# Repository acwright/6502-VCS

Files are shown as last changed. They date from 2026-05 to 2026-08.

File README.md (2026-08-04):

6502-VCS
========

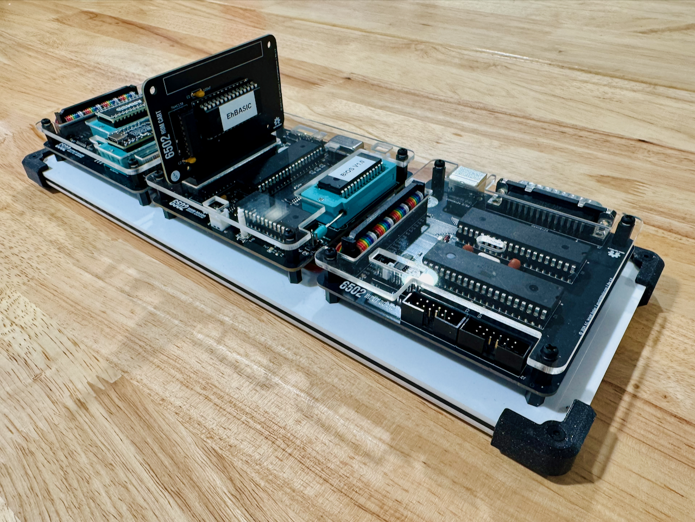
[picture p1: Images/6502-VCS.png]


An **AC6502** retro-style 8-bit computer based on the **65C02** microprocessor.

> 📖 **Guide:** [AC6502 Documentation](https://acwright.github.io/6502-DOCS/) — the user's and programmer's guide for the whole family.
> See [VCS's page in the family appendix](https://acwright.github.io/6502-DOCS/family/vcs).

---

## Table of Contents

- [Overview](#overview)
- [Architecture](#architecture)
- [Systems](#systems)
- [Software](#software)
- [Hardware](#hardware)
  - [Main Board](#main-board)
    - [Revision History](#revision-history)
  - [Input Board](#input-board)
  - [Output Board](#output-board)
  - [ROM Cart](#rom-cart)
- [Firmware](#firmware)
  - [IB Controller](#ib-controller)
- [CAD](#cad)
- [Production](#production)
- [Schematics](#schematics)
- [Libraries](#libraries)
- [Bill of Materials](#bill-of-materials)
  - [Main Board](#main-board-1)
  - [Input Board](#input-board-1)
  - [Output Board](#output-board-1)
  - [ROM Cart (Rev 1.0a)](#rom-cart-rev-10a)
  - [ROM Cart (Rev 1.0b)](#rom-cart-rev-10b)
- [License](#license)

---

## Overview

The AC6502 ecosystem is a family of open-source, 65C02-based computers sharing a common architecture, memory map, and [BIOS](https://github.com/acwright/6502-BIOS). Each computer in the family is purpose-built for a different use case but runs the same software and firmware.

The **VCS** is a cartridge-based retro gaming console. It features a real 65C02 CPU, swappable ROM cartridges, VGA video output via [Pico9918](https://github.com/visrealm/pico9918), SID audio via ARMSID, and support for PS/2 keyboards, matrix keyboards, and Atari 2600-compatible joysticks.

## Architecture

All AC6502 computers share:

- **CPU**: 65C02 (or accurate emulation)
- **Memory**: 32KB RAM + 32KB ROM, with optional banked RAM expansion
- **Memory Map**: Standardized across the ecosystem — zero page, stack, I/O space ($8000–$9FFF), system ROM, and interrupt vectors at $FFFA–$FFFF
- **Bus**: 16-bit address bus, 8-bit bidirectional data bus, standard 65C02 control signals (RW, PHI2, RESET, IRQ, NMI, RDY, SYNC)
- **BIOS**: A common [BIOS](https://github.com/acwright/6502-BIOS) provides the kernel, monitor, and BASIC interpreter across all systems

## Systems

| Project | Description |
|---|---|
| [6502-ACE](https://github.com/acwright/6502-ACE) | All-in-one Computer Experience — A single board computer |
| [6502-COB](https://github.com/acwright/6502-COB) | Computer On a Backplane — Modular desktop computer with expandable card slots |
| [6502-DEV](https://github.com/acwright/6502-DEV) | Development Environment Vehicle — Emulation-based dev system |
| [6502-KIM](https://github.com/acwright/6502-KIM) | Keypad Input Monitor - KIM-1 inspired minimal computer |
| [6502-VCS](https://github.com/acwright/6502-VCS) | Video Computer System — Cartridge-based retro gaming console (YOU ARE HERE) |

## Software

| Project | Description |
|---|---|
| [6502-BIOS](https://github.com/acwright/6502-BIOS) | The shared BIOS (kernel, monitor, BASIC) for all AC6502 computers |
| [6502-EMULATOR](https://github.com/acwright/6502-EMULATOR) | Emulator for the whole family — desktop app, browser build, and a command line for scripted runs |
| [6502-PRG](https://github.com/acwright/6502-PRG) | Template project for writing assembly language programs |
| [6502-CRT](https://github.com/acwright/6502-CRT) | Template project for writing assembly language cartridges |
| [6502-ASM](https://github.com/acwright/6502-ASM) | Assembly language example programs and demos |
| [6502-BAS](https://github.com/acwright/6502-BAS) | BASIC program listings |
| [6502-WOZMON](https://github.com/acwright/6502-WOZMON) | Wozmon as a standalone ROM |
| [6502-NOP](https://github.com/acwright/6502-NOP) | An all-NOP ROM, for probing a board during bring-up |
| [6502-DOCS](https://github.com/acwright/6502-DOCS) | The documentation site — the guide, the printable reference cards, branding and label artwork |
| [cffs](https://github.com/acwright/cffs) | Builds CompactFlash disk images for the BIOS filesystem |
| [bastok](https://github.com/acwright/bastok) | Tokenizes BASIC listings into `.prg` images, and back |
| [bin2woz](https://github.com/acwright/bin2woz) | Converts a binary into a Wozmon serial upload |

## Hardware

This repository contains KiCad 7.0+ PCB designs for the three boards that make up the VCS system.

### Main Board
`Hardware/Main Board/`

The core board containing the 65C02 CPU, 32KB SRAM, 32KB EEPROM, clock, and reset circuitry. Runs at 1 MHz and provides the bus connection for the Input and Output boards.

#### Revision History

**Rev 1.1**

- Pull-up resistors changed from 1kΩ to 10kΩ.

**Rev 1.0**

- Initial release.

### Input Board
`Hardware/Input Board/`

Unified input board supporting a matrix keyboard, PS/2 keyboard, and Atari 2600-compatible joysticks. Uses a 65C22 VIA and an ATmega1284p microcontroller as the keyboard encoder controller.

The joysticks share the VIA ports with the keyboard encoder rather than having connectors of their own: they come in on the `J1` PORT B and `J2` PORT A box headers, with `JOY(1)` reading PORT B and `JOY(2)` reading PORT A. See [Joystick Interface](./Firmware/IB%20Controller/README.md#joystick-interface) for the wiring options and the bitmask the BIOS returns.

### Output Board
`Hardware/Output Board/`

Combined VGA video output (via Raspberry Pi Pico running [Pico9918](https://github.com/visrealm/pico9918)) and SID audio output (via ARMSID). Provides TMS9918A-compatible graphics modes at 640×480 VGA and 3-voice SID synthesis.

### ROM Cart
`Hardware/ROM Cart/`

Swappable ROM cartridge for the VCS system. Comes in two versions:

- **Rev 1.0a** — Uses the **28C256** 32KB EEPROM (electrically erasable, no UV eraser required).
- **Rev 1.0b** — Uses the **27C256** 32KB EPROM (UV-erasable).

## Firmware

This repository contains [PlatformIO](https://platformio.org/)-based firmware for the Input Board.

### IB Controller
`Firmware/IB Controller/`

Firmware for the ATmega1284p on the Input Board. Provides:

- Matrix keyboard scanning and encoding
- PS/2 keyboard interface
- Atari 2600-compatible joystick input
- Parallel I/O to the AC6502 bus via 65C22 VIA

See [Firmware/IB Controller/README.md](./Firmware/IB%20Controller/README.md) for setup and usage instructions.

## CAD
`CAD/`

3D-printable enclosure parts and laser-cut top panels for the VCS system.

## Production
`Production/`

JLCPCB-ready Gerber files and BOM/CPL for PCB fabrication and assembly.

## Schematics
`Schematics/`

PDF schematics for each board.

## Libraries
`Libraries/`

Shared KiCad symbol and footprint libraries used across all AC6502 hardware projects.

## Bill of Materials

### Main Board

| Reference | Qty | Value | Description | LCSC | DigiKey | Mouser | Other |
|---|-----|---|---|---|---|---|---|
| C1, C3–C11 | 10 | 100nF | Unpolarized capacitor | [C49678](https://www.lcsc.com/search?q=C49678) | | | |
| C2 | 1 | 10uF | Polarized capacitor | [C7171](https://www.lcsc.com/search?q=C7171) | | | |
| D1 | 1 | 1N5819 | Schottky Diode SOD-323F | [C191023](https://www.lcsc.com/search?q=C191023) | | | |
| D2 | 1 | LED | LED 0805 | [C2297](https://www.lcsc.com/search?q=C2297) | | | |
| J1 | 1 | PWR_SW | JST XH 1×2 | | [455-2247-ND](https://www.digikey.com/en/products/filter?keywords=455-2247-ND) | | |
| J2 | 1 | ROM WE | Pin Header 1×2 | | | | [AMAZON](https://www.amazon.com/Straight-Breakaway-Connector-Breadboard-Electronic/dp/B0FRZW75VS) |
| J3 | 1 | USB-C | USB 2.0 Type-C Receptacle | [C2988369](https://www.lcsc.com/search?q=C2988369) | | | |
| J4 | 1 | RESET_SW | JST XH 1×2 | | [455-2247-ND](https://www.digikey.com/en/products/filter?keywords=455-2247-ND) | | |
| J5 | 1 | HRDB EN | Pin Header 2×2 | | | | [AMAZON](https://www.amazon.com/Uxcell-Double-Straight-Header-Strip/dp/B00X77A472) |
| J6 | 1 | CLOCK_ENBL_SW | JST XH 1×2 | | [455-2247-ND](https://www.digikey.com/en/products/filter?keywords=455-2247-ND) | | |
| J7 | 1 | 6502 EN | Pin Header 1×2 | | | | [AMAZON](https://www.amazon.com/Straight-Breakaway-Connector-Breadboard-Electronic/dp/B0FRZW75VS) |
| J8 | 1 | EXP EN | Pin Header 2×5 | | | | [AMAZON](https://www.amazon.com/Uxcell-Double-Straight-Header-Strip/dp/B00X77A472) |
| J9 | 1 | 6502 Card Connector | Card Edge 2×20 | | [A31723-ND](https://www.digikey.com/en/products/filter?keywords=A31723-ND) | [571-5-5530843-4](https://www.mouser.com/ProductDetail/571-5-5530843-4) | |
| J10 | 1 | 6502 Bus | Bus Connector 2×20 | | | | [AMAZON](https://www.amazon.com/Female-Headers-Connector-Header-Raspberry/dp/B07DNHS2SJ) |
| Q1 | 1 | SS8050 | NPN Transistor SOT-23 | [C2150](https://www.lcsc.com/search?q=C2150) | | | |
| R1, R4, R9 | 3 | 1k | Resistor | [C17513](https://www.lcsc.com/search?q=C17513) | | | |
| R10–R14 | 5 | 10k | Resistor | [C2930231](https://www.lcsc.com/search?q=C2930231) | | | |
| R2 | 1 | 1M | Resistor | [C17514](https://www.lcsc.com/search?q=C17514) | | | |
| R3 | 1 | 47k | Resistor | [C17713](https://www.lcsc.com/search?q=C17713) | | | |
| R5, R6 | 2 | 5.1k | Resistor | [C27834](https://www.lcsc.com/search?q=C27834) | | | |
| R7 | 1 | 330 | Resistor | [C17630](https://www.lcsc.com/search?q=C17630) | | | |
| R8 | 1 | 10k | Resistor | [C17414](https://www.lcsc.com/search?q=C17414) | | | |
| SW1 | 1 | Reset | Push Button | [C318884](https://www.lcsc.com/search?q=C318884) | | | |
| U1 | 1 | LM555xM | Timer SOIC-8 | [C7593](https://www.lcsc.com/search?q=C7593) | | | |
| U2 | 1 | AS6C62256 | SRAM DIP-28 | | [1450-1033-ND](https://www.digikey.com/en/products/filter?keywords=1450-1033-ND) | [913-AS6C62256-55PCN](https://www.mouser.com/ProductDetail/913-AS6C62256-55PCN) | |
| U3 | 1 | AT28C256 | EEPROM DIP-28 | | [AT28C256-15PU-ND](https://www.digikey.com/en/products/filter?keywords=AT28C256-15PU-ND) | [556-AT28C25615PU](https://www.mouser.com/ProductDetail/556-AT28C25615PU) | |
| U4, U5, U7 | 3 | 74HC00 | Quad NAND SOIC-14 | [C5586](https://www.lcsc.com/search?q=C5586) | | | |
| U6 | 1 | 65C02 | CPU DIP-40 | | | [955-W65C02S6TPG-14](https://www.mouser.com/ProductDetail/955-W65C02S6TPG-14) | |
| X1 | 1 | OCXO-14 | Crystal Oscillator DIP-14 | | [X937-ND](https://www.digikey.com/en/products/filter?keywords=X937-ND) | | |

### Input Board

| Reference | Qty | Value | Description | LCSC | DigiKey | Mouser | Other |
|---|-----|---|---|---|---|---|---|
| C1, C3, C5–C8 | 6 | 100nF | Unpolarized capacitor | [C49678](https://www.lcsc.com/search?q=C49678) | | | |
| C2, C4 | 2 | 22pF | Unpolarized capacitor | [C107114](https://www.lcsc.com/search?q=C107114) | | | |
| D1 | 1 | 1N914 | Schottky Diode | | [1N914FS-ND](https://www.digikey.com/en/products/filter?keywords=1N914FS-ND) | | |
| J1 | 1 | PORT B | Box Header 2×6 | | [2057-BHR-12-VUA-ND](https://www.digikey.com/en/products/filter?keywords=2057-BHR-12-VUA-ND) | | [AMAZON](https://www.amazon.com/uxcell-2-54mm-2x6-Pin-Straight-Connector/dp/B07DJYVZV2) |
| J2 | 1 | PORT A | Box Header 2×6 | | [2057-BHR-12-VUA-ND](https://www.digikey.com/en/products/filter?keywords=2057-BHR-12-VUA-ND) | | [AMAZON](https://www.amazon.com/uxcell-2-54mm-2x6-Pin-Straight-Connector/dp/B07DJYVZV2) |
| J3 | 1 | PS/2 KEYBOARD | 6-pin Mini-DIN | | | [806-KMDGX-6S-BS](https://www.mouser.com/ProductDetail/806-KMDGX-6S-BS) | [AMAZON](https://www.amazon.com/dp/B08GS3QL7T) |
| J4 | 1 | 6502 Bus | Bus Connector 2×20 | | | | [AMAZON](https://www.amazon.com/Female-Headers-Connector-Header-Raspberry/dp/B07DNHS2SJ) |
| J5 | 1 | KEYBOARD | DB-25 Connector | | [609-1505-ND](https://www.digikey.com/en/products/filter?keywords=609-1505-ND) | | |
| J6 | 1 | IO SELECT | Pin Header 2×8 | | | | [AMAZON](https://www.amazon.com/Uxcell-Double-Straight-Header-Strip/dp/B00X77A472) |
| R1 | 1 | 1K | Resistor | [C17513](https://www.lcsc.com/search?q=C17513) | | | |
| U1 | 1 | 65C22 | VIA DIP-40 | | | [955-W65C22N6TPG-14](https://www.mouser.com/ProductDetail/955-W65C22N6TPG-14) | |
| U2 | 1 | ATmega1284-P | MCU DIP-40 | | [ATMEGA1284-PU-ND](https://www.digikey.com/en/products/filter?keywords=ATMEGA1284-PU-ND) | [556-ATMEGA1284-PU](https://www.mouser.com/ProductDetail/556-ATMEGA1284-PU) | |
| U3 | 1 | 74HC138 | Decoder SOIC-16 | [C5602](https://www.lcsc.com/search?q=C5602) | | | |
| Y1 | 1 | 16 MHz | Crystal HC49-U | | [3155-16M20P2/49US-ND](https://www.digikey.com/en/products/filter?keywords=3155-16M20P2/49US-ND) | | |

> **Joysticks**: there is no DB-9 in this BOM because the board does not carry one. The joysticks share the VIA ports with the keyboard encoder and connect through the `J1` PORT B and `J2` PORT A box headers, using a helper board from the [6502-COB](https://github.com/acwright/6502-COB) project — the **GPIO Helper** for a direct box-header connection, or the **Joystick Helper** to convert a port to a DB-9 with pull-ups fitted. Budget for one helper per stick.

### Output Board

| Reference | Qty | Value | Description | LCSC | DigiKey | Mouser | Other |
|---|-----|---|---|---|---|---|---|
| C1 | 1 | 1uF | Capacitor | [C28323](https://www.lcsc.com/search?q=C28323) | | | |
| C2, C3 | 2 | 2.2nF | Capacitor | [C28260](https://www.lcsc.com/search?q=C28260) | | | |
| C5–C10 | 6 | 100nF | Unpolarized capacitor | [C49678](https://www.lcsc.com/search?q=C49678) | | | |
| D1 | 1 | 1N914 | Schottky Diode | | [1N914FS-ND](https://www.digikey.com/en/products/filter?keywords=1N914FS-ND) | | |
| J1 | 1 | VDD | JST XH 1×2 | | [455-2247-ND](https://www.digikey.com/en/products/filter?keywords=455-2247-ND) | | |
| J2 | 1 | AUDIO | RCA Connector | | [PJRAN1X1U02X-ND](https://www.digikey.com/en/products/filter?keywords=PJRAN1X1U02X-ND) | | |
| J6 | 1 | INT Select | Pin Header 1×3 | | | | [AMAZON](https://www.amazon.com/Straight-Breakaway-Connector-Breadboard-Electronic/dp/B0FRZW75VS) |
| J7 | 1 | IO SELECT | Pin Header 2×8 | | | | [AMAZON](https://www.amazon.com/Uxcell-Double-Straight-Header-Strip/dp/B00X77A472) |
| J8 | 1 | 6502 Bus | Bus Connector 2×20 | | | | [AMAZON](https://www.amazon.com/Female-Headers-Connector-Header-Raspberry/dp/B07DNHS2SJ) |
| R1 | 1 | 1k | Resistor | [C17513](https://www.lcsc.com/search?q=C17513) | | | |
| U1 | 1 | Pico9918A | Video Chip DIP-40 | | | | [LINK](https://www.tindie.com/products/visrealm/pico9918-pro/) |
| U2 | 1 | 6581 | SID Chip DIP-28 | | | | [LINK](https://retrocomp.cz/produkt?id=2) |
| U3, U4 | 2 | 74HC138 | Decoder SOIC-16 | [C5602](https://www.lcsc.com/search?q=C5602) | | | |

### ROM Cart (Rev 1.0a)

| Reference | Qty | Value | Description | DigiKey | Mouser | Other |
|---|-----|---|---|---|---|---|
| C1, C2 | 2 | 100nF | Capacitor | [478-5732-ND](https://www.digikey.com/en/products/filter?keywords=478-5732-ND) | | [AMAZON](https://www.amazon.com/PANMILED-Multilayer-Monolithic-Capacitors-Assortment/dp/B0CYQ1Z4G5) |
| U1 | 1 | AT28C256 | EEPROM DIP-28 | [AT28C256-15PU-ND](https://www.digikey.com/en/products/filter?keywords=AT28C256-15PU-ND) | [556-AT28C25615PU](https://www.mouser.com/ProductDetail/556-AT28C25615PU) | |
| U2 | 1 | 74HC138 | Decoder DIP-16 | [296-1575-5-ND](https://www.digikey.com/en/products/filter?keywords=296-1575-5-ND) | [595-SN74HC138N](https://www.mouser.com/ProductDetail/595-SN74HC138N) | |

### ROM Cart (Rev 1.0b)

| Reference | Qty | Value | Description | DigiKey | Mouser | Other |
|---|-----|---|---|---|---|---|
| C1, C2 | 2 | 100nF | Capacitor | [478-5732-ND](https://www.digikey.com/en/products/filter?keywords=478-5732-ND) | | [AMAZON](https://www.amazon.com/PANMILED-Multilayer-Monolithic-Capacitors-Assortment/dp/B0CYQ1Z4G5) |
| U1 | 1 | AT27C256 | EPROM DIP-28 | [AT27C256R-70PU-ND](https://www.digikey.com/en/products/filter?keywords=AT27C256R-70PU-ND) | | [LINK](https://www.jameco.com/z/AM27C256-255DC-Advanced-Micro-Devices-IC-27C256-25-EPROM-256K-Bit-250ns-CMOS-UV-Electrically-Programmable-ROM_39731.html) |
| U2 | 1 | 74HC138 | Decoder DIP-16 | [296-1575-5-ND](https://www.digikey.com/en/products/filter?keywords=296-1575-5-ND) | [595-SN74HC138N](https://www.mouser.com/ProductDetail/595-SN74HC138N) | |

## License

Hardware designs are released under the [CERN Open Hardware Licence Version 2 – Permissive](https://ohwr.org/cern_ohl_p_v2.txt).  
Firmware is released under the [MIT License](./Firmware/IB%20Controller/LICENSE).

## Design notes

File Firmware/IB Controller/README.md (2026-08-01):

# IB Controller

## Overview

The IB (Input Board) Controller is firmware for the ATMega1284P microcontroller that provides dual keyboard input support for 6502-based computer systems. It can simultaneously handle both PS/2 keyboard input and custom keyboard matrix input, converting keypresses to ASCII codes and outputting them through a 6522 VIA (Versatile Interface Adapter) interface.

## Features

- **Dual Input Support**: Handles both PS/2 keyboards and 8x8 keyboard matrix simultaneously
- **ASCII Conversion**: Converts PS/2 scancodes and matrix keypresses to ASCII characters
- **Always Uppercase Letters**: Letters are always output as uppercase ASCII regardless of modifiers
- **Modifier Keys**: Shift (symbols/numbers only) and Ctrl (control codes)
- **Buffered Input**: Uses circular buffers to prevent data loss during rapid typing
- **Debounced Matrix Scanning**: Hardware debouncing for reliable matrix keyboard operation
- **Enable/Disable Control**: Independent enable signals for PS/2 and matrix inputs
- **Shared Joystick Ports**: Releases PORT A / PORT B when disabled so the 6502 can read the two Atari 2600-compatible joysticks that share those ports

## Hardware Connections

### ATMega1284P Pin Assignments

#### VIA PORT A (Pins 24-31)
Used for row scanning (matrix mode) or ASCII output (PS/2 mode):
- PA0 (Pin 24) - VIA_PA0 / Row 0 / Data Bit 0
- PA1 (Pin 25) - VIA_PA1 / Row 1 / Data Bit 1
- PA2 (Pin 26) - VIA_PA2 / Row 2 / Data Bit 2
- PA3 (Pin 27) - VIA_PA3 / Row 3 / Data Bit 3
- PA4 (Pin 28) - VIA_PA4 / Row 4 / Data Bit 4
- PA5 (Pin 29) - VIA_PA5 / Row 5 / Data Bit 5
- PA6 (Pin 30) - VIA_PA6 / Row 6 / Data Bit 6
- PA7 (Pin 31) - VIA_PA7 / Row 7 / Data Bit 7

#### VIA PORT B (Pins 0-7)
Used for column scanning (matrix mode) or ASCII output (matrix output):
- PB0 (Pin 0) - VIA_PB0 / Column 0 / Data Bit 0
- PB1 (Pin 1) - VIA_PB1 / Column 1 / Data Bit 1
- PB2 (Pin 2) - VIA_PB2 / Column 2 / Data Bit 2
- PB3 (Pin 3) - VIA_PB3 / Column 3 / Data Bit 3
- PB4 (Pin 4) - VIA_PB4 / Column 4 / Data Bit 4
- PB5 (Pin 5) - VIA_PB5 / Column 5 / Data Bit 5
- PB6 (Pin 6) - VIA_PB6 / Column 6 / Data Bit 6
- PB7 (Pin 7) - VIA_PB7 / Column 7 / Data Bit 7

#### Control Signals
- Pin 8 (VIA_CA1) - PS/2 Data Ready strobe (output)
- Pin 9 (VIA_CA2) - PS/2 Enable (input, active low)
- Pin 10 (PS2CLK) - PS/2 Clock input
- Pin 11 (PS2DATA) - PS/2 Data input
- Pin 12 (VIA_CB1) - Matrix Data Ready strobe (output)
- Pin 13 (VIA_CB2) - Matrix Enable (input, active low)

### PS/2 Keyboard Interface

Connect a PS/2 keyboard to:
- **CLK**: Pin 10 (PS2CLK)
- **DATA**: Pin 11 (PS2DATA)
- **VCC**: +5V
- **GND**: Ground

### Keyboard Matrix Interface

The firmware supports an 8x8 keyboard matrix (64 keys maximum):
- **Rows**: Connected to PA0-PA7 (Pins 24-31)
- **Columns**: Connected to PB0-PB7 (Pins 0-7)

Each key connects a row to a column when pressed. The matrix is scanned with rows driven low and columns read with pull-ups.

### Joystick Interface

PORT A and PORT B are shared between this encoder and two Atari 2600-compatible
joysticks. The Input Board has no DB-9 connectors of its own — the sticks arrive
on the same 2×6 box headers that carry the VIA ports (`J1` PORT B, `J2` PORT A),
using either helper board from the [6502-COB](https://github.com/acwright/6502-COB)
project:

- **GPIO Helper** — box header to box header, for wiring a stick directly to a port.
- **Joystick Helper** — converts a port header to a DB-9 with the 1kΩ pull-ups
  fitted, which is where Atari 2600 compatibility comes from.

The BIOS reads the two sticks through those same ports:

| BIOS routine | BASIC | VIA port | Encoder released by |
|---|---|---|---|
| `ReadJoystick1` (`$A048`) | `JOY(1)` | PORT B | `CB2` high — matrix encoder off |
| `ReadJoystick2` (`$A04B`) | `JOY(2)` | PORT A | `CA2` high — PS/2 encoder off |

Each read returns the port raw, as a bitmask:

```
Bit:  7   6   5   4   3   2   1   0
      R   L   D   U   Y   X   B   A
```

The ports are **active low** — every line is pulled high and grounded by the
stick's switch — so a held button reads `0` and an untouched stick reads `$FF`.

This is the firmware's obligation in the joystick path: when `CA2` or `CB2`
goes high, it releases the corresponding port within 100 µs so the 6502 can
read the stick directly — the same arrangement a C64 has with a CIA port.
`disablePS2()` releases PORT A and `disableMatrix()` releases PORT B, both by
returning the pins to `INPUT_PULLUP` rather than bare `INPUT`. That matters
here in particular, since the Input Board has no pull-ups of its own — see the
helper board list above — so a port can legitimately be assembled with none
fitted at all.

The BIOS reads a stick as `KBDisable` → settle → read the port directly →
`KBEnable`. Nothing is transmitted over the shared lines, so there is nothing
for one stick to corrupt on the other's behalf — **both sticks read correctly
even when held at the same time.** An earlier design had the encoder push
joystick state to the 6502 as control bytes over the keyboard channel instead;
that could not report a held button on the port it was reporting over, and was
abandoned. See
[BIOS `PLAN.md` §2](https://github.com/acwright/6502-BIOS/blob/main/PLAN.md)
for the full account.

A cartridge that wants its own matrix scan, its own key repeat, or polling
faster than the encoder's rate can use the identical mechanism directly:
`KBDisable`, own the sixteen pins for as long as it likes, `KBEnable` when
done. It is not a separate escape hatch — it is what `ReadJoystick1/2` already
do on every call.

**Measured release latency: to be measured later.** This is the figure the
BIOS's `KBDisable` settle wait is sized against. Cycle-counting the compiled
firmware puts the worst-case code path at ~17 µs against a 100 µs budget, but
that excludes a PS/2 interrupt landing in the window and says nothing about how
long the bus takes to charge through a pull-up, so the published number comes
from a scope. See [PLAN.md](../../PLAN.md).

## Keyboard Matrix Layout

```
       PB0    PB1    PB2    PB3    PB4    PB5    PB6    PB7
PA0:    `      1      2      3      4      5      6      7
PA1:    8      9      0      -      =      BS     ESC    TAB
PA2:    Q      W      E      R      T      Y      U      I
PA3:    O      P      [      ]      \      INS    CAPS   A
PA4:    S      D      F      G      H      J      K      L
PA5:    ;      '    ENTER   DEL   SHIFT    Z      X      C
PA6:    V      B      N      M      ,      .      /      UP
PA7:  CTRL   MENU    ALT   SPACE   FN    LEFT   DOWN  RIGHT
```

**Special Keys:**
- BS = Backspace (0x08)
- ESC = Escape (0x1B)
- TAB = Tab (0x09)
- INS = Insert (0x1A)
- DEL = Delete (0x7F)
- ENTER = Enter (0x0D)
- Arrow keys: UP (0x1E), LEFT (0x1C), DOWN (0x1F), RIGHT (0x1D)

**Ignored Keys:**
- Caps Lock, Menu/GUI, Alt, Fn — produce no output and track no state

## Operation Modes

### PS/2 Mode
When VIA_CA2 (Pin 9) is pulled LOW:
- PS/2 keyboard is enabled
- Scancodes are converted to ASCII
- Output appears on PORT A (PA0-PA7)
- VIA_CA1 pulses low when data is ready

### Matrix Mode
When VIA_CB2 (Pin 13) is pulled LOW:
- Matrix keyboard is enabled
- Matrix is scanned every 10ms
- Keys are debounced (stable for 2 scans)
- Output appears on PORT B (PB0-PB7)
- VIA_CB1 pulses low when data is ready

### Dual Mode
Both keyboards can operate simultaneously if both enable signals are active.

### Joystick Reads
When an enable signal goes HIGH the firmware releases that port so the joystick
sharing it can be read by the 6502 — see [Joystick Interface](#joystick-interface).

## ASCII Character Mapping

### Modifier Priority

1. **Ctrl** — If held, produce control code. Shift is ignored.
2. **Shift** — If held (no Ctrl), produce shifted symbol. Letters unaffected.
3. **Base** — No modifier: produce base ASCII (letters always uppercase).

### Control Characters (Ctrl+Key)

- Ctrl+2 = 0x00 (NUL)
- Ctrl+A-Z = 0x01-0x1A
- Ctrl+[ = 0x1B (ESC)
- Ctrl+\ = 0x1C (FS)
- Ctrl+] = 0x1D (GS)
- Ctrl+6 = 0x1E (RS)
- Ctrl+- = 0x1F (US)

### Shifted Symbols

Shift only affects number and symbol keys (not letters):

| Base | Shifted | | Base | Shifted |
|---|---|-|---|---|
| 1 → ! | 2 → @ | | 3 → # | 4 → $ |
| 5 → % | 6 → ^ | | 7 → & | 8 → * |
| 9 → ( | 0 → ) | | - → _ | = → + |
| [ → { | ] → } | | \ → \| | ; → : |
| ' → " | , → < | | . → > | / → ? |
| ` → ~ | | | | |

### Printable Characters

Letters are always uppercase (A-Z). Numbers, symbols, space, and navigation keys follow standard ASCII.

## Build Instructions

### Prerequisites

1. **Install PlatformIO**
   ```bash
   # Using pip
   pip install platformio
   
   # Or install PlatformIO IDE extension for VS Code
   ```

2. **Install MiniPro Programmer Software** (for uploading)
   ```bash
   # macOS (using Homebrew)
   brew install minipro
   
   # Linux
   sudo apt-get install minipro
   
   # Or build from source: https://gitlab.com/DavidGriffith/minipro
   ```

### Building the Firmware

1. **Navigate to the project directory:**
   ```bash
   cd "Firmware/IB Controller"
   ```

2. **Build the firmware:**
   ```bash
   # Build for ATMega1284P (default)
   pio run -e atmega1284p
   
   # Or build for ATMega1284
   pio run -e atmega1284
   ```

3. **Build output:**
   The compiled firmware will be located at:
   ```
   .pio/build/atmega1284p/firmware.hex
   ```

### Uploading the Firmware

The project uses a MiniPro TL866 programmer for uploading.

1. **Connect the MiniPro programmer** to your ATMega1284P chip

2. **Upload firmware and fuses:**
   ```bash
   # Upload to ATMega1284P
   pio run -e atmega1284p -t upload
   
   # Or upload to ATMega1284
   pio run -e atmega1284 -t upload
   ```

3. **Manual upload (if needed):**
   ```bash
   # Flash the program
   minipro -p "ATMEGA1284P@DIP40" -c code -w .pio/build/atmega1284p/firmware.hex
   
   # Flash the fuses
   minipro -p "ATMEGA1284P@DIP40" -c config -w fuses.cfg --fuses
   ```

## Fuse Configuration

The `fuses.cfg` file contains the ATMega1284P fuse settings:

```properties
lfuse = 0xff   # Low fuse
hfuse = 0xff   # High fuse  
efuse = 0xff   # Extended fuse
lock = 0xff    # Lock bits (unprogrammed, not written)
```

**Fuse Settings:**
- **Low Fuse (0xFF)**: Low power crystal oscillator (8.0–16.0 MHz) for the
  on-board 16 MHz crystal (`Y1`), slowly-rising-power start-up (16K CK + 65 ms),
  no clock divide (CKDIV8 off), clock output disabled
- **High Fuse (0xFF)**: Default settings
- **Extended Fuse (0xFF)**: Default settings
- **Lock Bits (0xFF)**: No memory lock protection

> **Note**: The low fuse selects a *crystal* oscillator, which is what this board
> needs — the Input Board carries a 16 MHz HC49-U crystal across XTAL1/XTAL2.
> Full Swing is a different setting (`CKSEL3:1 = 011`) and is not used here. The
> ACE board's `AB Controller` runs from a full-can oscillator module instead and
> therefore uses the *external clock* setting (`lfuse = 0xE0`); the two are not
> interchangeable.

> **Note**: Lock bits are left unprogrammed on all of these boards. The upload
> command writes fuses only (`--fuses`, no `--lock`), so the `lock` line above is
> recorded for reference and never programmed.

⚠️ **Warning**: Incorrect fuse settings can brick your microcontroller. Verify fuse values are appropriate for your hardware configuration before programming.

## Dependencies

The firmware requires the following library (automatically installed by PlatformIO):

- **CircularBuffer** (v1.4.0+) by Roberto Lo Giacco
  - Provides interrupt-safe circular buffers for keyboard data

## Project Structure

```
IB Controller/
├── platformio.ini          # PlatformIO configuration
├── fuses.cfg              # AVR fuse configuration
├── src/
│   └── main.cpp           # Main firmware source code
├── include/               # Header files (if any)
├── lib/                   # Local libraries
└── test/                  # Unit tests
```

## Troubleshooting

### Build Issues

**Problem**: PlatformIO not found
```bash
# Solution: Install or update PlatformIO
pip install -U platformio
```

**Problem**: Library dependency errors
```bash
# Solution: Clean and rebuild
pio run -t clean
pio run
```

### Upload Issues

**Problem**: MiniPro not found
```bash
# Solution: Ensure minipro is installed and in PATH
which minipro
```

**Problem**: Chip not detected
- Check that the chip is properly seated in the programmer
- Verify you're using the correct chip model (ATMEGA1284P vs ATMEGA1284)
- Check for proper power supply to the programmer

### Runtime Issues

**Problem**: No keyboard response
- Verify enable signals (CA2/CB2) are at correct logic levels
- Check PS/2 clock and data connections
- Verify matrix keyboard connections
- Ensure VIA interface connections are correct

**Problem**: `JOY(1)`/`JOY(2)` return keystrokes or a stuck value
- Confirm the BIOS is v1.5 or later — older BIOS reads the port before the
  encoder has released it (see [Joystick Interface](#joystick-interface))
- Verify the stick's pull-ups are present (the Joystick Helper carries them; a
  bare box-header connection does not)

**Problem**: Incorrect characters output
- Check for proper pull-up resistors on PS/2 lines
- Verify keyboard matrix wiring matches the defined layout
- Test with a known-good PS/2 keyboard

## License

See the main repository LICENSE file for licensing information.

## Contributing

This firmware is part of the 6502 computer project. Contributions and improvements are welcome through the main repository.

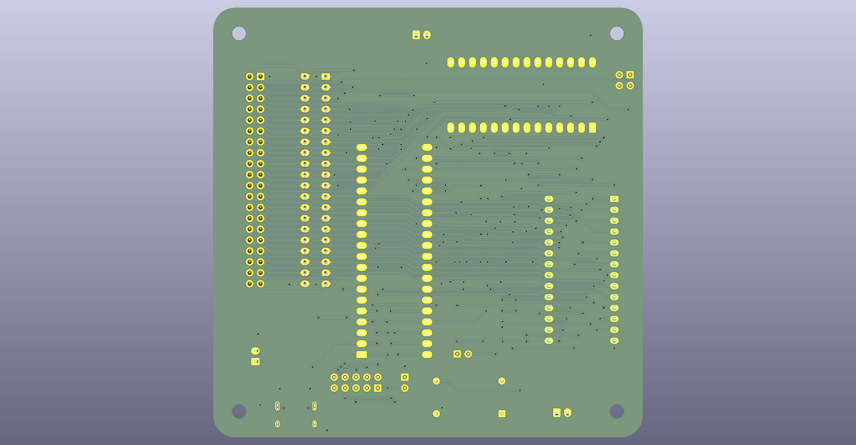
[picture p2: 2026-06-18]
CAD/Images/Main Board/Rev 1.1/Back.png

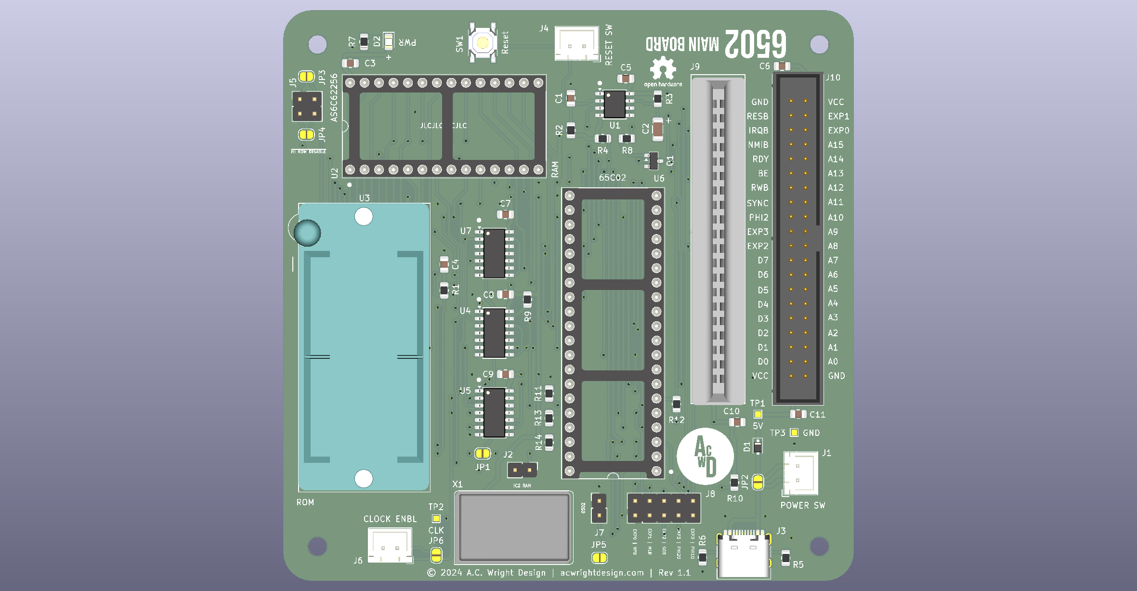
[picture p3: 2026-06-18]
CAD/Images/Main Board/Rev 1.1/Front.png

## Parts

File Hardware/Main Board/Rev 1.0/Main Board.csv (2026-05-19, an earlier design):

Reference | Qty | Value | Description | Footprint | LCSC | Digikey | Mouser | Other
C1,C3,C4,C5,C6,C7,C8,C9,C10,C11 | 10 | 100nF | Unpolarized capacitor | Capacitor_SMD:C_0805_2012Metric | C49678
C2 | 1 | 10uF | Polarized capacitor | Capacitor_SMD:C_1206_3216Metric | C7171
D1 | 1 | 1N5819 | 40V 1A Schottky Barrier Rectifier Diode, DO-41 | Diode_SMD:D_SOD-323F | C191023
D2 | 1 | LED | Light emitting diode | LED_SMD:LED_0805_2012Metric | C2297
J1 | 1 | PWR_SW | Generic connector, single row, 01x02, script generated (kicad-library-utils/schlib/autogen/connector/) | Connector_JST:JST_XH_B2B-XH-A_1x02_P2.50mm_Vertical |  | 455-2247-ND
J2 | 1 | ROM WE |  | Connector_PinHeader_2.54mm:PinHeader_1x02_P2.54mm_Vertical |  |  |  | https://www.amazon.com/Straight-Breakaway-Connector-Breadboard-Electronic/dp/B0FRZW75VS
J3 | 1 | USB_C_Receptacle_USB2.0 | USB 2.0-only 16P Type-C Receptacle connector | Connector_USB:USB_C_Receptacle_HRO_TYPE-C-31-M-12 | C2988369
J4 | 1 | RESET_SW | Generic connector, single row, 01x02, script generated (kicad-library-utils/schlib/autogen/connector/) | Connector_JST:JST_XH_B2B-XH-A_1x02_P2.50mm_Vertical |  | 455-2247-ND
J5 | 1 | HRDB EN |  | Connector_PinHeader_2.54mm:PinHeader_2x02_P2.54mm_Vertical |  |  |  | https://www.amazon.com/Uxcell-Double-Straight-Header-Strip/dp/B00X77A472
J6 | 1 | CLOCK_ENBL_SW | Generic connector, single row, 01x02, script generated (kicad-library-utils/schlib/autogen/connector/) | Connector_JST:JST_XH_B2B-XH-A_1x02_P2.50mm_Vertical |  | 455-2247-ND
J7 | 1 | 6502 EN | Generic connector, single row, 01x02, script generated (kicad-library-utils/schlib/autogen/connector/) | Connector_PinHeader_2.54mm:PinHeader_1x02_P2.54mm_Vertical |  |  |  | https://www.amazon.com/Straight-Breakaway-Connector-Breadboard-Electronic/dp/B0FRZW75VS
J8 | 1 | EXP EN | Generic connector, double row, 02x05, odd/even pin numbering scheme (row 1 odd numbers, row 2 even numbers), script generated (kicad-library-utils/schlib/autogen/connector/) | Connector_PinHeader_2.54mm:PinHeader_2x05_P2.54mm_Vertical |  |  |  | https://www.amazon.com/Uxcell-Double-Straight-Header-Strip/dp/B00X77A472
J9 | 1 | 6502 Card Connector | Generic connector, double row, 02x20, odd/even pin numbering scheme (row 1 odd numbers, row 2 even numbers), script generated (kicad-library-utils/schlib/autogen/connector/) | 6502 Parts:RHDR40W82P485X254_2X20_5740X93 |  | A31723-ND | 571-5-5530843-4
J10 | 1 | 6502 Bus | Generic connector, double row, 02x20, odd/even pin numbering scheme (row 1 odd numbers, row 2 even numbers), script generated (kicad-library-utils/schlib/autogen/connector/) | 6502 Parts:6502 Bus Connector |  |  |  | https://www.amazon.com/Female-Headers-Connector-Header-Raspberry/dp/B07DNHS2SJ
Q1 | 1 | SS8050 | NPN transistor, base/emitter/collector | Package_TO_SOT_SMD:SOT-23 | C2150
R1,R4,R9,R10,R11,R12,R13,R14 | 8 | 1k | Resistor | Resistor_SMD:R_0805_2012Metric | C17513
R2 | 1 | 1M | Resistor | Resistor_SMD:R_0805_2012Metric | C17514
R3 | 1 | 47k | Resistor | Resistor_SMD:R_0805_2012Metric | C17713
R5,R6 | 2 | 5.1k | Resistor | Resistor_SMD:R_0805_2012Metric | C27834
R7 | 1 | 330 | Resistor | Resistor_SMD:R_0805_2012Metric | C17630
R8 | 1 | 10k | Resistor | Resistor_SMD:R_0805_2012Metric | C17414
SW1 | 1 | Reset | Push button switch, generic, two pins | 6502 Parts:SW_TS-1187A-B-A-B | C318884
U1 | 1 | LM555xM | Timer, 555 compatible, SOIC-8 | Package_SO:SOIC-8_3.9x4.9mm_P1.27mm | C7593
U2 | 1 | AS6C62256 |  | Package_DIP:DIP-28_W15.24mm_Socket_LongPads |  | 1450-1033-ND | 913-AS6C62256-55PCN
U3 | 1 | AT28C256 |  | Socket:DIP_Socket-28_W11.9mm_W12.7mm_W15.24mm_W17.78mm_W18.5mm_3M_228-1277-00-0602J |  | AT28C256-15PU-ND | 556-AT28C25615PU
U4,U5,U7 | 3 | 74HC00 |  | Package_SO:SOIC-14_3.9x8.7mm_P1.27mm | C5586
U6 | 1 | 65C02 |  | Package_DIP:DIP-40_W15.24mm_Socket_LongPads |  |  | 955-W65C02S6TPG-14
X1 | 1 | OCXO-14 | Voltage-Controlled Crystal Clock Oscillator, DIP14-style metal package | Oscillator:Oscillator_DIP-14 |  | X937-ND

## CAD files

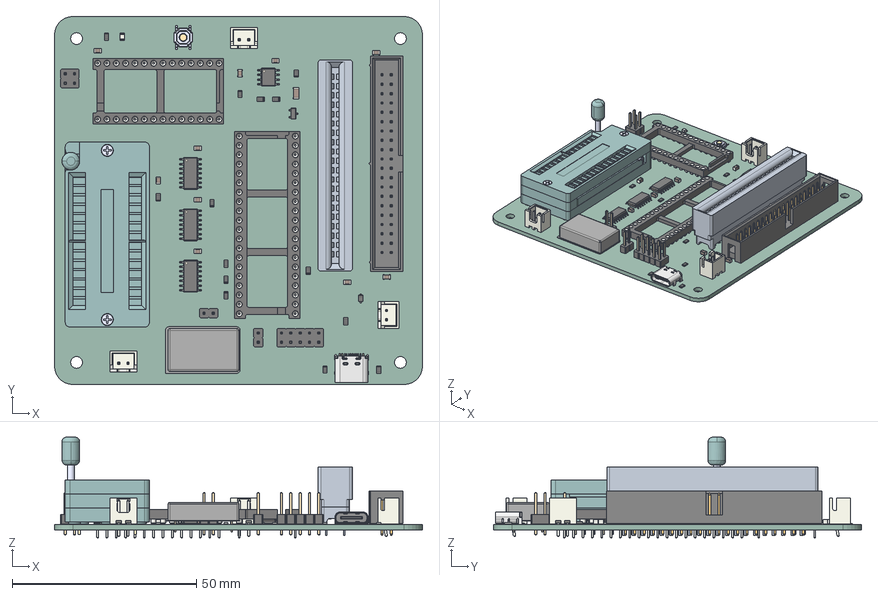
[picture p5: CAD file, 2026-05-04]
CAD/Models/Main Board/Rev 1.1/Main Board.step
100.0 x 100.0 x 27.4 mm
C_0805_2012Metric x 10
LED_0805_2012Metric
ConPins
PcbPins
Mold
Frame
JST_XH_B2B-XH-A_1x02_P2.50mm_Vertical x 3
R_0805_2012Metric x 14
SOIC-8_3.9x4.9mm_P1.27mm
6120xx21621_PIN x 40
TS-1187A-B-A-B
C_1206_3216Metric
PinHeader_1x02_P2.54mm_Vertical x 2
SOT-23
SOIC-14_3.9x8.7mm_P1.27mm x 3
D_SOD-323F
PinHeader_2x05_P2.54mm_Vertical
228-1277-00-0602J
DIP-28_W15.24mm_Socket
PinHeader_2x02_P2.54mm_Vertical
DIP-40_W15.24mm_Socket
Oscillator_DIP-14
Main Board_PCB

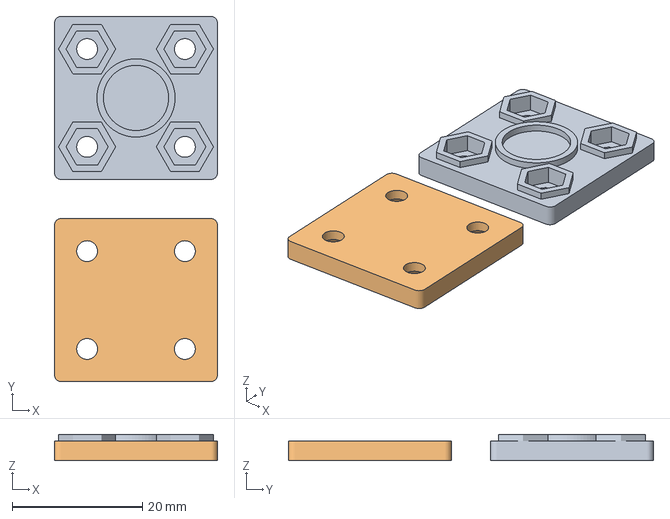
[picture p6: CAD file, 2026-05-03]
CAD/Bases/Center Support.3mf
25.0 x 56.0 x 4.00 mm
Center Support.stl
Center Support Retainer.stl

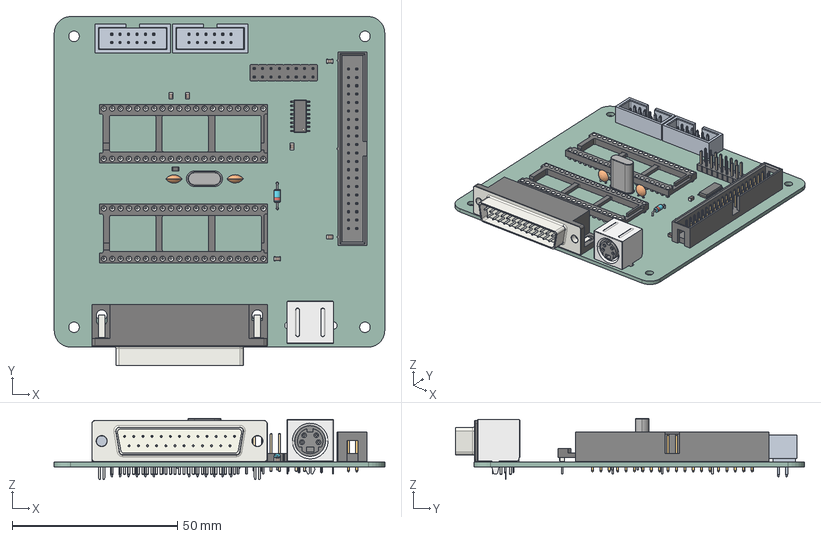
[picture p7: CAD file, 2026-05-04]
CAD/Models/Input Board/Rev 1.0/Input Board.step
100.0 x 105.6 x 18.5 mm
C_Disc_D5.0mm_W2.5mm_P2.50mm x 2
6120xx21621_PIN x 40
C_0805_2012Metric x 6
PinHeader_2x08_P2.54mm_Vertical
R_0805_2012Metric
DIP-40_W15.24mm_Socket x 2
DSUB-25_Pins_Horizontal_P2.77x2.84mm_EdgePinOffset7.70mm_Housed_ MountingHolesOffset9.12mm
D_DO-35_SOD27_P7.62mm_Horizontal
KMDGX-6S-BS
SOIC-16_3.9x9.9mm_P1.27mm
Crystal_HC49-U_Vertical
Input Board_PCB

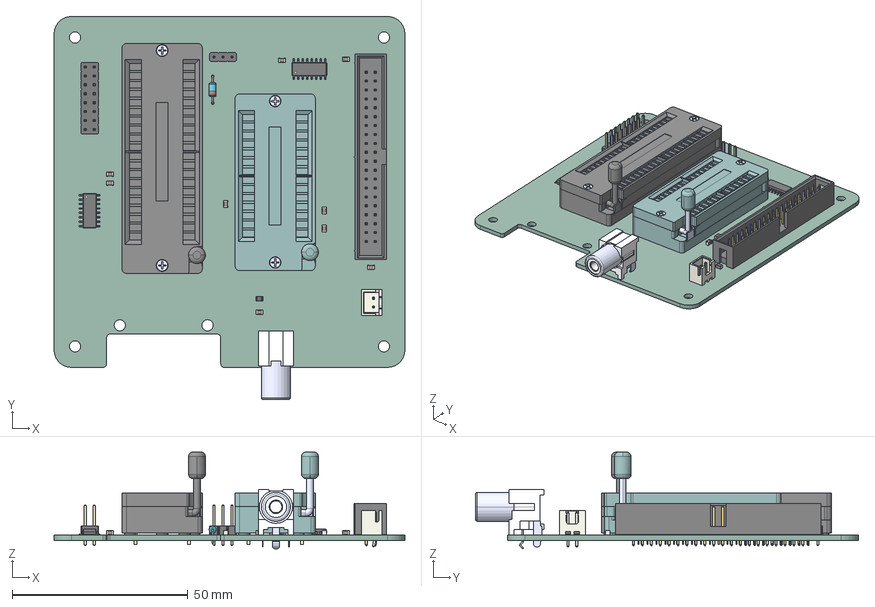
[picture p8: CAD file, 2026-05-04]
CAD/Models/Output Board/Rev 1.0/Output Board.step
100.0 x 109.1 x 27.6 mm
C_0805_2012Metric x 9
SOIC-16_3.9x9.9mm_P1.27mm x 2
R_0805_2012Metric
JST_XH_B2B-XH-A_1x02_P2.50mm_Vertical
PJRAN1X1U04X-edit
PinHeader_1x03_P2.54mm_Vertical
240-1280-00-0602J
PinHeader_2x08_P2.54mm_Vertical
228-1277-00-0602J
6120xx21621_PIN x 40
D_DO-35_SOD27_P7.62mm_Horizontal
Output Board_PCB

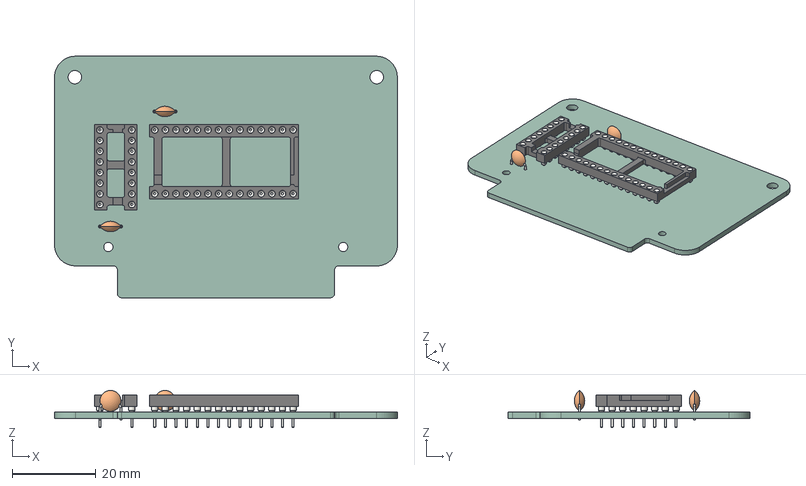
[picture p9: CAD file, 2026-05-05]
CAD/Models/ROM Cart/Rev 1.0a/ROM Cart.step
81.8 x 57.6 x 8.88 mm
DIP-16_W7.62mm_Socket
C_Disc_D5.0mm_W2.5mm_P5.00mm x 2
DIP-28_W15.24mm_Socket
ROM Cart_PCB

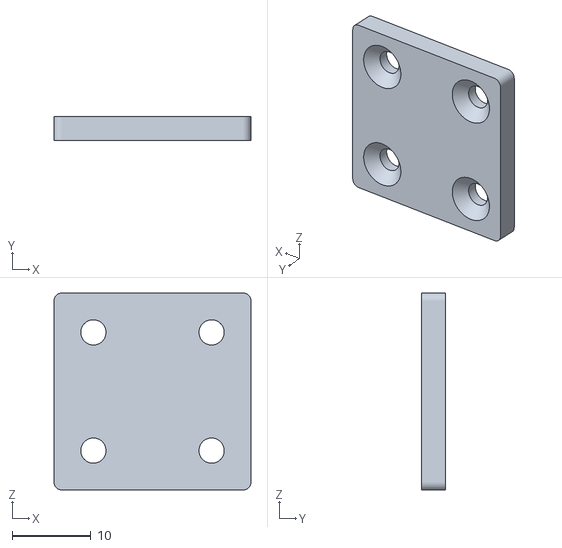
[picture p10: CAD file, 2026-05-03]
CAD/Bases/Center Support Retainer.stl
25.0 x 3.00 x 25.0

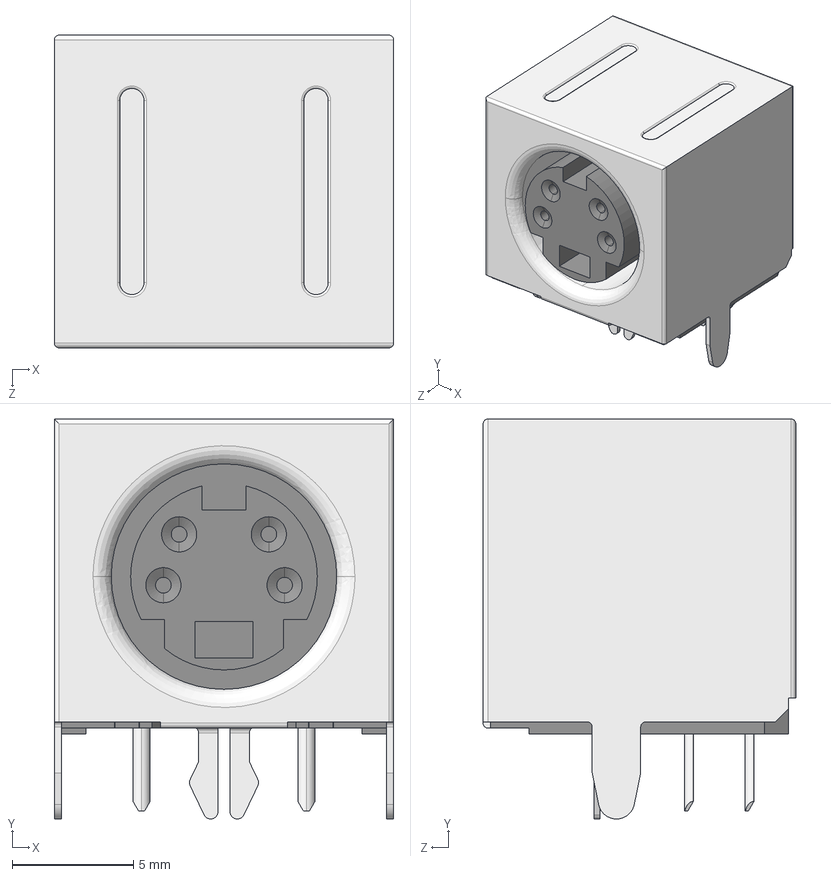
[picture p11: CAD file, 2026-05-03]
Models/KMDGX-6S-BS.step
14.0 x 16.5 x 12.9 mm

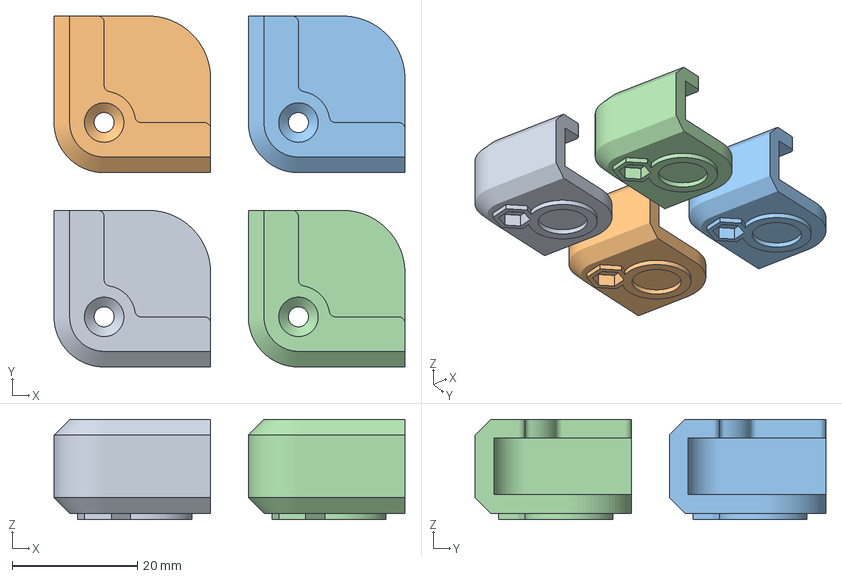
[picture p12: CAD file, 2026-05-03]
CAD/Bases/Corner.3mf
56.0 x 56.0 x 16.0 mm

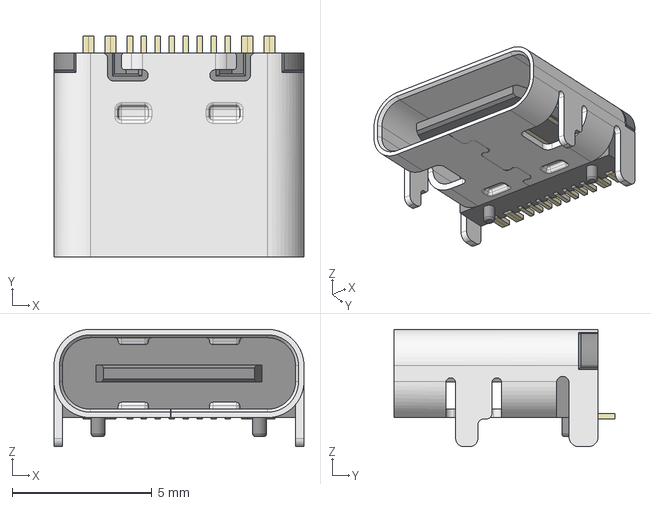
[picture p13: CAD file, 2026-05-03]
Models/HRO_TYPE-C-31-M-12.step
8.95 x 7.90 x 4.20 mm

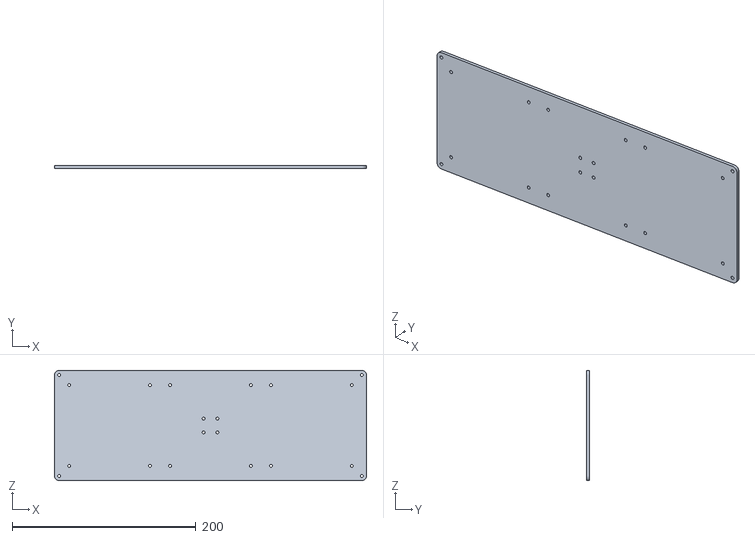
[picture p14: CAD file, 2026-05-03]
CAD/Bases/Plate.stl
340.0 x 3.00 x 120.0

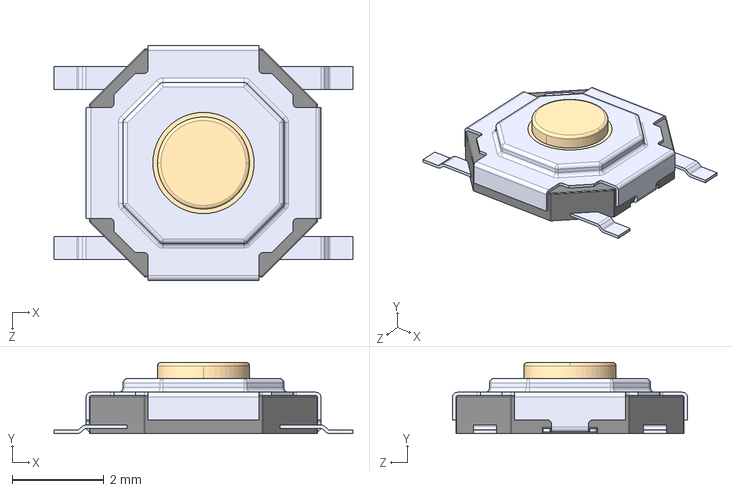
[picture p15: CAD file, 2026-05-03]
Models/TS-1187A-B-A-B.step
6.50 x 1.55 x 5.10 mm

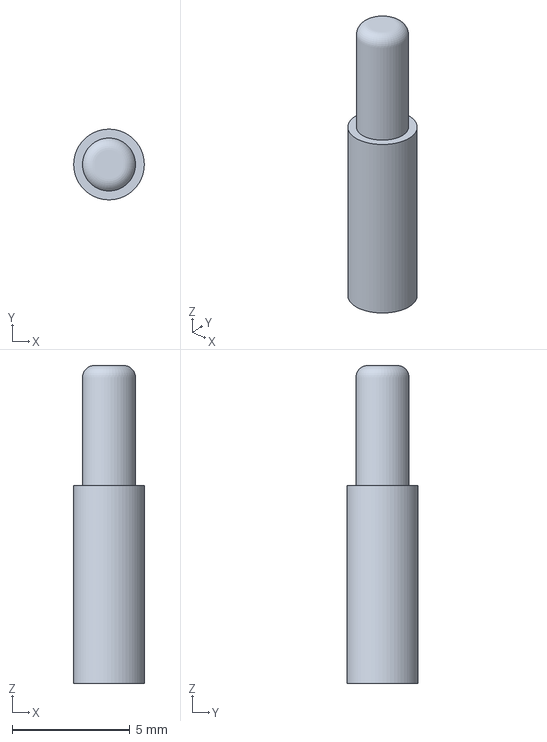
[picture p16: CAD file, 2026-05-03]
CAD/Bases/Button.3mf
3.00 x 3.00 x 13.5 mm

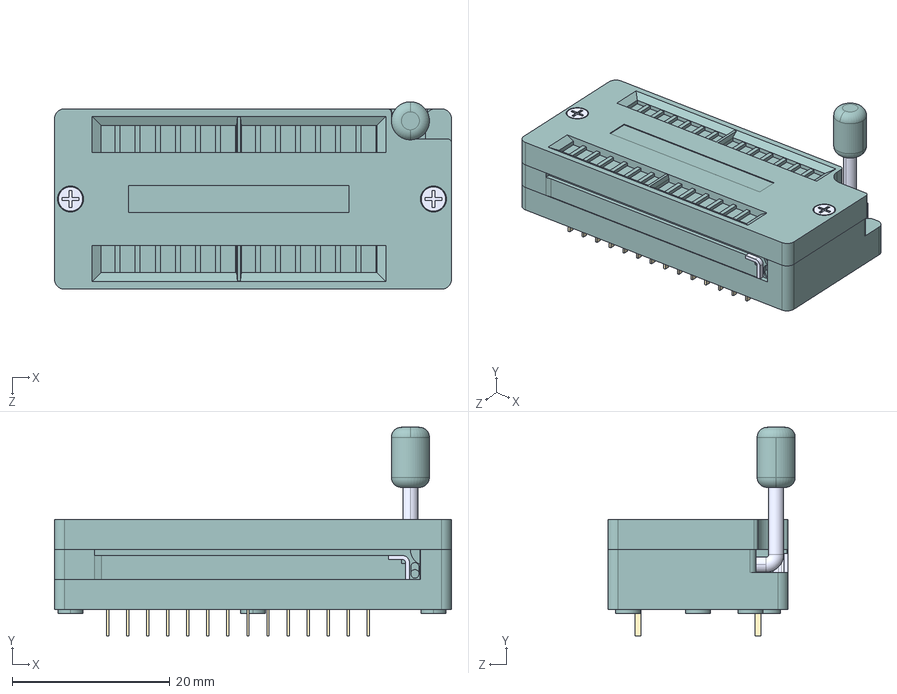
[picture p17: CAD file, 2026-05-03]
Models/228-1277-00-0602J.step
50.3 x 26.4 x 23.7 mm

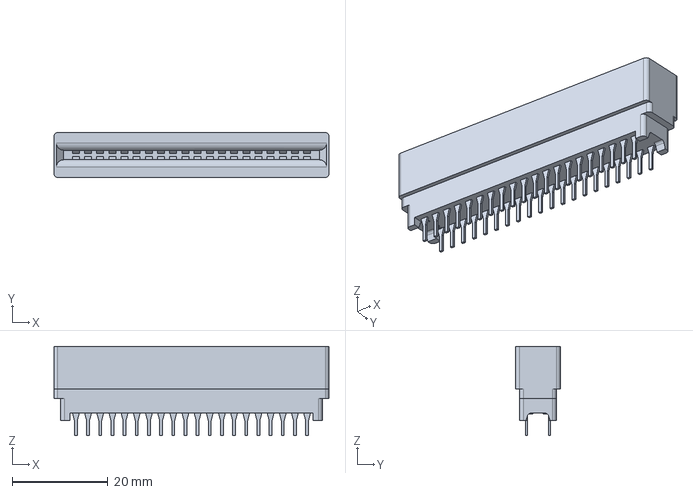
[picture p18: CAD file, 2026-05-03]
Models/5-5530843-4.step
57.4 x 9.35 x 18.7 mm

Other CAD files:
CAD/Models/ROM Cart/Rev 1.0b/ROM Cart.step
Models/PJRAN1X1U02X.step
Models/240-1280-00-0602J.step
Models/0702461201.step
CAD/Bases/Button.stl
CAD/Bases/Center Support.stl
CAD/Bases/Corner.stl
Models/61204021621.step

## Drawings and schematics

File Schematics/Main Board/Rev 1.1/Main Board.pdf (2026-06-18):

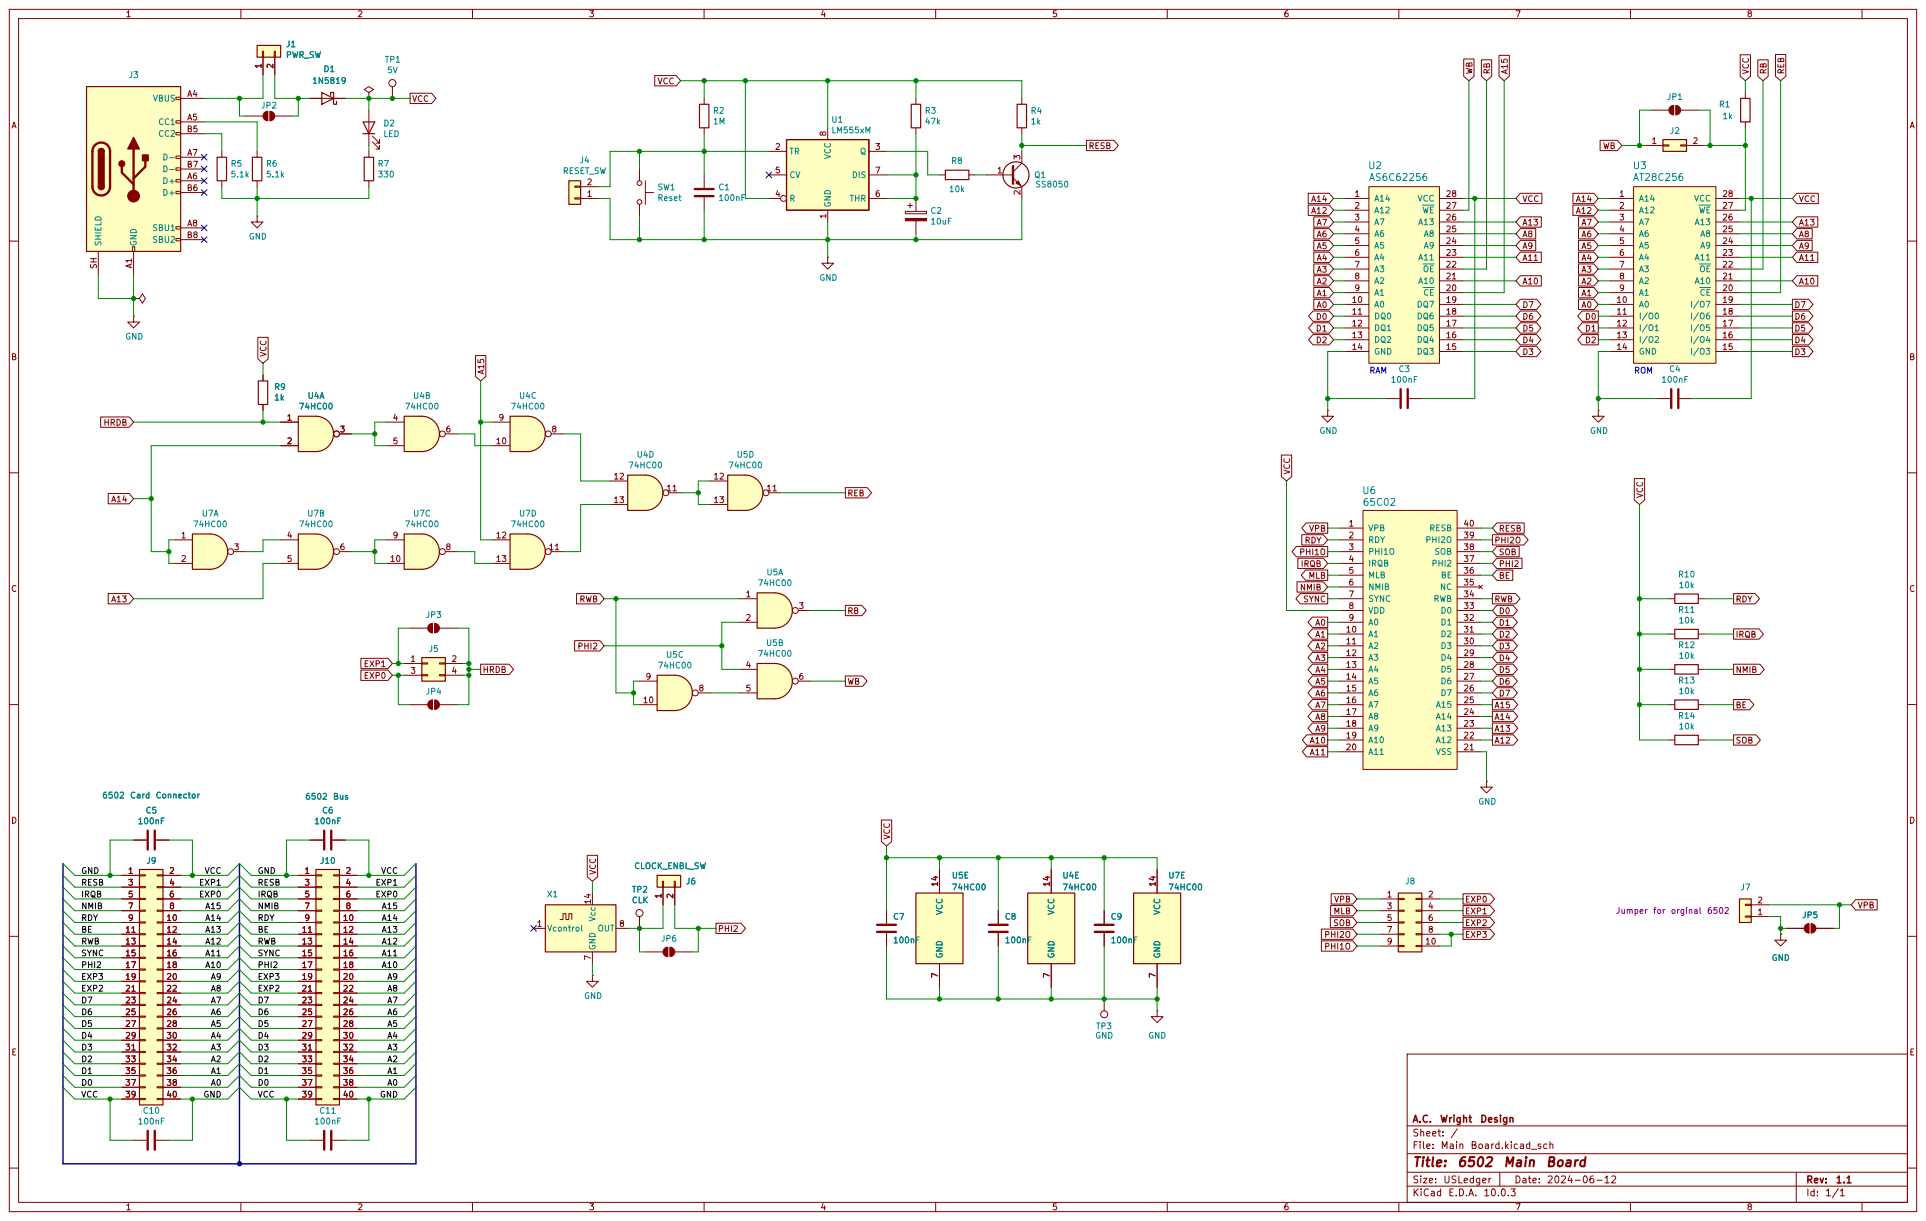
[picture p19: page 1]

A14 A10 | D0 RDY NMIB 17 17 | 18 18 A10

A7 | RDY D4 SYNC 15 15 | 16 16 A11
A13 | BE 11 11 | 12 12 A13
A12 | 13 13 | 14 14 A12

A9 A6 | 25 25 | GND 26 26

A5 | 27 27 | 28 28
A4 | 29 29 | 30 30 A4
A3 | 31 31 | 32 32

Size: USLedger | Rev: 1.1
KiCad E.D.A. 10.0.3 | Id: 1/1

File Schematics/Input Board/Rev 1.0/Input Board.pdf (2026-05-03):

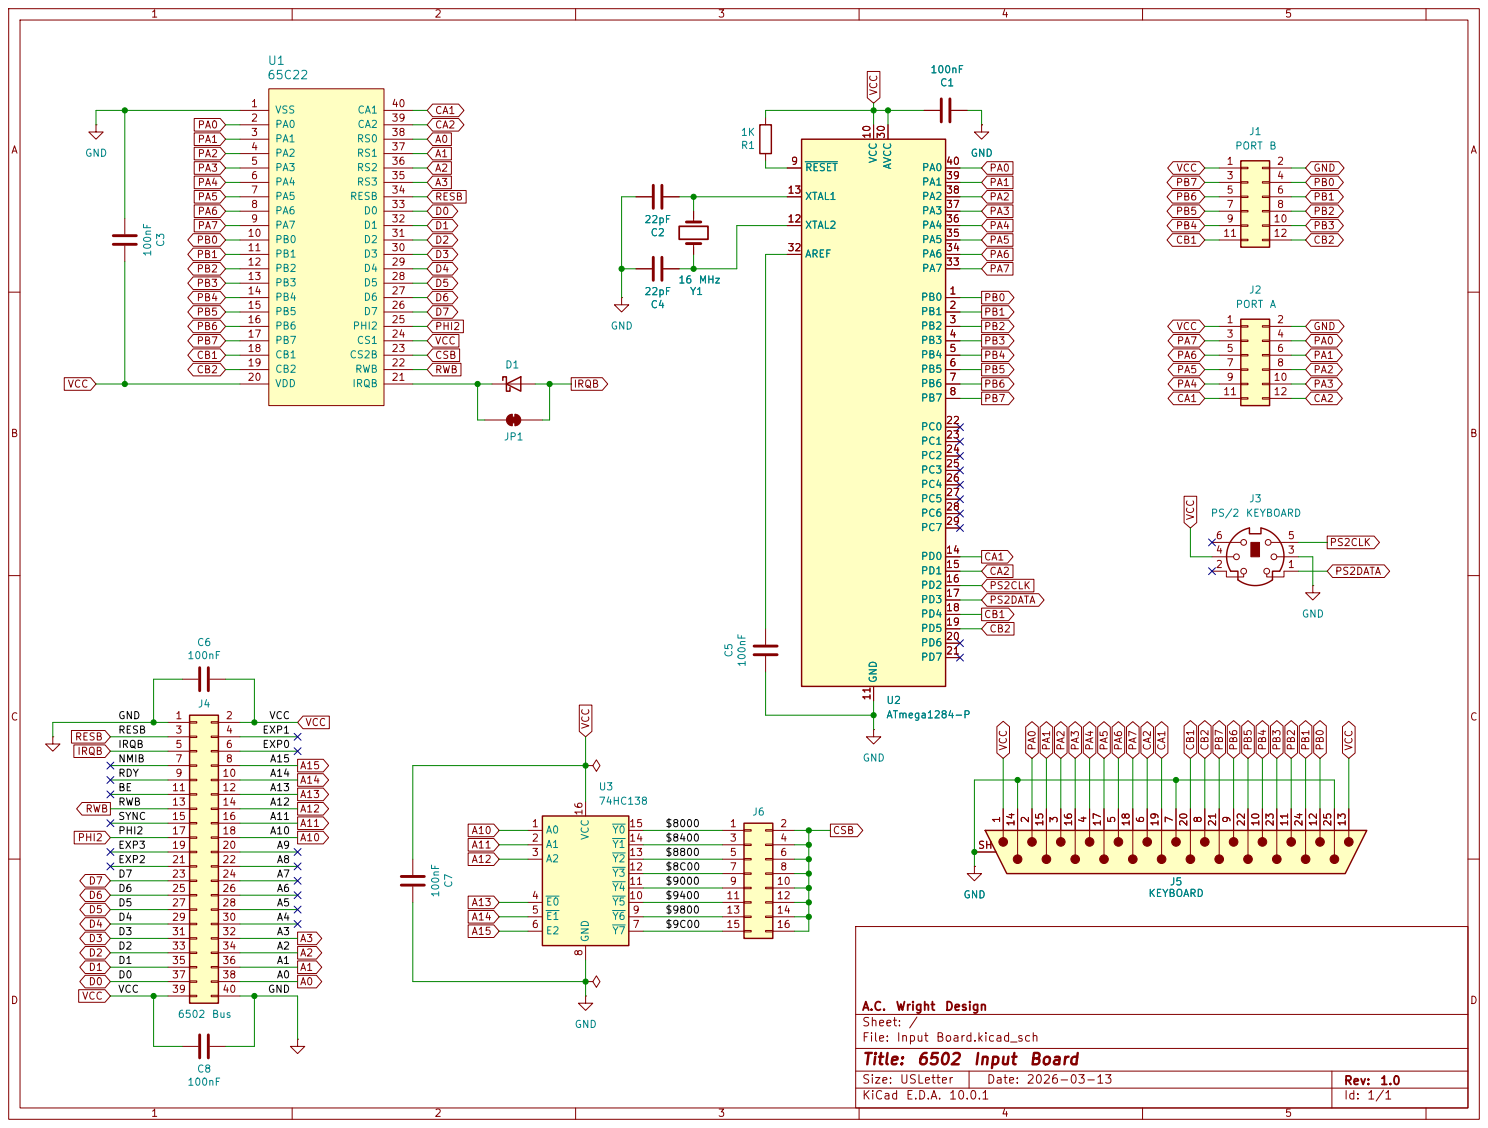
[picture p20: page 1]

$8800 5 | 6
$8C00 7 | 8
$9000 9 | 10
$9400 11 | 12

Size: USLetter | Rev: 1.0
KiCad E.D.A. 10.0.1 | Id: 1/1

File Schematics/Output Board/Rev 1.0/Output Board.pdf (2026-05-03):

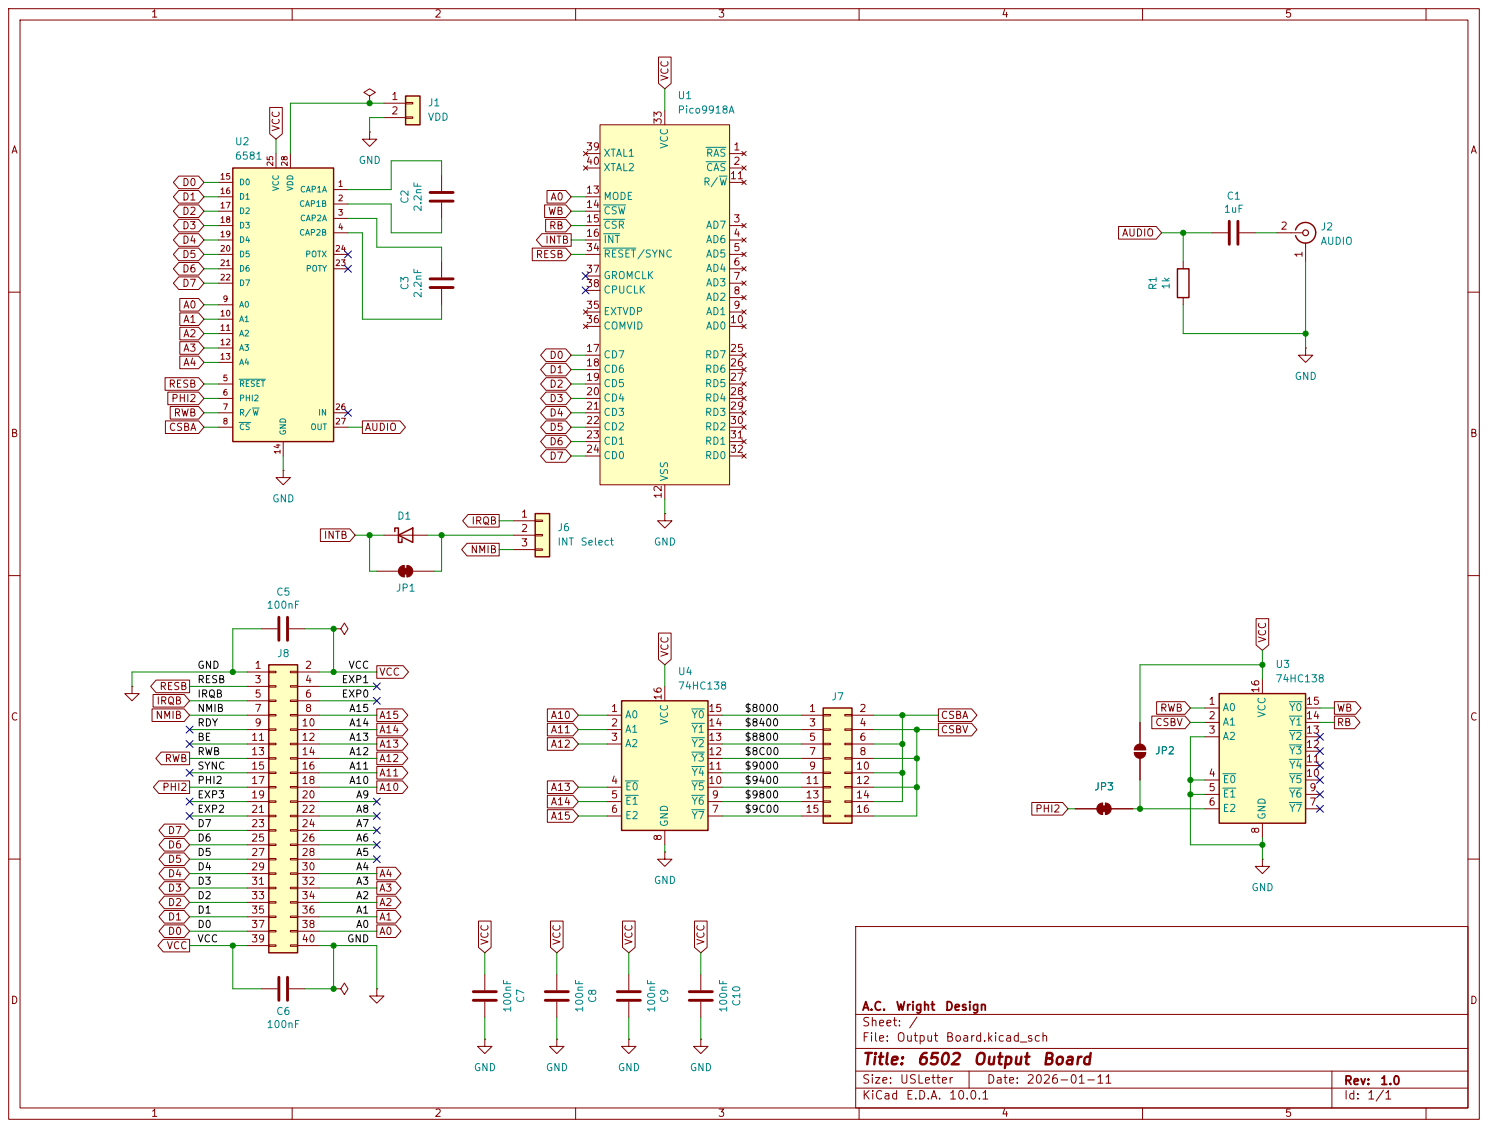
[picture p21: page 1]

EXTVDP 35 COMVID 36 GROMCLK 37 CPUCLK 38

Size: USLetter | Rev: 1.0
KiCad E.D.A. 10.0.1 | Id: 1/1

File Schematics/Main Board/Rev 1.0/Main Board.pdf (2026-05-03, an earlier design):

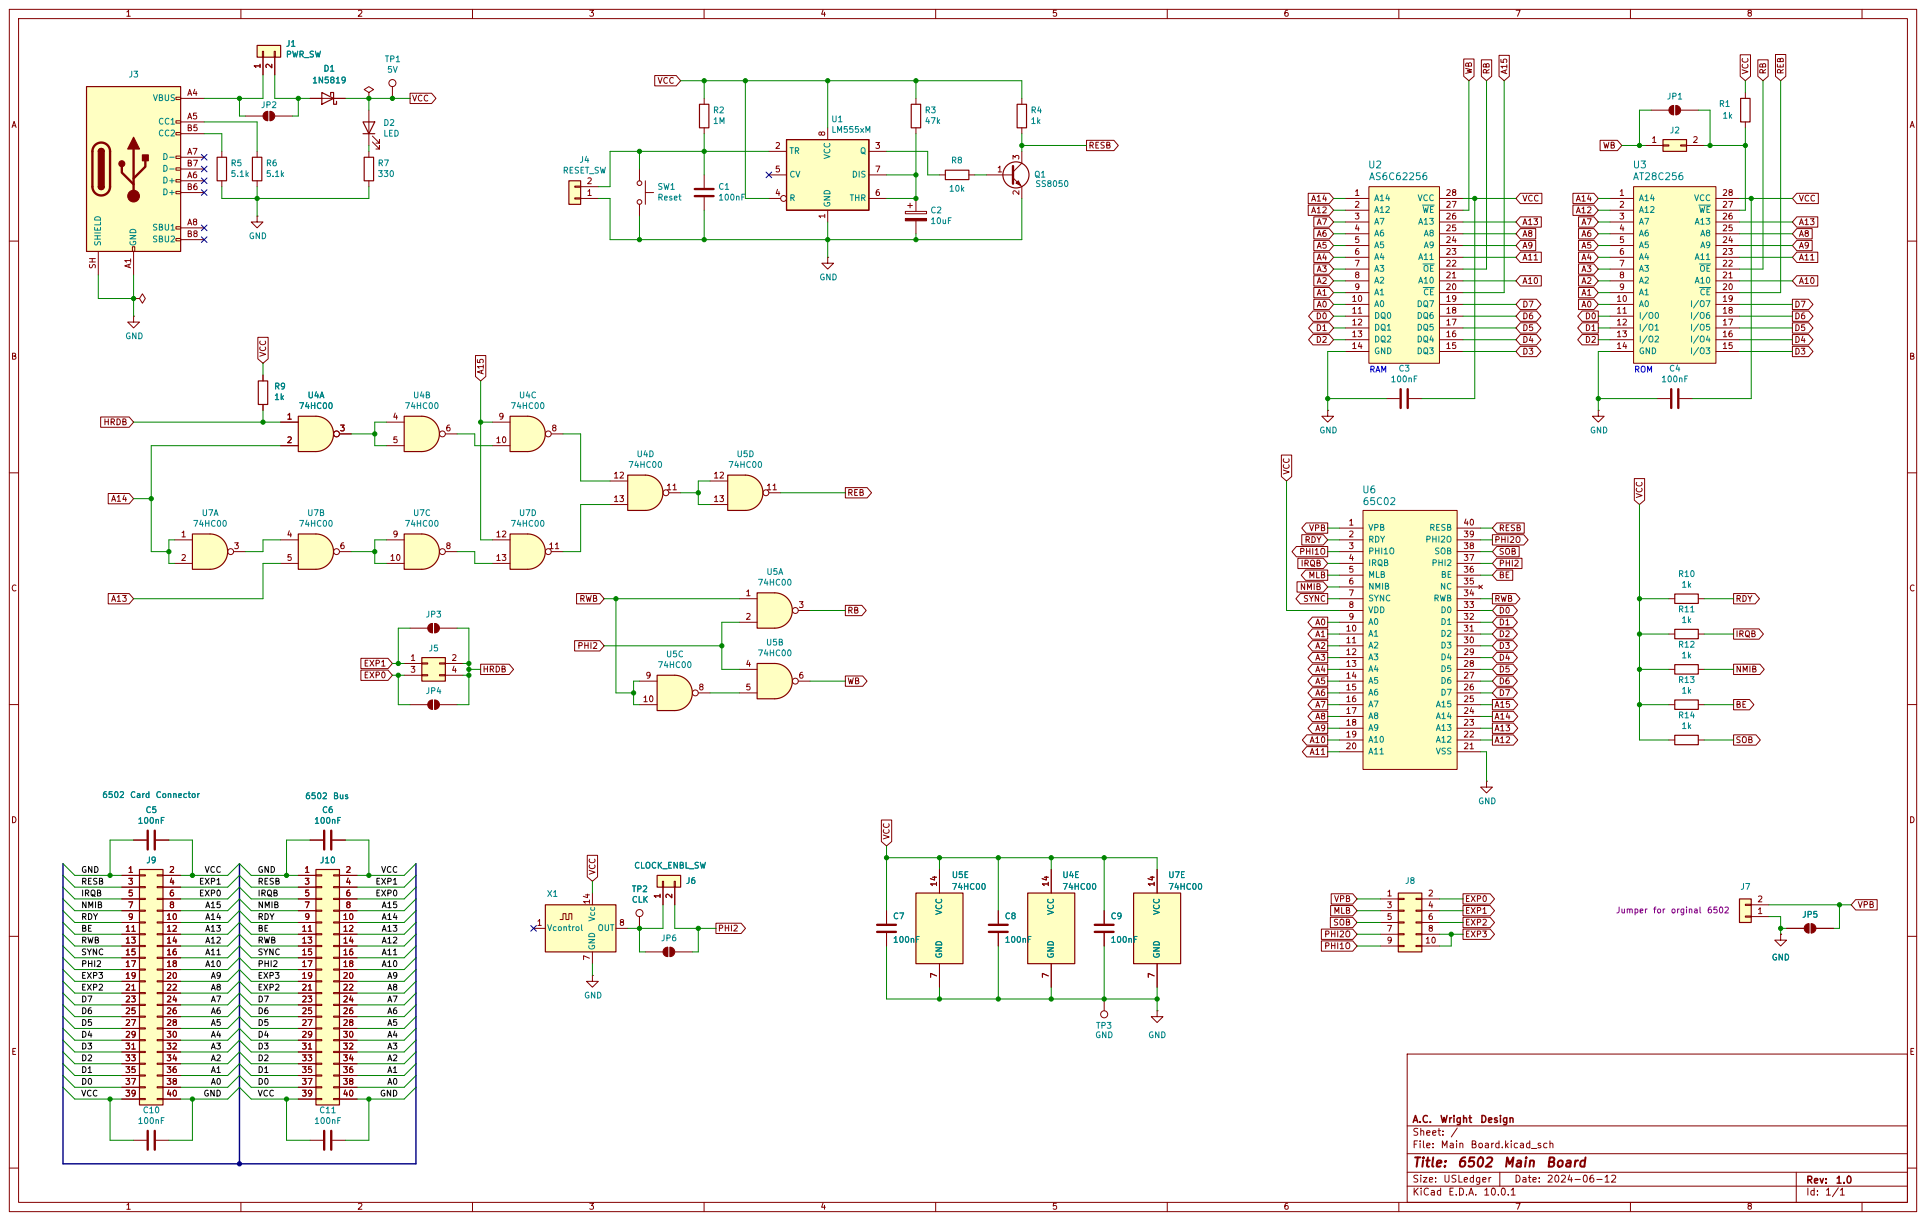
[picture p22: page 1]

A3 A13 | GND 11 11 | 12 12 A13
EXP1 | 3 3 | 4 4 EXP1
EXP0 | IRQB 5 5 | 6 6 EXP0
GND A10 | NMIB 17 17 | 18 18 A10

A14 | EXP2 RESB RDY 9 9 | 10 10 A14

7 OUT 8 Vcc 14X1 GND GND

A12 A0 | RWB D0 21 21 | 22 22
A11 | SYNC 15 15 | 16 16

A7 | 23 23 | 24 24
A6 | 25 25 | 26 26 A6

Size: USLedger | Rev: 1.0
KiCad E.D.A. 10.0.1 | Id: 1/1

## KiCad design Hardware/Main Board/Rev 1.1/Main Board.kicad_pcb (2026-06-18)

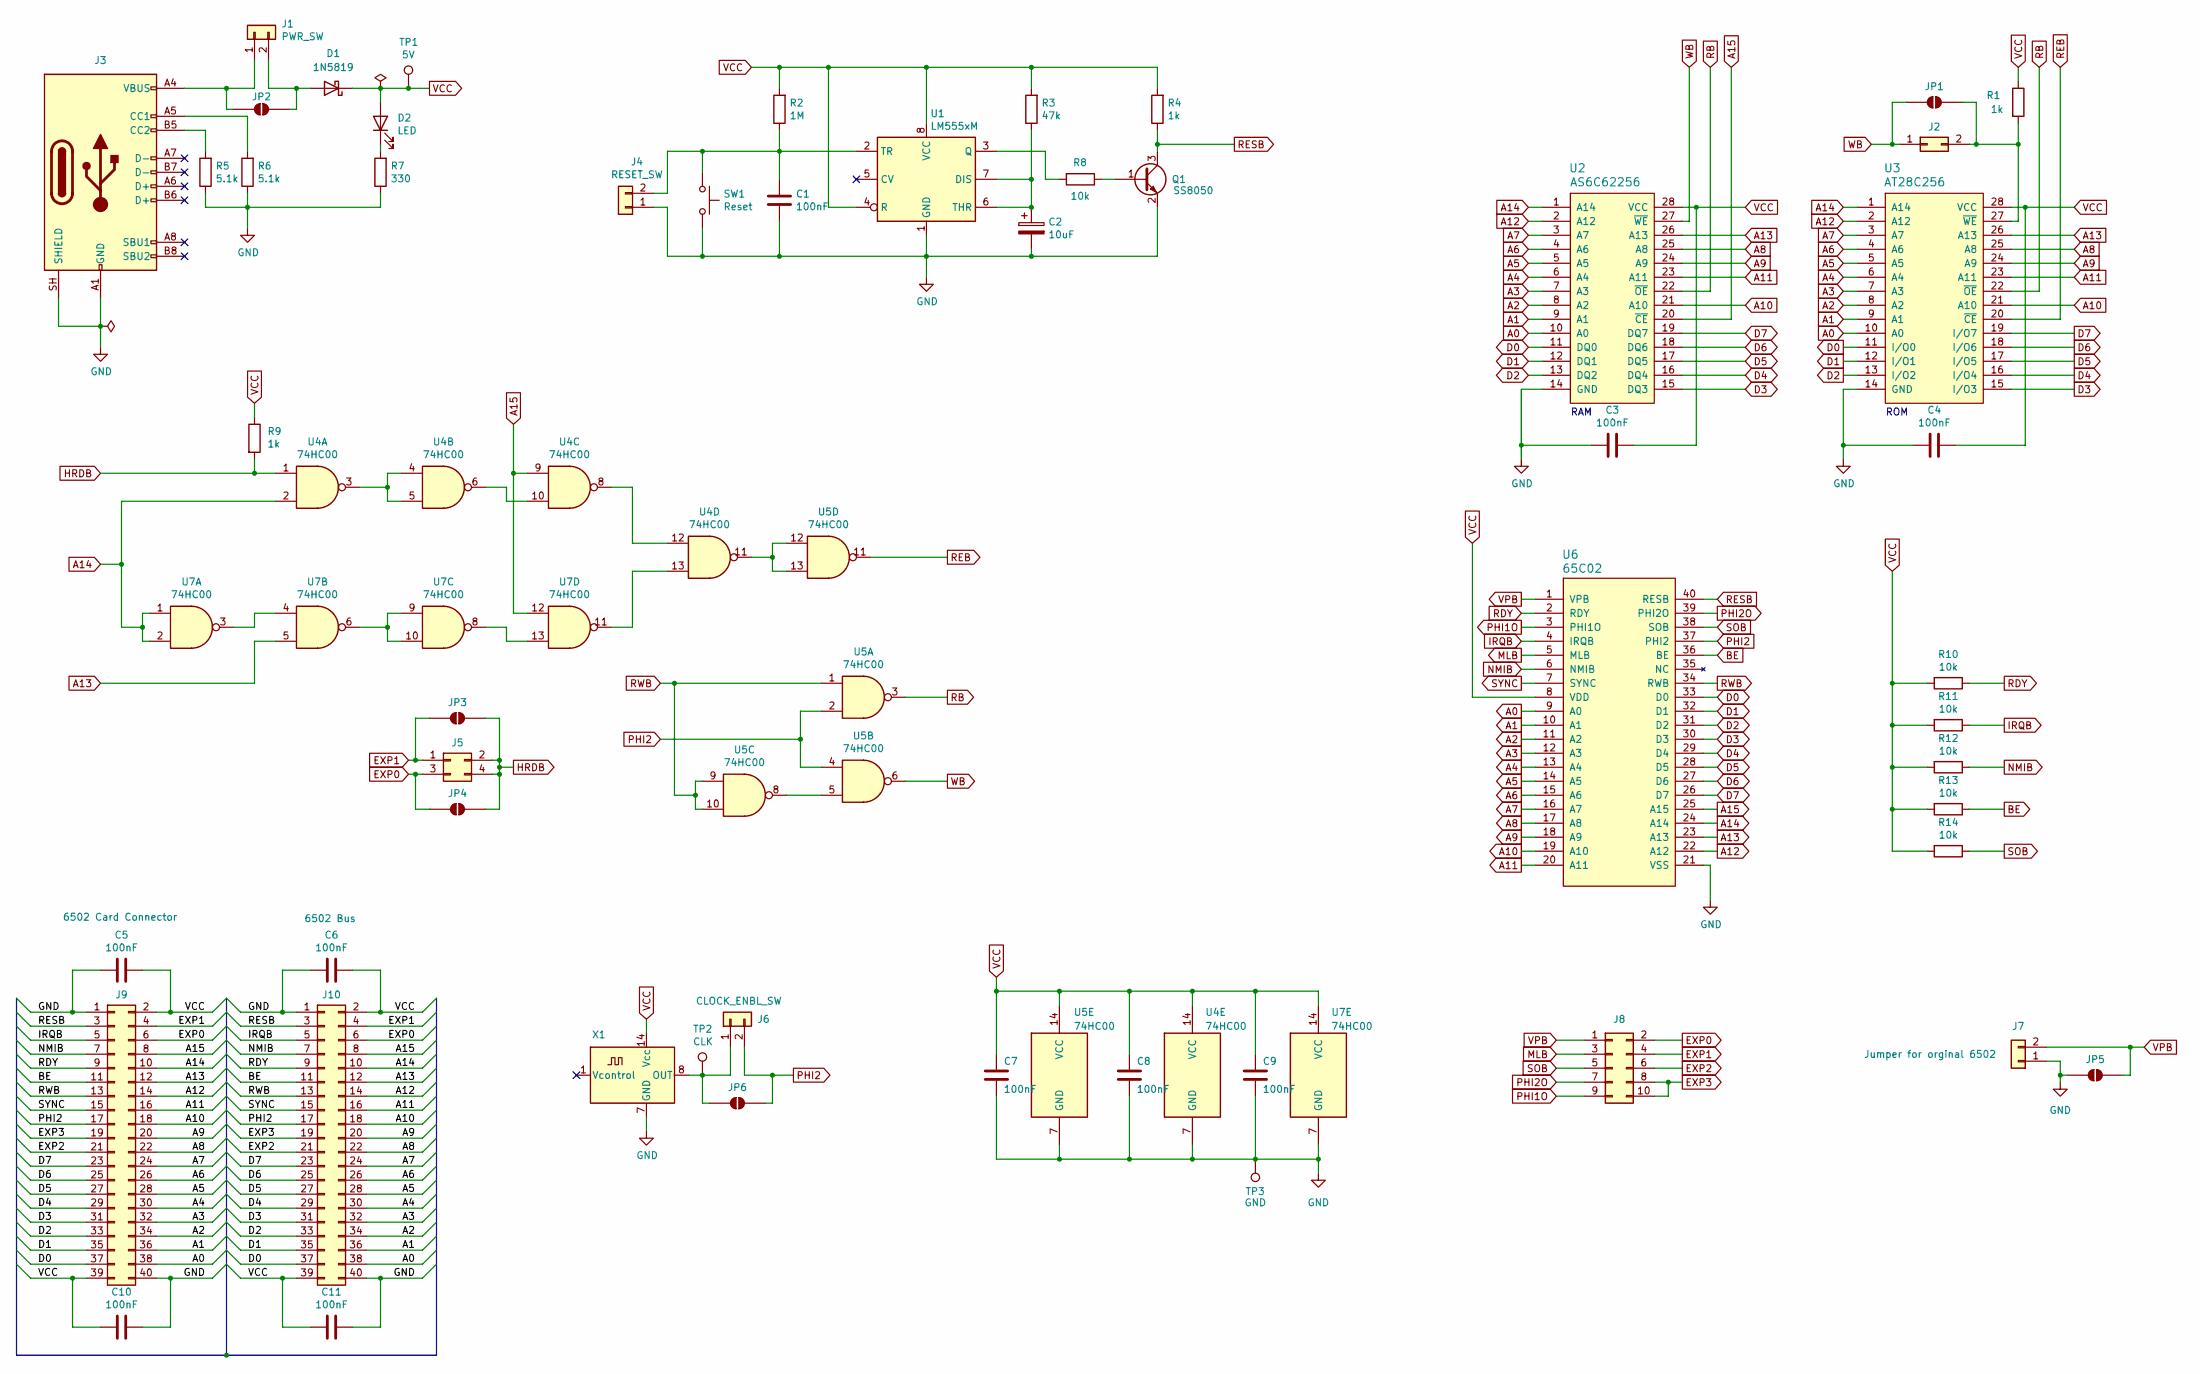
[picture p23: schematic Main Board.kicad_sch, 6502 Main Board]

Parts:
C1, C3, C4, C5, C6, C7, C8, C9, C10, C11: 100nF; C_0805_2012Metric; LCSC C49678
C2: 10uF; C_1206_3216Metric; LCSC C7171
D1: 1N5819; D_SOD-323F; LCSC C191023
D2: LED; LED_0805_2012Metric; LCSC C2297
J1: PWR_SW; JST_XH_B2B-XH-A_1x02_P2.50mm_Vertical; Digikey 455-2247-ND
J2: ROM WE; PinHeader_1x02_P2.54mm_Vertical
J3: USB_C_Receptacle_USB2.0; USB_C_Receptacle_HRO_TYPE-C-31-M-12; LCSC C2988369
J4: RESET_SW; JST_XH_B2B-XH-A_1x02_P2.50mm_Vertical; Digikey 455-2247-ND
J5: HRDB EN; PinHeader_2x02_P2.54mm_Vertical
J6: CLOCK_ENBL_SW; JST_XH_B2B-XH-A_1x02_P2.50mm_Vertical; Digikey 455-2247-ND
J7: 6502 EN; PinHeader_1x02_P2.54mm_Vertical
J8: EXP EN; PinHeader_2x05_P2.54mm_Vertical
J9: 6502 Card Connector; RHDR40W82P485X254_2X20_5740X93; Mouser 571-5-5530843-4
J10: 6502 Bus; 6502 Bus Connector
JP1, JP2, JP3, JP4, JP5, JP6: SolderJumper_2_Open; SolderJumper-2_P1.3mm_Open_RoundedPad1.0x1.5mm
Q1: SS8050; SOT-23; LCSC C2150
R1, R4, R9: 1k; R_0805_2012Metric; LCSC C17513
R2: 1M; R_0805_2012Metric; LCSC C17514
R3: 47k; R_0805_2012Metric; LCSC C17713
R5, R6: 5.1k; R_0805_2012Metric; LCSC C27834
R7: 330; R_0805_2012Metric; LCSC C17630
R8: 10k; R_0805_2012Metric; LCSC C17414
R10, R11, R12, R13, R14: 10k; R_0805_2012Metric; LCSC C2930231
SW1: Reset; SW_TS-1187A-B-A-B; LCSC C318884
TP1: 5V; TestPoint_Pad_1.0x1.0mm
TP2: CLK; TestPoint_Pad_1.0x1.0mm
TP3: GND; TestPoint_Pad_1.0x1.0mm
U1: LM555xM; SOIC-8_3.9x4.9mm_P1.27mm; LCSC C7593
U2: AS6C62256; DIP-28_W15.24mm_Socket_LongPads; Digikey 1450-1033-ND
U3: AT28C256; DIP_Socket-28_W11.9mm_W12.7mm_W15.24mm_W17.78mm_W18.5mm_3M_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; Digikey AT28C256-15PU-ND
U4, U5, U7: 74HC00; SOIC-14_3.9x8.7mm_P1.27mm; LCSC C5586
U6: 65C02; DIP-40_W15.24mm_Socket_LongPads; Mouser 955-W65C02S6TPG-14
X1: OCXO-14; Oscillator_DIP-14; Digikey X937-ND

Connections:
A0: J9.38, J10.38, U2.10 (A0), U3.10 (A0), U6.9 (A0)
A1: J9.36, J10.36, U2.9 (A1), U3.9 (A1), U6.10 (A1)
A2: J9.34, J10.34, U2.8 (A2), U3.8 (A2), U6.11 (A2)
A3: J9.32, J10.32, U2.7 (A3), U3.7 (A3), U6.12 (A3)
A4: J9.30, J10.30, U2.6 (A4), U3.6 (A4), U6.13 (A4)
A5: J9.28, J10.28, U2.5 (A5), U3.5 (A5), U6.14 (A5)
A6: J9.26, J10.26, U2.4 (A6), U3.4 (A6), U6.15 (A6)
A7: J9.24, J10.24, U2.3 (A7), U3.3 (A7), U6.16 (A7)
A8: J9.22, J10.22, U2.25 (A8), U3.25 (A8), U6.17 (A8)
A9: J9.20, J10.20, U2.24 (A9), U3.24 (A9), U6.18 (A9)
A10: J9.18, J10.18, U2.21 (A10), U3.21 (A10), U6.19 (A10)
A11: J9.16, J10.16, U2.23 (A11), U3.23 (A11), U6.20 (A11)
A12: J9.14, J10.14, U2.2 (A12), U3.2 (A12), U6.22 (A12)
A13: J9.12, J10.12, U2.26 (A13), U3.26 (A13), U6.23 (A13), U7.5
A14: J9.10, J10.10, U2.1 (A14), U3.1 (A14), U4.2, U6.24 (A14), U7.1, U7.2
A15: J9.8, J10.8, U2.20 (~CE), U4.9, U6.25 (A15), U7.12
BE: J9.11, J10.11, R13.1, U6.36 (BE)
D0: J9.37, J10.37, U2.11 (DQ0), U3.11 (I/O0), U6.33 (D0)
D1: J9.35, J10.35, U2.12 (DQ1), U3.12 (I/O1), U6.32 (D1)
D2: J9.33, J10.33, U2.13 (DQ2), U3.13 (I/O2), U6.31 (D2)
D3: J9.31, J10.31, U2.15 (DQ3), U3.15 (I/O3), U6.30 (D3)
D4: J9.29, J10.29, U2.16 (DQ4), U3.16 (I/O4), U6.29 (D4)
D5: J9.27, J10.27, U2.17 (DQ5), U3.17 (I/O5), U6.28 (D5)
D6: J9.25, J10.25, U2.18 (DQ6), U3.18 (I/O6), U6.27 (D6)
D7: J9.23, J10.23, U2.19 (DQ7), U3.19 (I/O7), U6.26 (D7)
EXP0: J5.3, J8.2, J9.6, J10.6, JP4.1 (A)
EXP1: J5.1, J8.4, J9.4, J10.4, JP3.1 (A)
EXP2: J8.6, J9.21, J10.21
EXP3: J8.8, J8.10, J9.19, J10.19
GND: C1.2, C2.2, C3.2, C4.2, C5.2, C6.2, C7.2, C8.2, C9.2, C10.1, C11.1, J3.A1 (GND), J3.A12 (GND), J3.B1 (GND), J3.B12 (GND), J3.SH (SHIELD), J4.1, J7.1, J9.1, J9.40, J10.1, J10.40, JP5.1 (A), Q1.2 (E), R5.1, R6.1, R7.1, SW1.2, TP3.1 (1_1), U1.1 (GND), U2.14 (GND), U3.14 (GND), U4.7 (GND), U5.7 (GND), U6.21 (VSS), U7.7 (GND), X1.7 (GND)
HRDB: J5.2, J5.4, JP3.2 (B), JP4.2 (B), R9.2, U4.1
IRQB: J9.5, J10.5, R11.1, U6.4 (IRQB)
MLB: J8.3, U6.5 (MLB)
NMIB: J9.7, J10.7, R12.1, U6.6 (NMIB)
unnamed: D1.2 (A), J1.2, JP2.2 (B)
unnamed: D2.1 (K), R7.2
unnamed: J1.1, J3.A4 (VBUS), J3.A9 (VBUS), J3.B4 (VBUS), J3.B9 (VBUS), JP2.1 (A)
unnamed: J2.2, JP1.2 (B), R1.2, U3.27 (~WE)
unnamed: J3.A5 (CC1), R6.2
unnamed: J3.B5 (CC2), R5.2
unnamed: C1.1, J4.2, R2.1, SW1.1, U1.2 (TR)
unnamed: J6.1, JP6.1 (A), TP2.1 (1_1), X1.8 (OUT)
unnamed: Q1.1 (B), R8.1
unnamed: C2.1, R3.1, U1.6 (THR), U1.7 (DIS)
unnamed: R8.2, U1.3 (Q)
unnamed: U4.3, U4.4, U4.5
unnamed: U4.6, U4.10
unnamed: U4.11, U5.12, U5.13
unnamed: U4.8, U4.12
unnamed: U4.13, U7.11
unnamed: U5.5, U5.8
unnamed: U7.3, U7.4
unnamed: U7.6, U7.9, U7.10
unnamed: U7.8, U7.13
PHI1O: J8.9, U6.3 (PHI1O)
PHI2: J6.2, J9.17, J10.17, JP6.2 (B), U5.2, U5.4, U6.37 (PHI2)
PHI2O: J8.7, U6.39 (PHI2O)
RB: U2.22 (~OE), U3.22 (~OE), U5.3
RDY: J9.9, J10.9, R10.1, U6.2 (RDY)
REB: U3.20 (~CE), U5.11
RESB: J9.3, J10.3, Q1.3 (C), R4.1, U6.40 (RESB)
RWB: J9.13, J10.13, U5.1, U5.9, U5.10, U6.34 (RWB)
SOB: J8.5, R14.1, U6.38 (SOB)
SYNC: J9.15, J10.15, U6.7 (SYNC)
VCC: C3.1, C4.1, C5.1, C6.1, C7.1, C8.1, C9.1, C10.2, C11.2, D1.1 (K), D2.2 (A), J9.2, J9.39, J10.2, J10.39, R1.1, R2.2, R3.2, R4.2, R9.1, R10.2, R11.2, R12.2, R13.2, R14.2, TP1.1 (1_1), U1.4 (R), U1.8 (VCC), U2.28 (VCC), U3.28 (VCC), U4.14 (VCC), U5.14 (VCC), U6.8 (VDD), U7.14 (VCC), X1.14 (Vcc)
VPB: J7.2, J8.1, JP5.2 (B), U6.1 (VPB)
WB: J2.1, JP1.1 (A), U2.27 (~WE), U5.6

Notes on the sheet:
ROM
RAM

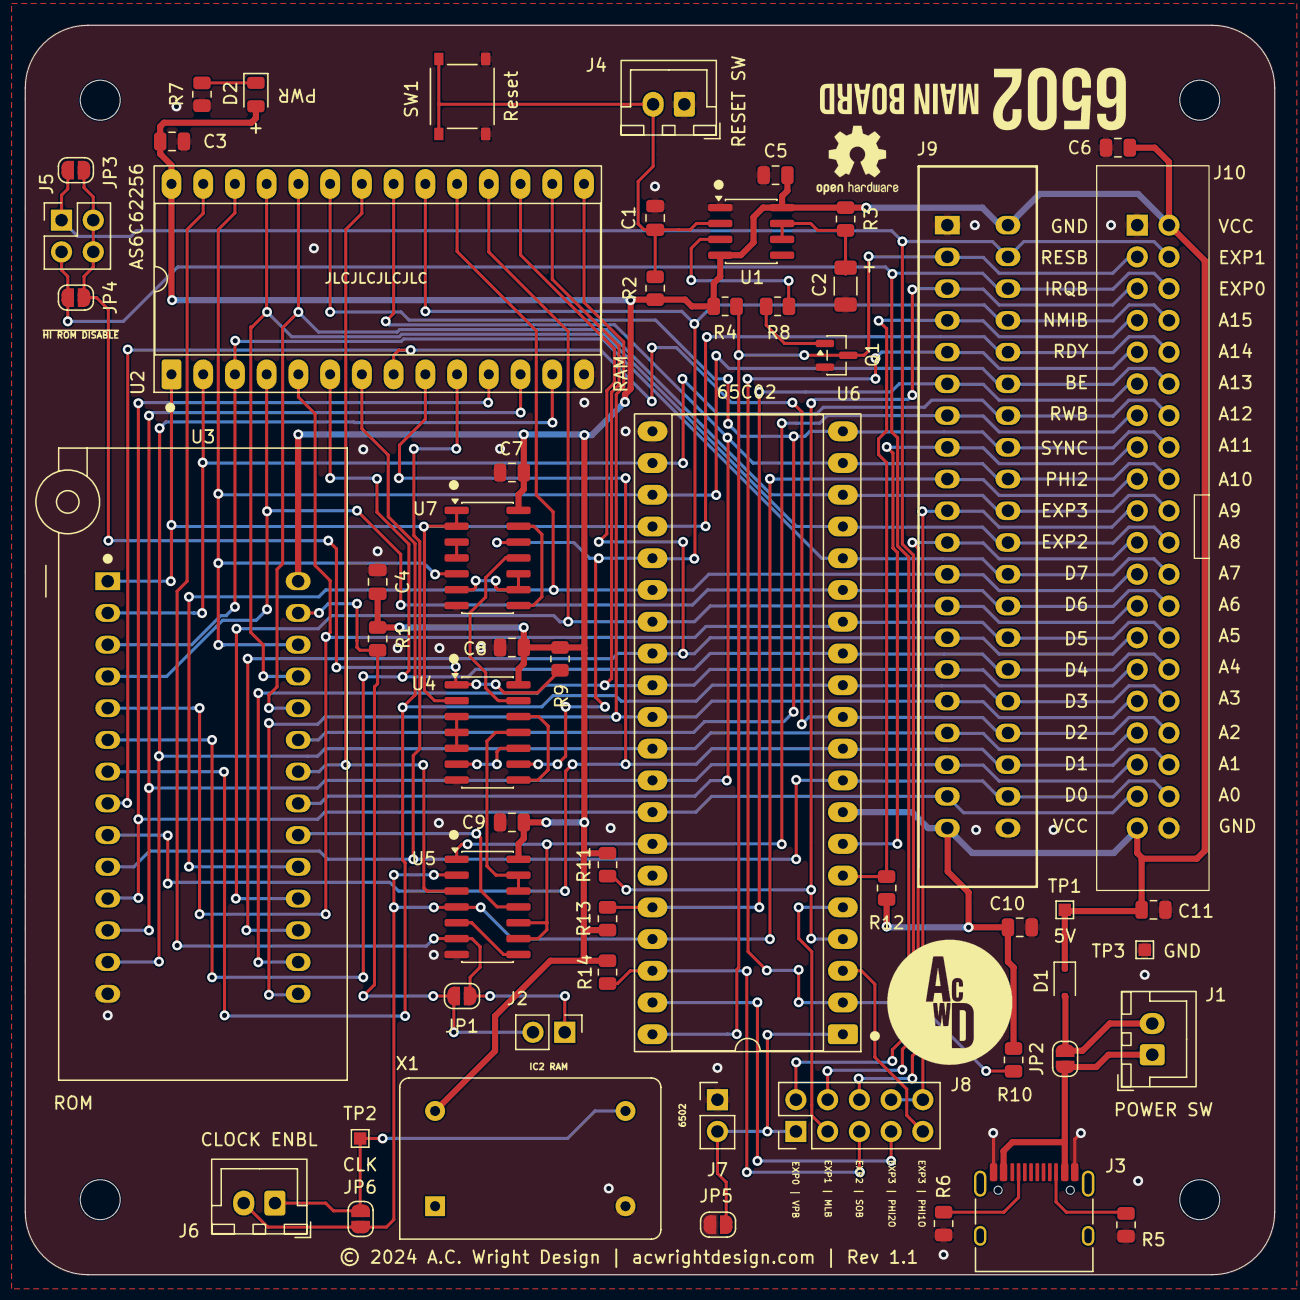
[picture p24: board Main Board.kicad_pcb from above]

Board: 2 copper layers, 100.0 x 100.0 mm, 60 parts (0 on the bottom side), 67 nets.

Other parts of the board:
H1, H2, H3, H4: MountingHole; MountingHole_3.2mm_M3

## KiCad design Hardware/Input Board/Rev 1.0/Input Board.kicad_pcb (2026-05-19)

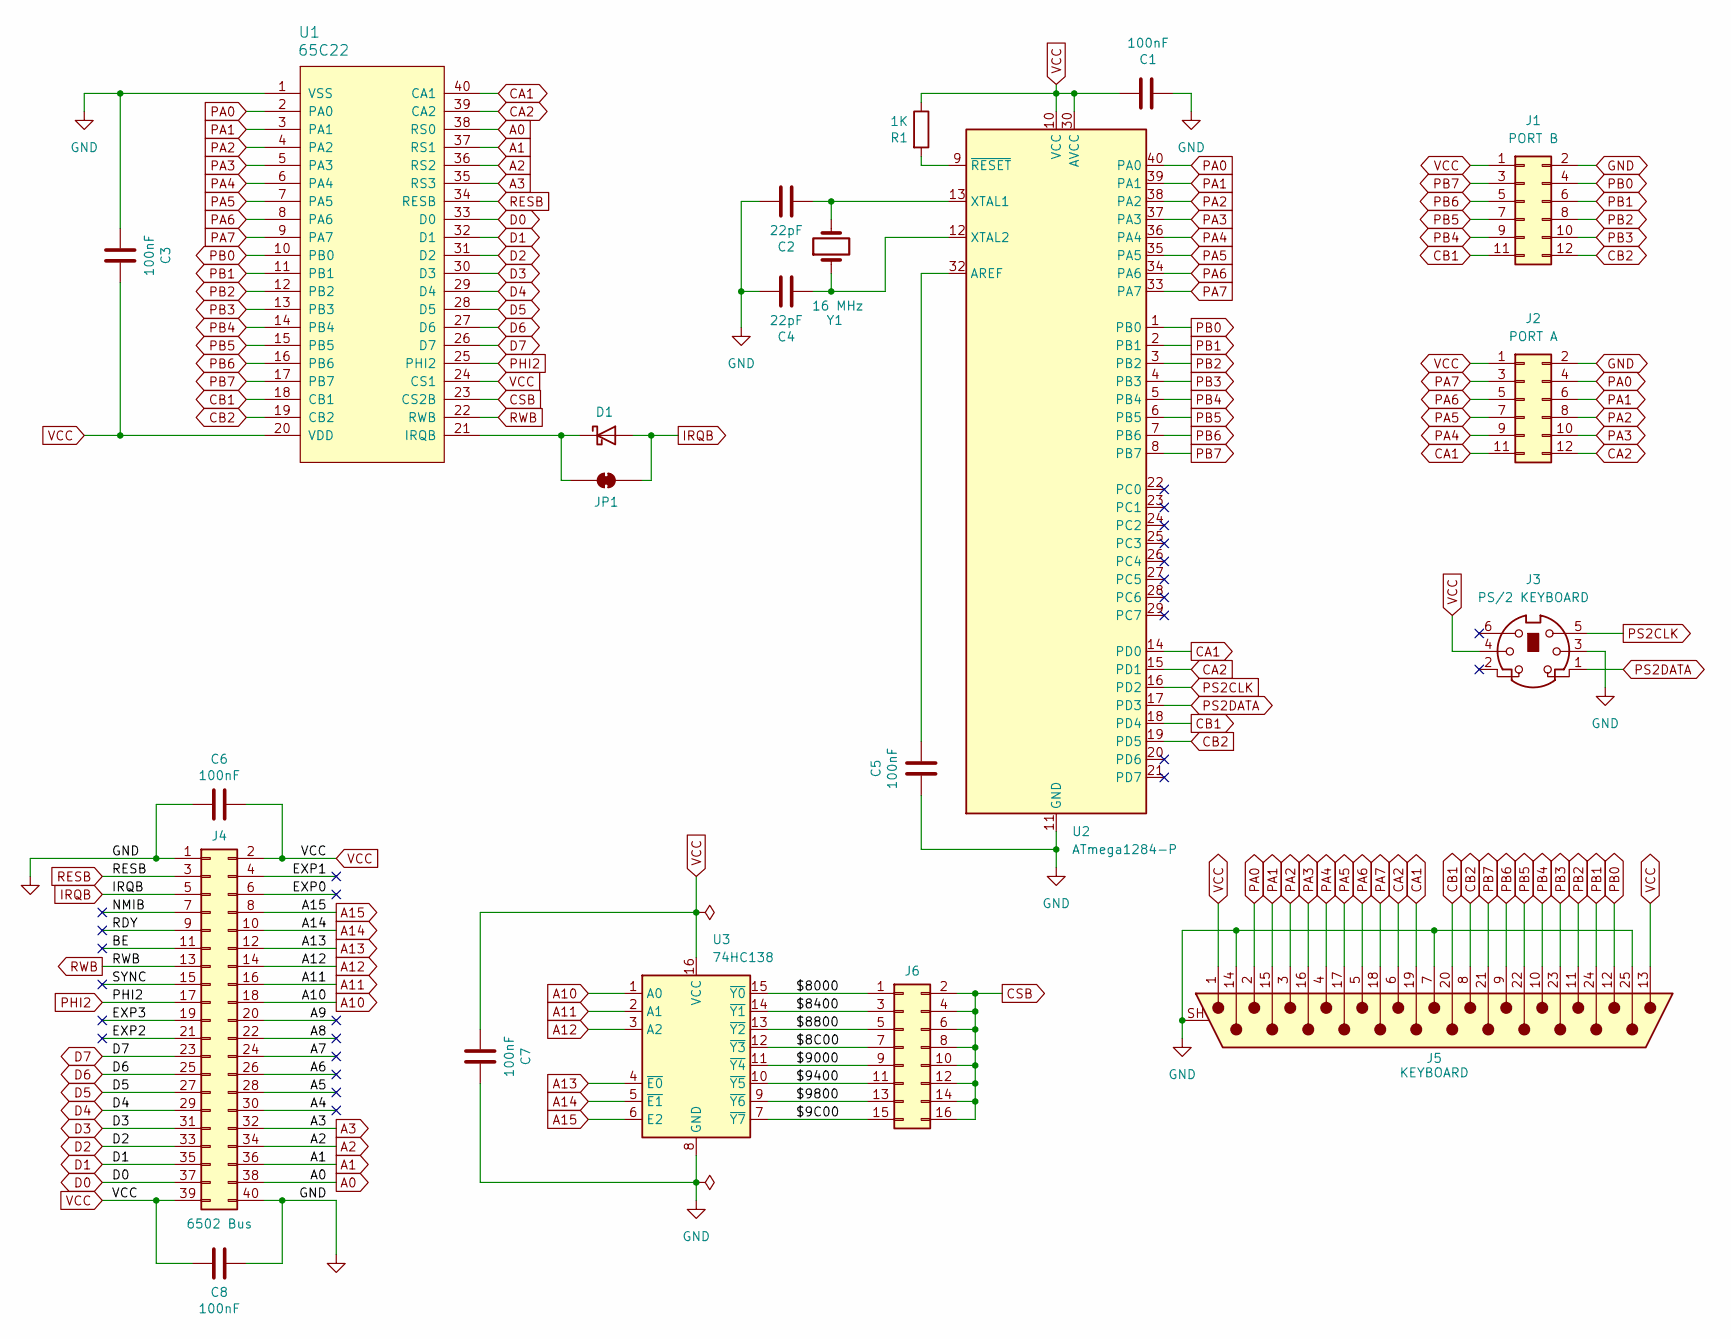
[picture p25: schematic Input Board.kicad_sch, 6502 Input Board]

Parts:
C1, C3, C5, C6, C7, C8: 100nF; C_0805_2012Metric; LCSC C49678
C2, C4: 22pF; C_Disc_D5.0mm_W2.5mm_P2.50mm; LCSC C107114
D1: 1N914; D_DO-35_SOD27_P7.62mm_Horizontal; Digikey 1N914FS-ND
J1: PORT B; 6502 GPIO Connector; Digikey 2057-BHR-12-VUA-ND
J2: PORT A; 6502 GPIO Connector; Digikey 2057-BHR-12-VUA-ND
J3: PS/2 KEYBOARD; KMDGX-6S-BS; Mouser 806-KMDGX-6S-BS
J4: 6502 Bus; 6502 Bus Connector
J5: KEYBOARD; DSUB-25_Pins_Horizontal_P2.77x2.84mm_EdgePinOffset7.70mm_Ho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; MPN D25P33E4GX00LF; Digikey 609-1505-ND
J6: IO SELECT; PinHeader_2x08_P2.54mm_Vertical
JP1: IRQ; SolderJumper-2_P1.3mm_Bridged_RoundedPad1.0x1.5mm
R1: 1K; R_0805_2012Metric; LCSC C17513
U1: 65C22; DIP-40_W15.24mm_Socket_LongPads; Mouser 955-W65C22N6TPG-14
U2: ATmega1284-P; DIP-40_W15.24mm_Socket_LongPads; Mouser 556-ATMEGA1284-PU
U3: 74HC138; SOIC-16_3.9x9.9mm_P1.27mm; LCSC C5602
Y1: 16 MHz; Crystal_HC49-U_Vertical; Digikey 3155-16M20P2/49US-ND

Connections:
/$8C00: J6.7, U3.12 (~Y3)
/$9C00: J6.15, U3.7 (~Y7)
/$8000: J6.1, U3.15 (~Y0)
/$8400: J6.3, U3.14 (~Y1)
/$8800: J6.5, U3.13 (~Y2)
/$9000: J6.9, U3.11 (~Y4)
/$9400: J6.11, U3.10 (~Y5)
/$9800: J6.13, U3.9 (~Y6)
/A4: J4.30
/A5: J4.28
/A6: J4.26
/A7: J4.24
/A8: J4.22
/A9: J4.20
/BE: J4.11
/EXP0: J4.6
/EXP1: J4.4
/EXP2: J4.21
/EXP3: J4.19
/NMIB: J4.7
/RDY: J4.9
/SYNC: J4.15
A0: J4.38, U1.38 (RS0)
A1: J4.36, U1.37 (RS1)
A2: J4.34, U1.36 (RS2)
A3: J4.32, U1.35 (RS3)
A10: J4.18, U3.1 (A0)
A11: J4.16, U3.2 (A1)
A12: J4.14, U3.3 (A2)
A13: J4.12, U3.4 (~E0)
A14: J4.10, U3.5 (~E1)
A15: J4.8, U3.6 (E2)
CA1: J2.11, J5.19, U1.40 (CA1), U2.14 (PD0)
CA2: J2.12, J5.6, U1.39 (CA2), U2.15 (PD1)
CB1: J1.11, J5.20, U1.18 (CB1), U2.18 (PD4)
CB2: J1.12, J5.8, U1.19 (CB2), U2.19 (PD5)
CSB: J6.2, J6.4, J6.6, J6.8, J6.10, J6.12, J6.14, J6.16, U1.23 (CS2B)
D0: J4.37, U1.33 (D0)
D1: J4.35, U1.32 (D1)
D2: J4.33, U1.31 (D2)
D3: J4.31, U1.30 (D3)
D4: J4.29, U1.29 (D4)
D5: J4.27, U1.28 (D5)
D6: J4.25, U1.27 (D6)
D7: J4.23, U1.26 (D7)
GND: C1.1, C2.2, C3.1, C4.2, C5.1, C6.2, C7.2, C8.1, J1.2, J2.2, J3.3, J4.1, J4.40, J5.7, J5.14, J5.25, J5.SH (PAD), U1.1 (VSS), U2.11 (GND), U2.31 (GND), U3.8 (GND)
IRQB: D1.2 (A), J4.5, JP1.2 (B)
unnamed: D1.1 (K), JP1.1 (A), U1.21 (IRQB)
unnamed: C5.2, U2.32 (AREF)
unnamed: C2.1, U2.13 (XTAL1), Y1.2
unnamed: C4.1, U2.12 (XTAL2), Y1.1
unnamed: R1.2, U2.9 (~RESET)
PA0: J2.4, J5.2, U1.2 (PA0), U2.40 (PA0)
PA1: J2.6, J5.15, U1.3 (PA1), U2.39 (PA1)
PA2: J2.8, J5.3, U1.4 (PA2), U2.38 (PA2)
PA3: J2.10, J5.16, U1.5 (PA3), U2.37 (PA3)
PA4: J2.9, J5.4, U1.6 (PA4), U2.36 (PA4)
PA5: J2.7, J5.17, U1.7 (PA5), U2.35 (PA5)
PA6: J2.5, J5.5, U1.8 (PA6), U2.34 (PA6)
PA7: J2.3, J5.18, U1.9 (PA7), U2.33 (PA7)
PB0: J1.4, J5.12, U1.10 (PB0), U2.1 (PB0)
PB1: J1.6, J5.24, U1.11 (PB1), U2.2 (PB1)
PB2: J1.8, J5.11, U1.12 (PB2), U2.3 (PB2)
PB3: J1.10, J5.23, U1.13 (PB3), U2.4 (PB3)
PB4: J1.9, J5.10, U1.14 (PB4), U2.5 (PB4)
PB5: J1.7, J5.22, U1.15 (PB5), U2.6 (PB5)
PB6: J1.5, J5.9, U1.16 (PB6), U2.7 (PB6)
PB7: J1.3, J5.21, U1.17 (PB7), U2.8 (PB7)
PHI2: J4.17, U1.25 (PHI2)
PS2CLK: J3.5, U2.16 (PD2)
PS2DATA: J3.1, U2.17 (PD3)
RESB: J4.3, U1.34 (RESB)
RWB: J4.13, U1.22 (RWB)
VCC: C1.2, C3.2, C6.1, C7.1, C8.2, J1.1, J2.1, J3.4, J4.2, J4.39, J5.1, J5.13, R1.1, U1.20 (VDD), U1.24 (CS1), U2.10 (VCC), U2.30 (AVCC), U3.16 (VCC)

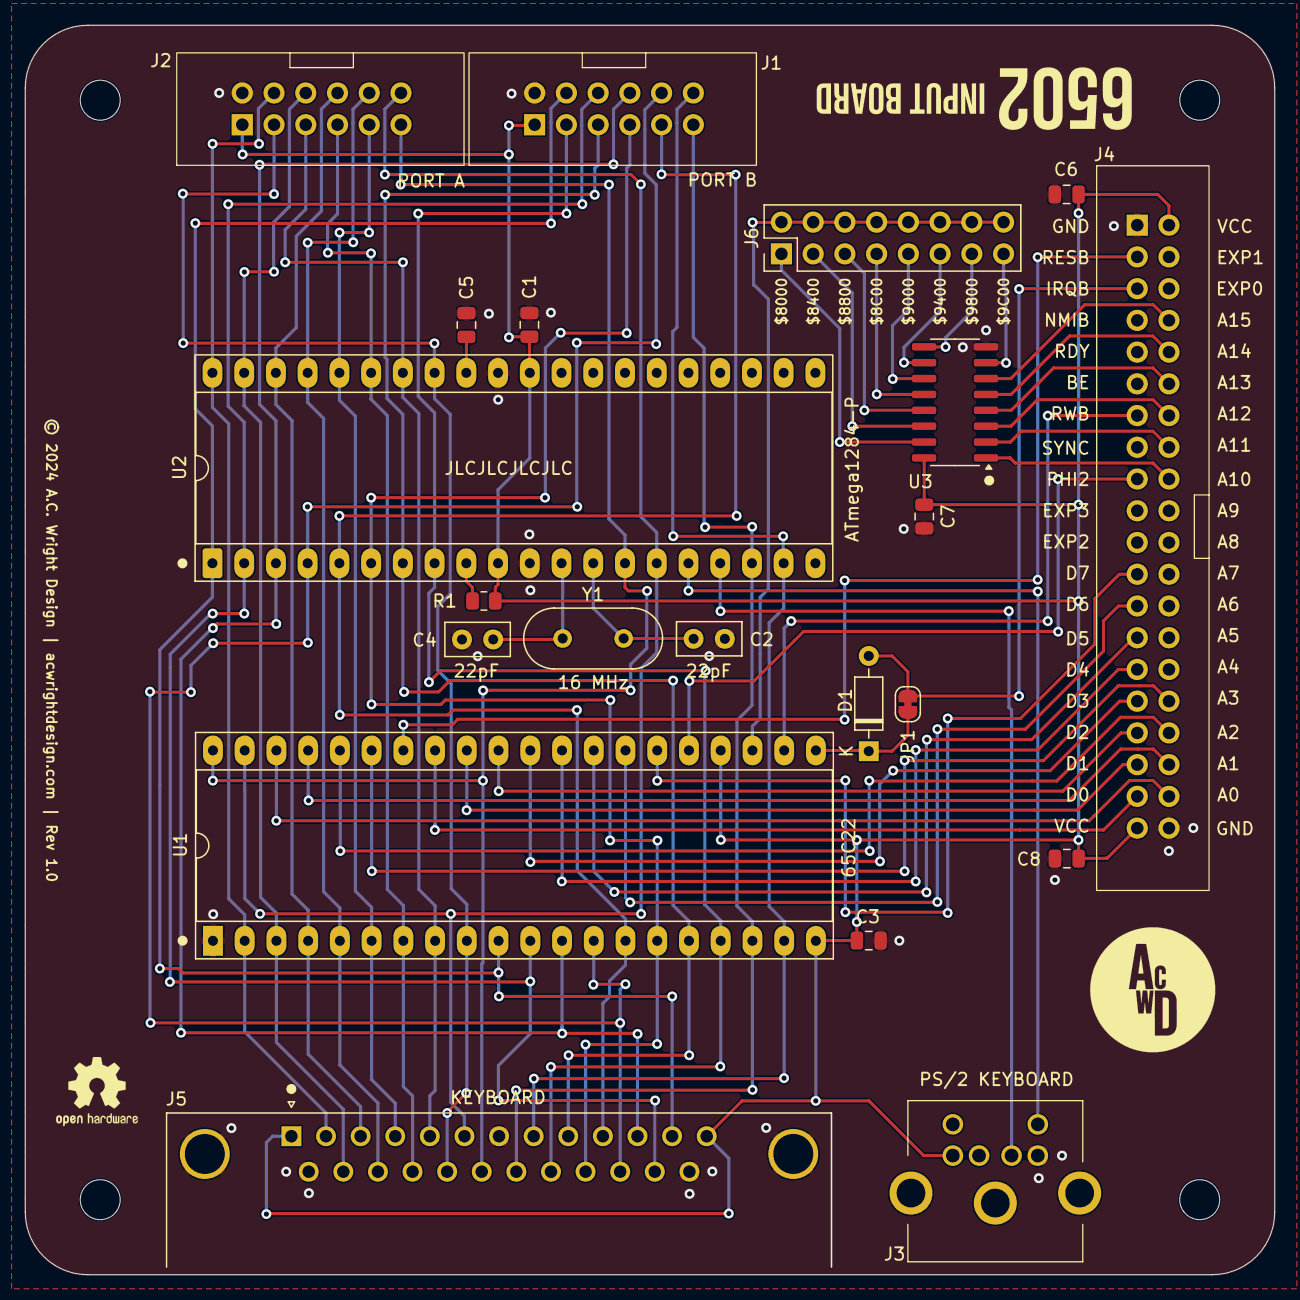
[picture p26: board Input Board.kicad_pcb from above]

Board: 2 copper layers, 100.0 x 100.0 mm, 25 parts (0 on the bottom side), 60 nets.

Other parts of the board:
H1, H2, H3, H4: MountingHole; MountingHole_3.2mm_M3

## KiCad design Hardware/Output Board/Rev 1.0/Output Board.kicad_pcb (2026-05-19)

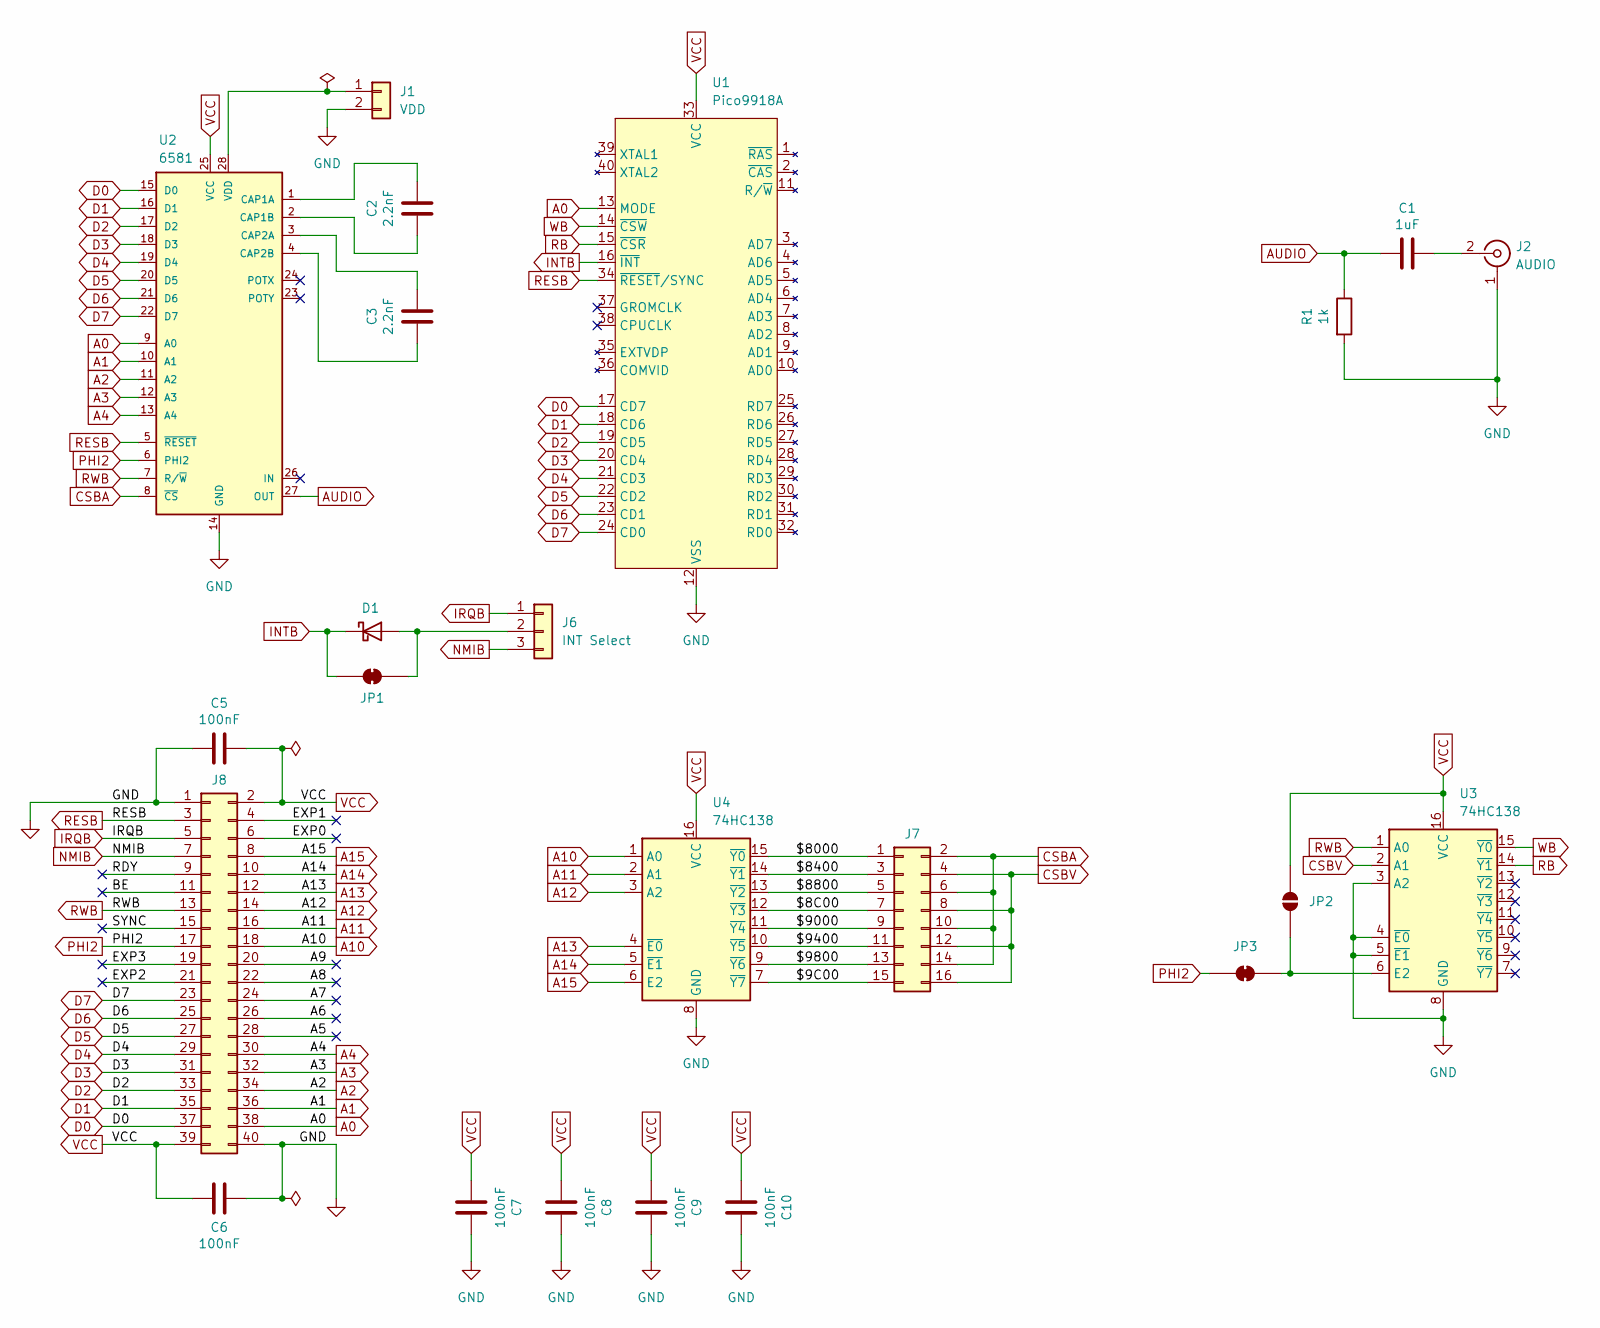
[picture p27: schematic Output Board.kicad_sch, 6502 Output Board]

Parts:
C1: 1uF; C_0805_2012Metric; LCSC C28323
C2, C3: 2.2nF; C_0805_2012Metric; LCSC C28260
C5, C6, C7, C8, C9, C10: 100nF; C_0805_2012Metric; LCSC C49678
D1: 1N914; D_DO-35_SOD27_P7.62mm_Horizontal; Digikey 1N914FS-ND
J1: VDD; JST_XH_B2B-XH-A_1x02_P2.50mm_Vertical; Digikey 455-2247-ND
J2: AUDIO; SWITCHCRAFT_PJRAN1X1U02X; Digikey PJRAN1X1U02X-ND
J6: INT Select; PinHeader_1x03_P2.54mm_Vertical
J7: IO SELECT; PinHeader_2x08_P2.54mm_Vertical
J8: 6502 Bus; 6502 Bus Connector
JP1, JP3: SolderJumper_2_Bridged; SolderJumper-2_P1.3mm_Bridged_RoundedPad1.0x1.5mm
JP2: SolderJumper_2_Open; SolderJumper-2_P1.3mm_Open_RoundedPad1.0x1.5mm
R1: 1k; R_0805_2012Metric; LCSC C17513
U1: Pico9918A; DIP_Socket-40_W11.9mm_W12.7mm_W15.24mm_W17.78mm_W18.5mm_3M_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
U2: 6581; DIP_Socket-28_W11.9mm_W12.7mm_W15.24mm_W17.78mm_W18.5mm_3M_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
U3, U4: 74HC138; SOIC-16_3.9x9.9mm_P1.27mm; LCSC C5602

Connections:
/$8C00: J7.7, U4.12 (~Y3)
/$9C00: J7.15, U4.7 (~Y7)
/$8000: J7.1, U4.15 (~Y0)
/$8400: J7.3, U4.14 (~Y1)
/$8800: J7.5, U4.13 (~Y2)
/$9000: J7.9, U4.11 (~Y4)
/$9400: J7.11, U4.10 (~Y5)
/$9800: J7.13, U4.9 (~Y6)
/A5: J8.28
/A6: J8.26
/A7: J8.24
/A8: J8.22
/A9: J8.20
/BE: J8.11
/EXP0: J8.6
/EXP1: J8.4
/EXP2: J8.21
/EXP3: J8.19
/RDY: J8.9
/SYNC: J8.15
A0: J8.38, U1.13 (MODE), U2.9 (A0)
A1: J8.36, U2.10 (A1)
A2: J8.34, U2.11 (A2)
A3: J8.32, U2.12 (A3)
A4: J8.30, U2.13 (A4)
A10: J8.18, U4.1 (A0)
A11: J8.16, U4.2 (A1)
A12: J8.14, U4.3 (A2)
A13: J8.12, U4.4 (~E0)
A14: J8.10, U4.5 (~E1)
A15: J8.8, U4.6 (E2)
AUDIO: C1.1, R1.1, U2.27 (OUT)
CSBA: J7.2, J7.6, J7.10, J7.14, U2.8 (~CS)
CSBV: J7.4, J7.8, J7.12, J7.16, U3.2 (A1)
D0: J8.37, U1.17 (CD7), U2.15 (D0)
D1: J8.35, U1.18 (CD6), U2.16 (D1)
D2: J8.33, U1.19 (CD5), U2.17 (D2)
D3: J8.31, U1.20 (CD4), U2.18 (D3)
D4: J8.29, U1.21 (CD3), U2.19 (D4)
D5: J8.27, U1.22 (CD2), U2.20 (D5)
D6: J8.25, U1.23 (CD1), U2.21 (D6)
D7: J8.23, U1.24 (CD0), U2.22 (D7)
GND: C5.2, C6.1, C7.2, C8.2, C9.2, C10.2, J1.2, J2.1 (Ext), J8.1, J8.40, R1.2, U1.12 (VSS), U2.14 (GND), U3.3 (A2), U3.4 (~E0), U3.5 (~E1), U3.8 (GND), U4.8 (GND)
INTB: D1.1 (K), JP1.1 (A), U1.16 (~INT)
IRQB: J6.1, J8.5
NMIB: J6.3, J8.7
unnamed: D1.2 (A), J6.2, JP1.2 (B)
unnamed: J1.1, U2.28 (VDD)
unnamed: C1.2, J2.2 (In)
unnamed: JP2.2 (B), JP3.1 (A), U3.6 (E2)
unnamed: C2.2, U2.1 (CAP1A)
unnamed: C2.1, U2.2 (CAP1B)
unnamed: C3.2, U2.3 (CAP2A)
unnamed: C3.1, U2.4 (CAP2B)
PHI2: J8.17, JP3.2 (B), U2.6 (PHI2)
RB: U1.15 (~CSR), U3.14 (~Y1)
RESB: J8.3, U1.34 (~RESET/SYNC), U2.5 (~RESET)
RWB: J8.13, U2.7 (R/~W), U3.1 (A0)
VCC: C5.1, C6.2, C7.1, C8.1, C9.1, C10.1, J8.2, J8.39, JP2.1 (A), U1.33 (VCC), U2.25 (VCC), U3.16 (VCC), U4.16 (VCC)
WB: U1.14 (~CSW), U3.15 (~Y0)

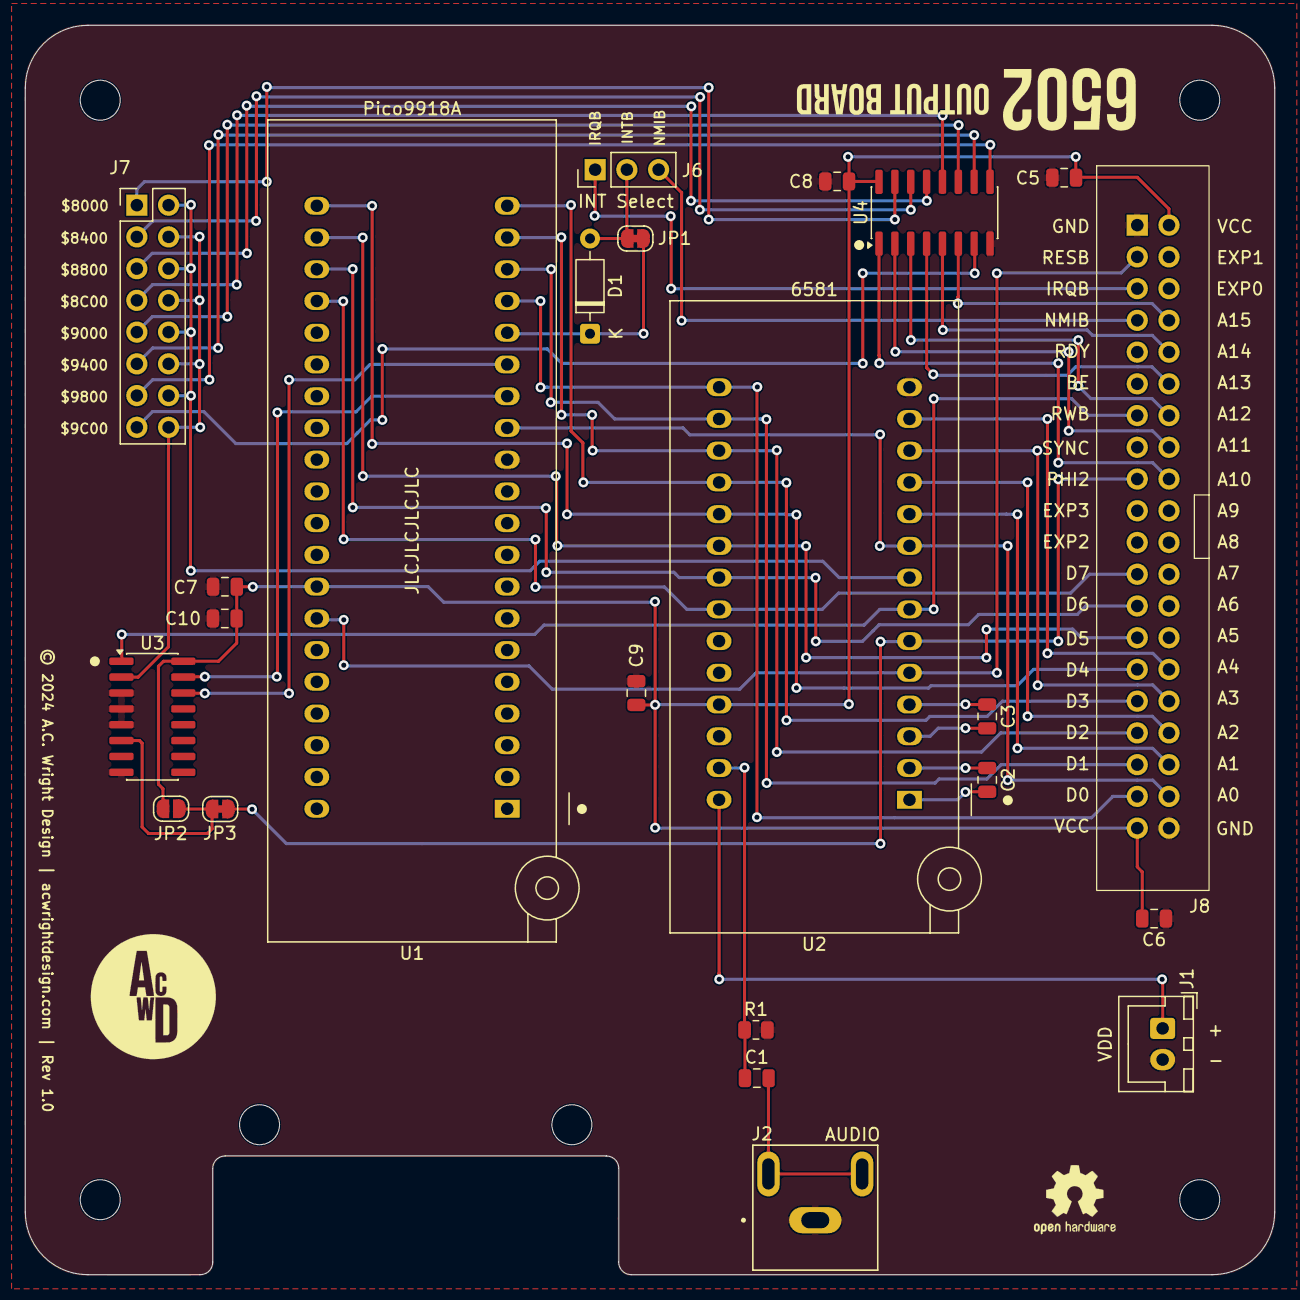
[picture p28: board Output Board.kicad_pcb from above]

Board: 2 copper layers, 100.0 x 100.0 mm, 27 parts (0 on the bottom side), 48 nets.

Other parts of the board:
H1, H2, H3, H4: MountingHole; MountingHole_3.2mm_M3

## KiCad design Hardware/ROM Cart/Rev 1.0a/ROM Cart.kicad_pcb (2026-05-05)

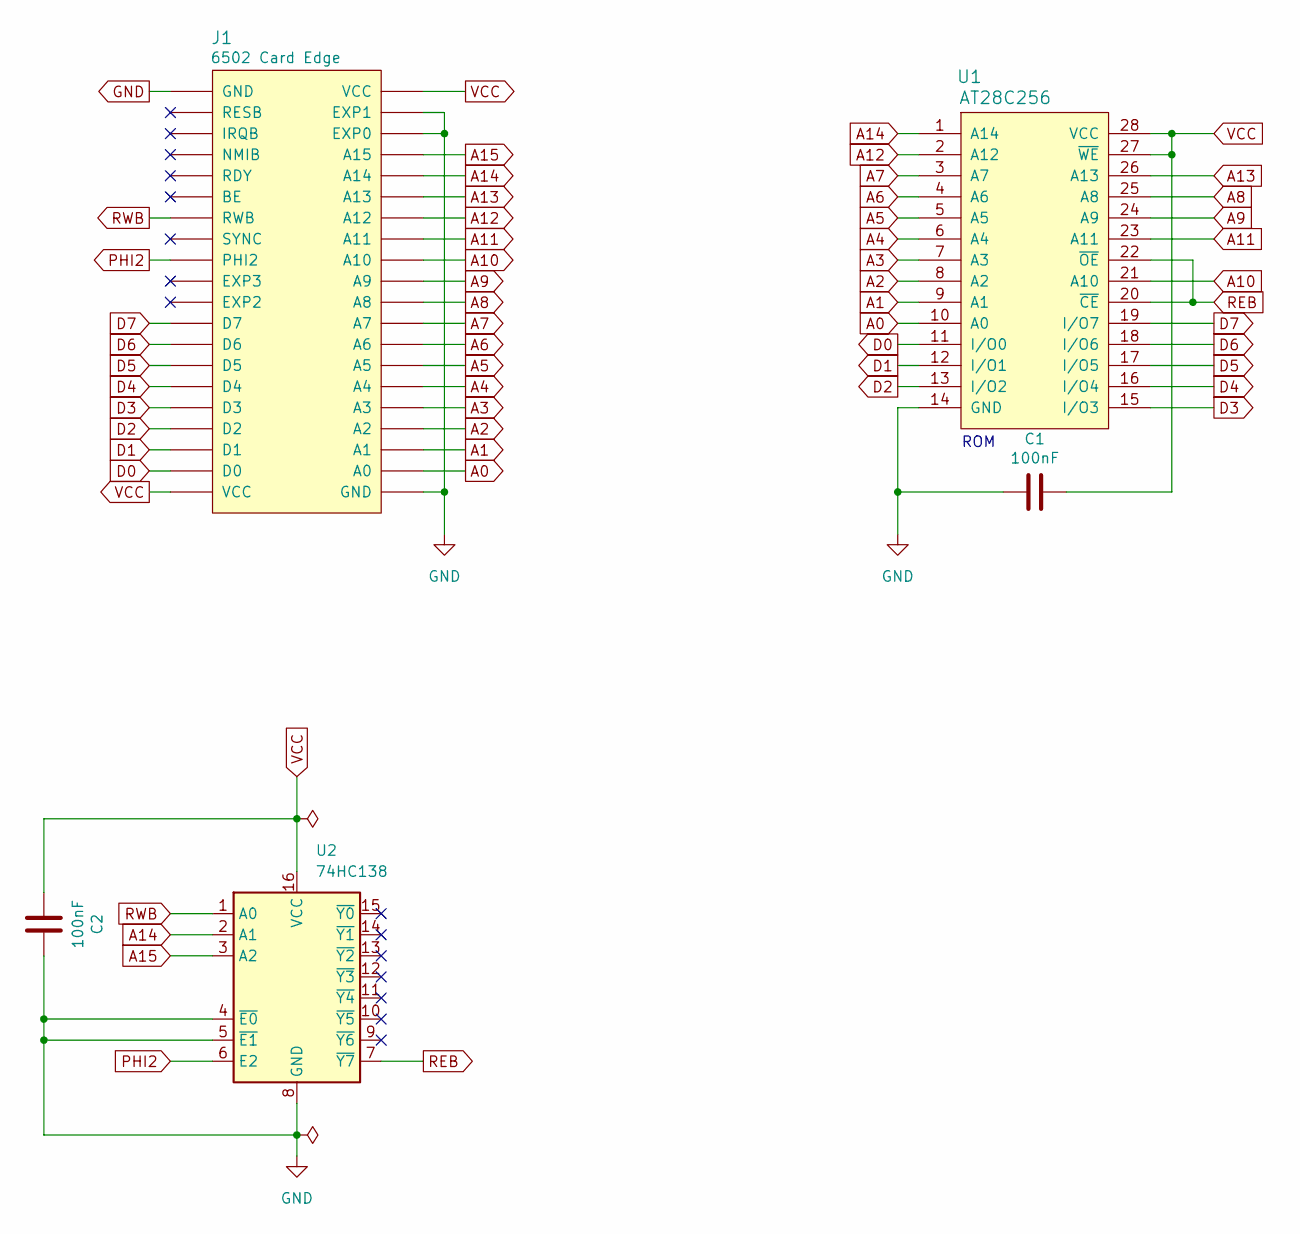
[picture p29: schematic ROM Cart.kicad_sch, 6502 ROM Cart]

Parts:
C1, C2: 100nF; C_Disc_D5.0mm_W2.5mm_P5.00mm
J1: 6502 Card Edge
U1: AT28C256; DIP-28_W15.24mm_Socket_LongPads
U2: 74HC138; DIP-16_W7.62mm_Socket_LongPads

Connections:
A0: J1.A0, U1.10 (A0)
A1: J1.A1, U1.9 (A1)
A2: J1.A2, U1.8 (A2)
A3: J1.A3, U1.7 (A3)
A4: J1.A4, U1.6 (A4)
A5: J1.A5, U1.5 (A5)
A6: J1.A6, U1.4 (A6)
A7: J1.A7, U1.3 (A7)
A8: J1.A8, U1.25 (A8)
A9: J1.A9, U1.24 (A9)
A10: J1.A10, U1.21 (A10)
A11: J1.A11, U1.23 (A11)
A12: J1.A12, U1.2 (A12)
A13: J1.A13, U1.26 (A13)
A14: J1.A14, U1.1 (A14), U2.2 (A1)
A15: J1.A15, U2.3 (A2)
D0: J1.D0, U1.11 (I/O0)
D1: J1.D1, U1.12 (I/O1)
D2: J1.D2, U1.13 (I/O2)
D3: J1.D3, U1.15 (I/O3)
D4: J1.D4, U1.16 (I/O4)
D5: J1.D5, U1.17 (I/O5)
D6: J1.D6, U1.18 (I/O6)
D7: J1.D7, U1.19 (I/O7)
GND: C1.2, C2.2, J1.EXP0, J1.EXP1, J1.GND, U1.14 (GND), U2.4 (~E0), U2.5 (~E1), U2.8 (GND)
PHI2: J1.PHI2, U2.6 (E2)
RB: U1.20 (~CE), U1.22 (~OE), U2.7 (~Y7)
RWB: J1.RWB, U2.1 (A0)
VCC: C1.1, C2.1, J1.VCC, U1.27 (~WE), U1.28 (VCC), U2.16 (VCC)

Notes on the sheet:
ROM

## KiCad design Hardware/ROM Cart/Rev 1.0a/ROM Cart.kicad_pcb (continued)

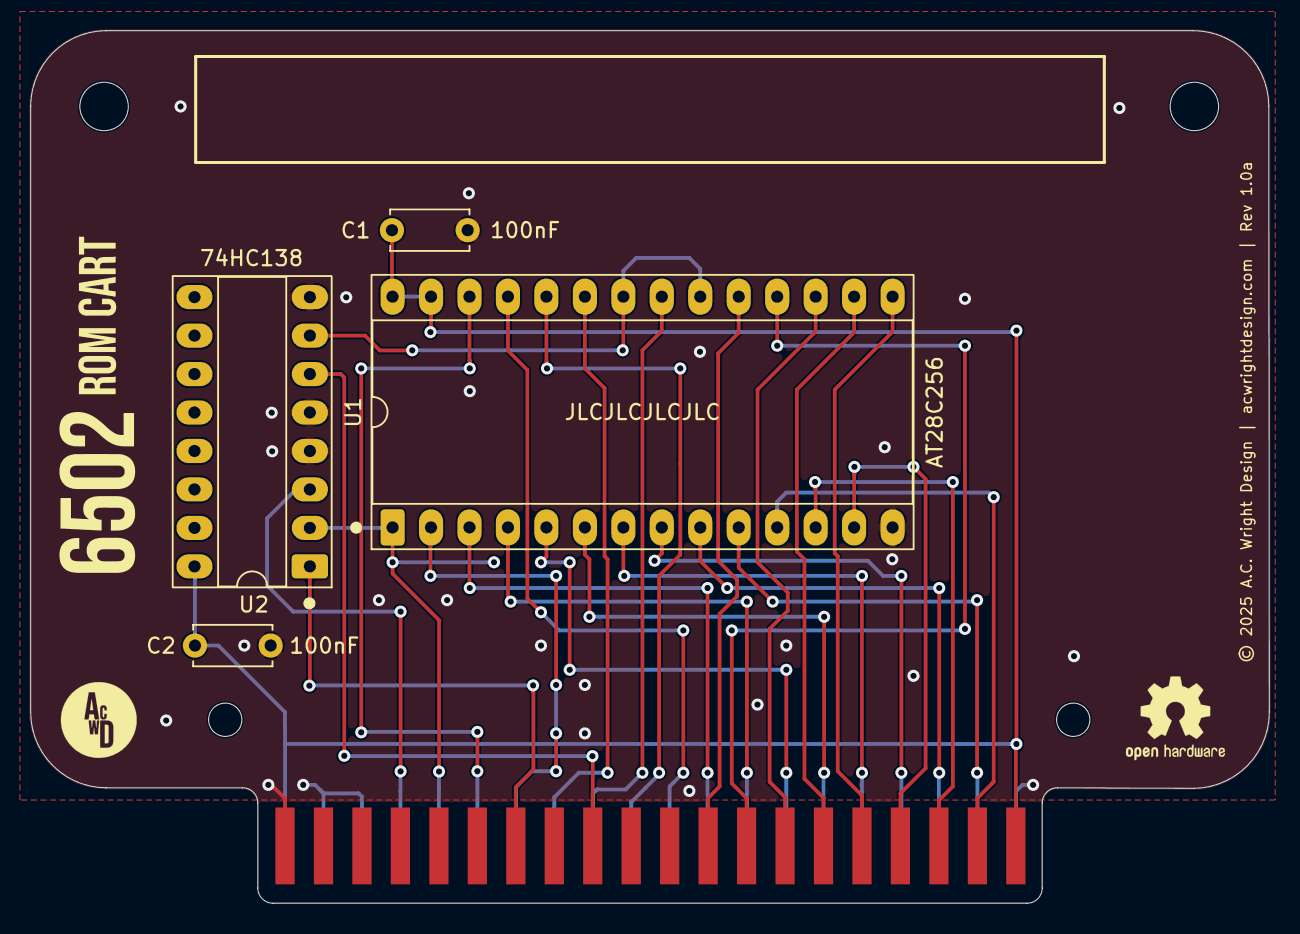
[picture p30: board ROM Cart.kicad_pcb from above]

Board: 2 copper layers, 81.8 x 57.6 mm, 9 parts (0 on the bottom side), 29 nets.

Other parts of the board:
H1, H2: MountingHole; MountingHole_3.2mm_M3
H3, H4: MountingHole; MountingHole_2.2mm_M2

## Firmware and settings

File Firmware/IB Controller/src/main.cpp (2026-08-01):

#define CIRCULAR_BUFFER_INT_SAFE

#include <Arduino.h>
#include <CircularBuffer.hpp>

// ============================================================================
// Keyboard Matrix Mapping 
// ============================================================================
// Rows: PA0-PA7 (VIA Port A)
// Columns: PB0-PB7 (VIA Port B)
//
//      PB0    PB1    PB2    PB3    PB4    PB5    PB6    PB7
// PA0:  `      1      2      3      4      5      6      7
// PA1:  8      9      0      -      =      BS     ESC    TAB
// PA2:  q      w      e      r      t      y      u      i
// PA3:  o      p      [      ]      \      INS    CAPS   a
// PA4:  s      d      f      g      h      j      k      l
// PA5:  ;      '      ENTER  DEL    SHIFT  z      x      c
// PA6:  v      b      n      m      ,      .      /      UP
// PA7:  CTRL   GUI    ALT    SPACE  FN     LEFT   DOWN   RIGHT
//
// Notes:
// - BS = Backspace (0x08), ESC = Escape (0x1B), TAB (0x09)
// - INS = Insert (0x1A), DEL = Delete (0x7F), ENTER (0x0D)
// - Arrow keys: UP (0x1E), LEFT (0x1C), DOWN (0x1F), RIGHT (0x1D)
// - Function keys F1-F10 are mapped as FN + number keys 1-0
// ============================================================================

// ATMega1284 PORT A / 6522 VIA PORT A
#define VIA_PA0 24
#define VIA_PA1 25
#define VIA_PA2 26
#define VIA_PA3 27
#define VIA_PA4 28
#define VIA_PA5 29
#define VIA_PA6 30
#define VIA_PA7 31

// ATMega1284 PORT B / 6522 VIA PORT B
#define VIA_PB0 0
#define VIA_PB1 1
#define VIA_PB2 2
#define VIA_PB3 3
#define VIA_PB4 4
#define VIA_PB5 5
#define VIA_PB6 6
#define VIA_PB7 7

#define VIA_CA1 8
#define VIA_CA2 9
#define PS2CLK  10
#define PS2DATA 11
#define VIA_CB1 12
#define VIA_CB2 13

#define BUFFER_SIZE 16

CircularBuffer<uint8_t, BUFFER_SIZE> ps2Buffer;  // Buffer for PS/2 keyboard data
CircularBuffer<uint8_t, BUFFER_SIZE> matrixBuffer;  // Buffer for matrix keyboard data

// PS/2 keyboard state
bool ps2Enabled = false;
bool shiftPressed = false;
bool ctrlPressed = false;
bool breakCodeNext = false;
bool extendedCodeNext = false;

// Matrix keyboard state
bool matrixEnabled = false;
bool matrixShiftPressed = false;
bool matrixCtrlPressed = false;

// Matrix key debouncing
uint8_t matrixKeyState[8][8] = {0};  // Current state of each key
uint8_t matrixKeyLast[8][8] = {0};   // Last state of each key
unsigned long matrixLastScan = 0;
uint8_t matrixScanRow = 0;   // Next row to scan; an interrupted sweep resumes here
#define MATRIX_SCAN_INTERVAL 10  // Scan every 10ms
#define MATRIX_DEBOUNCE_COUNT 2  // Key must be stable for 2 scans

// ============================================================================
// Joystick State
// ============================================================================
// The two sticks share the sixteen VIA port lines with the key matrix:
// JOYSTICK A on PA0-PA7 (the matrix rows) and JOYSTICK B on PB0-PB7 (the
// columns). Every signal is active low -- the switches close to ground -- so an
// untouched stick leaves its lines pulled high.
//
// Nothing about the sticks is sent to the 6502 from here. The 6502 reads them
// itself: Kernal KBDisable takes both encoders offline, this ATmega goes
// high-impedance, and the 6502 reads the raw ports with the sticks the only
// things pulling on them. That is the same arrangement a C64 has, it needs no
// wire protocol, and it is the only way both sticks can be read reliably --
// anything this encoder drives onto a port is fighting the switches wired to
// those same eight lines.
//
// What the firmware does need is to know which lines a stick is holding down.
// A held signal pins its line low for as long as it is held, and every key
// along that row or column then reads as pressed. These masks keep the sticks
// out of the matrix scan.
uint8_t joyRowMask = 0;   // PA lines JOYSTICK A is holding low -> unscannable rows
uint8_t joyColMask = 0;   // PB lines JOYSTICK B is holding low -> unscannable columns

void onInterrupt();
void enablePS2();
void disablePS2();
void enableMatrix();
void disableMatrix();
void ps2ToAscii(uint8_t scancode);
bool scanMatrix();
uint8_t mapMatrixToAscii(uint8_t row, uint8_t col);
void serviceEncoderEnables();
bool settleBetweenCharacters();
bool matrixRowConflict();
bool writePortA(uint8_t value);
bool writePortB(uint8_t value);
void sampleJoystickMasks();

// ============================================================================
// VIA Port Access
// ============================================================================
// On the MightyCore "standard" pinout VIA_PA0-PA7 are D24-D31, which is exactly
// ATmega PORTA bits 0-7, and VIA_PB0-PB7 are D0-D7, which is exactly PORTB bits
// 0-7. Nothing else on this board lives on either register, so the whole port
// can be manipulated in a single instruction.
//
// That matters in two places. The encoder must let go of a port within 100 us
// of being asked, because that is how the 6502 reads the joysticks at all and
// Kernal KBDisable waits exactly that long before reading. So the release path
// has to be effectively instantaneous, and the scan loop has to be able to
// check for a release request without paying ~4 us per Arduino call.
// Everything that is not on that path keeps using pinMode/digitalRead.
//
// If the VIA_Px pin defines above ever change, these must change with them.

// CA2 (PD1) and CB2 (PD5) are the 6502 asking for a port back, active high.
#define CA2_RELEASE_REQUESTED() (PIND & _BV(PD1))
#define CB2_RELEASE_REQUESTED() (PIND & _BV(PD5))

// True when the 6502 has asked an encoder that is currently enabled -- and so
// currently driving a port -- to release it.
static inline bool releaseRequested() {
  return (matrixEnabled && CB2_RELEASE_REQUESTED()) ||
         (ps2Enabled && CA2_RELEASE_REQUESTED());
}

// ============================================================================
// Keyboard Matrix to ASCII Mapping Table
// ============================================================================
// Maps each matrix position [row][col] to its base ASCII code (no modifiers)
// Special values: 0xFF = no key, 0xFE = modifier key (handled separately)
const uint8_t matrixMap[8][8] PROGMEM = {
  // PA0/Row 0: PB0    PB1    PB2    PB3    PB4    PB5    PB6    PB7
  {             0x60,  0x31,  0x32,  0x33,  0x34,  0x35,  0x36,  0x37 },  // ` 1 2 3 4 5 6 7
  // PA1/Row 1
  {             0x38,  0x39,  0x30,  0x2D,  0x3D,  0x08,  0x1B,  0x09 },  // 8 9 0 - = BS ESC TAB
  // PA2/Row 2
  {             0x51,  0x57,  0x45,  0x52,  0x54,  0x59,  0x55,  0x49 },  // Q W E R T Y U I
  // PA3/Row 3
  {             0x4F,  0x50,  0x5B,  0x5D,  0x5C,  0x1A,  0xFF,  0x41 },  // O P [ ] \ INS (ign) A
  // PA4/Row 4
  {             0x53,  0x44,  0x46,  0x47,  0x48,  0x4A,  0x4B,  0x4C },  // S D F G H J K L
  // PA5/Row 5
  {             0x3B,  0x27,  0x0D,  0x7F,  0xFE,  0x5A,  0x58,  0x43 },  // ; ' ENTER DEL SHIFT Z X C
  // PA6/Row 6
  {             0x56,  0x42,  0x4E,  0x4D,  0x2C,  0x2E,  0x2F,  0x1E },  // V B N M , . / UP
  // PA7/Row 7
  {             0xFE,  0xFF,  0xFF,  0x20,  0xFF,  0x1C,  0x1F,  0x1D }   // CTRL (ign) (ign) SPACE (ign) LEFT DOWN RIGHT
};

void setup() {
  pinMode(VIA_CA1, OUTPUT);
  pinMode(VIA_CA2, INPUT_PULLUP);
  pinMode(VIA_CB1, OUTPUT);
  pinMode(VIA_CB2, INPUT_PULLUP);
  pinMode(PS2CLK, INPUT_PULLUP);
  pinMode(PS2DATA, INPUT_PULLUP);

  digitalWrite(VIA_CA1, HIGH);
  digitalWrite(VIA_CB1, HIGH);
  
  attachInterrupt(digitalPinToInterrupt(PS2CLK), onInterrupt, FALLING);
}

void loop() {
  // Bring both encoders into whatever state CA2/CB2 are asking for
  serviceEncoderEnables();

  // Scan matrix keyboard if enabled. A scan that reports back false was
  // abandoned because the 6502 asked for a port, so service that immediately
  // and start a fresh pass rather than running the output blocks first.
  if (matrixEnabled && !scanMatrix()) {
    serviceEncoderEnables();
    return;
  }

  // Handle PS/2 keyboard output on Port A. The character is only consumed once
  // it has actually been strobed, so one abandoned mid-write cannot be lost.
  if (ps2Enabled && !ps2Buffer.isEmpty()) {
    if (!writePortA(ps2Buffer.first())) {
      serviceEncoderEnables();
      return;
    }
    ps2Buffer.shift();
    if (!settleBetweenCharacters()) {
      serviceEncoderEnables();
      return;
    }
  }

  // Handle matrix keyboard output on Port B
  if (matrixEnabled && !matrixBuffer.isEmpty() && !matrixRowConflict()) {
    if (!writePortB(matrixBuffer.first())) {
      serviceEncoderEnables();
      return;
    }
    matrixBuffer.shift();
    if (!settleBetweenCharacters()) {
      serviceEncoderEnables();
      return;
    }
  }
}

// Poll CA2/CB2 and bring each encoder into the state the 6502 is asking for.
// Called at the top of loop() and again the moment any longer-running section
// notices a release request, so a port is never held past its budget just
// because the firmware was busy elsewhere.
void serviceEncoderEnables() {
  // Check PS/2 enable/disable (CA2)
  int ps2EnableState = digitalRead(VIA_CA2);
  if (ps2EnableState == LOW && !ps2Enabled) {
    enablePS2();
  } else if (ps2EnableState == HIGH && ps2Enabled) {
    disablePS2();
  }

  // Check matrix enable/disable (CB2)
  int matrixEnableState = digitalRead(VIA_CB2);
  if (matrixEnableState == LOW && !matrixEnabled) {
    enableMatrix();
  } else if (matrixEnableState == HIGH && matrixEnabled) {
    disableMatrix();
  }
}

// The settle gap the 6502 needs between strobes. Spent in short slices with a
// release check between each, rather than blocking for the whole 100 us, so a
// request arriving just after a strobe is still answered on time. Returns false
// if one arrived, in which case the caller must stop what it is doing.
bool settleBetweenCharacters() {
  for (uint8_t i = 0; i < 10; i++) {
    if (releaseRequested()) {
      return false;
    }
    delayMicroseconds(10);
  }
  return true;
}

// When two keys on the same row are held simultaneously, their switches bridge
// Port B columns through the shared row wire.  This corrupts anything driven on
// Port B because the ATmega's output drivers fight each other through that
// path.  Output is deferred until no row has multiple pressed keys.
bool matrixRowConflict() {
  for (uint8_t row = 0; row < 8; row++) {
    uint8_t count = 0;
    for (uint8_t col = 0; col < 8; col++) {
      if (matrixKeyState[row][col] >= MATRIX_DEBOUNCE_COUNT) {
        if (++count >= 2) {
          return true;
        }
      }
    }
  }
  return false;
}

// Drive a byte onto Port A and strobe CA1. Matrix scanning parks the row lines
// as inputs, so the direction has to be re-asserted on every write.
//
// Returns false if the 6502 asked for the port before the strobe went out, in
// which case nothing was signalled and the caller must keep the byte queued.
// This matters more than it looks: BASIC evaluating JOY() disables the encoders
// every time, so a release landing in the middle of a character write is a
// routine event rather than a rarity. Strobing a port that is about to be
// released would leave the 6502's ISR reading joystick lines and buffering them
// as a keystroke.
bool writePortA(uint8_t value) {
  // Nothing has been committed to the wire yet, so bail before touching the
  // port at all if the 6502 has already asked for it
  if (releaseRequested()) {
    return false;
  }

  // Value before direction: while the port is still an input this only sets
  // pullups, so the byte is never half-driven on its way out
  PORTA = value;
  DDRA = 0xFF;

  if (releaseRequested()) {
    return false;
  }

  digitalWrite(VIA_CA1, LOW); // Signal that data is ready
  delayMicroseconds(5);
  digitalWrite(VIA_CA1, HIGH);
  return true;
}

// Drive a byte onto Port B and strobe CB1. Port A (the row lines) is parked
// high-impedance first, so a single pressed key cannot short a driven column
// back into a driven row through its switch. Returns false without strobing if
// the 6502 asked for the port first -- see writePortA.
bool writePortB(uint8_t value) {
  if (releaseRequested()) {
    return false;
  }

  // Park the row lines as pulled-up inputs first
  DDRA = 0x00;
  PORTA = 0xFF;

  // Value before direction -- see writePortA
  PORTB = value;
  DDRB = 0xFF;

  if (releaseRequested()) {
    return false;
  }

  digitalWrite(VIA_CB1, LOW); // Signal that data is ready
  delayMicroseconds(5);
  digitalWrite(VIA_CB1, HIGH);
  return true;
}

void enablePS2() {
  ps2Enabled = true;

  // Set Port A as output for PS/2 data. PORTA already reads 0xFF from the
  // released state, so the lines idle high rather than briefly presenting
  // whatever was last driven.
  DDRA = 0xFF;
}

void disablePS2() {
  ps2Enabled = false;

  // Release Port A unconditionally: CA2 going high is the 6502 asking for the
  // port, and it is not conditional on what the matrix is doing. scanMatrix()
  // drives the row lines itself and parks them between passes, so there is
  // nothing here worth preserving for it -- whereas the old `if (!matrixEnabled)`
  // guard meant that with the matrix enabled this path never let go of Port A
  // at all.
  //
  // Parked with the internal pullups on, not bare, because this is exactly the
  // state the 6502 reads the joysticks in. Only the ACE Board carries the 1k
  // port pullups itself; on COB and VCS they arrive with a helper board, so a
  // port with nothing fitted would otherwise float and read as noise instead of
  // as an untouched stick. ~30k is far too weak to fight a joystick switch, or
  // a cartridge driving its own matrix rows.
  //
  // Straight at the registers: this is the tail of the release path the 6502
  // waits on, and eight pinMode() calls would add ~36 us to it for no reason.
  DDRA = 0x00;
  PORTA = 0xFF;
}

void enableMatrix() {
  matrixEnabled = true;

  // Port B carries column reading and data output; idle driving high
  PORTB = 0xFF;
  DDRB = 0xFF;

  // Port A is left as pulled-up inputs rather than driven. scanMatrix() takes
  // it a row at a time and writePortB() parks it, so nothing here needs it as
  // an output -- and driving it would put either all rows high against a
  // joystick holding one low, or all rows low against the columns.
  if (!ps2Enabled) {
    DDRA = 0x00;
    PORTA = 0xFF;
  }

  // Start a fresh sweep rather than resuming one abandoned before the matrix
  // was last disabled
  matrixScanRow = 0;
}

void disableMatrix() {
  matrixEnabled = false;

  // Release Port B, parked with the internal pullups on so the 6502 reads an
  // untouched stick as all-ones even on a board with no external pullups
  // fitted, and straight at the registers so the release is immediate (see
  // disablePS2 for both).
  DDRB = 0x00;
  PORTB = 0xFF;

  // Release Port A too if PS/2 is not using it
  if (!ps2Enabled) {
    DDRA = 0x00;
    PORTA = 0xFF;
  }
}

// ============================================================================
// Matrix Keyboard Scanning
// ============================================================================

// Put the ports back where the rest of the firmware expects them when a scan is
// abandoned part way through. The row lines are only ever driven during a scan
// so they are always safe to drop; the columns are only released if Port B is
// what the 6502 actually asked for, otherwise they go back to idling high.
static inline void abandonScanPorts() {
  DDRA = 0x00;    // Rows -> input, pullups on
  PORTA = 0xFF;

  if (CB2_RELEASE_REQUESTED()) {
    DDRB = 0x00;  // Columns -> input, pullups on; the 6502 wants Port B
    PORTB = 0xFF;
  } else {
    PORTB = 0xFF; // Columns -> back to driving idle high
    DDRB = 0xFF;
  }
}

// Scan the keyboard matrix for key presses. Returns false if the sweep was
// abandoned because the 6502 asked for a port back, in which case the caller
// must service that before doing anything else.
bool scanMatrix() {
  // An abandoned sweep resumes from the row it stopped on rather than starting
  // over. That matters because the 6502 now takes the ports every time BASIC
  // evaluates JOY(): a tight polling loop would restart the sweep indefinitely
  // and no keystroke would ever be detected. Resuming also keeps the debounce
  // arithmetic exact -- still one update per key per completed sweep, however
  // many pieces the sweep ended up in.
  if (matrixScanRow == 0) {
    // Throttle the *start* of a sweep to MATRIX_SCAN_INTERVAL
    unsigned long currentTime = millis();
    if (currentTime - matrixLastScan < MATRIX_SCAN_INTERVAL) {
      return true;
    }
    matrixLastScan = currentTime;
  }

  // Phase 1: Scan all rows, update debounce state only.
  //
  // Row and column bits are carried as rolling masks rather than recomputed as
  // (1 << n) each time. The AVR has no barrel shifter, so a variable shift
  // compiles to a loop -- and one inside the eight-column loop cost ~30 us per
  // row, which would have dominated the release latency this whole section
  // exists to bound.
  uint8_t rowBit = (uint8_t)(1 << matrixScanRow);

  for (uint8_t row = matrixScanRow; row < 8; row++, rowBit <<= 1) {
    // Give the port up the moment the 6502 asks for it instead of finishing the
    // sweep first -- this is what bounds the release latency Kernal KBDisable
    // waits on. The checks are spread through the row so that no single stretch
    // of Arduino pin calls can run long between two of them.
    if (releaseRequested()) { matrixScanRow = row; abandonScanPorts(); return false; }

    // A row whose PA line JOYSTICK A is holding low reads as every key on that
    // row being pressed. Skip those rows rather than believe them -- this is
    // where the phantom keystrokes came from.
    if (joyRowMask & rowBit) {
      continue;
    }

    // Drive only the active row LOW; all others high-Z with their pullups off,
    // so no current leaks through pressed keys on inactive rows (ghosting).
    // PORT before DDR, always: enabling the driver first would briefly put the
    // previous contents of PORTA onto lines a joystick may be holding low.
    PORTA = 0x00;
    DDRA = rowBit;

    if (releaseRequested()) { matrixScanRow = row; abandonScanPorts(); return false; }

    // Columns to inputs with pullups for reading
    DDRB = 0x00;
    PORTB = 0xFF;

    // Small delay to let signals stabilize. Sized for the weak case -- a port
    // with no external pullup fitted, charging the bus through the ~30k
    // internal one -- and it is a physical wait, not an instruction count.
    delayMicroseconds(10);

    if (releaseRequested()) { matrixScanRow = row; abandonScanPorts(); return false; }

    // One read gets all eight columns (LOW = pressed, HIGH = not pressed).
    // Both it and the mask are shifted down a bit per iteration so the loop
    // stays constant-time -- see the note above the row loop.
    uint8_t cols = PINB;
    uint8_t colBits = joyColMask;

    for (uint8_t col = 0; col < 8; col++, cols >>= 1, colBits >>= 1) {
      // A column JOYSTICK B is holding low reads as every key in it being
      // pressed, exactly as a held row does. Skip those too.
      if (colBits & 1) {
        continue;
      }

      bool pressed = ((cols & 1) == 0);

      // Debounce logic
      if (pressed) {
        if (matrixKeyState[row][col] < MATRIX_DEBOUNCE_COUNT) {
          matrixKeyState[row][col]++;
        }
      } else {
        if (matrixKeyState[row][col] > 0) {
          matrixKeyState[row][col]--;
        }
      }
    }

    // This row's debounce update is complete, so resume from the next one
    if (releaseRequested()) { matrixScanRow = row + 1; abandonScanPorts(); return false; }

    // Restore columns to driving idle high, ready for data transmission
    PORTB = 0xFF;
    DDRB = 0xFF;
  }

  matrixScanRow = 0;  // Sweep complete

  // Release all row lines after scanning, pullups on
  DDRA = 0x00;
  PORTA = 0xFF;

  // Phase 2: Update modifier states from current debounce results
  matrixShiftPressed = (matrixKeyState[5][4] >= MATRIX_DEBOUNCE_COUNT);
  matrixCtrlPressed  = (matrixKeyState[7][0] >= MATRIX_DEBOUNCE_COUNT);
  
  // Phase 3: Fire key events with up-to-date modifier state
  for (uint8_t row = 0; row < 8; row++) {
    for (uint8_t col = 0; col < 8; col++) {
      bool keyPressed = (matrixKeyState[row][col] >= MATRIX_DEBOUNCE_COUNT);
      bool keyWasPressed = matrixKeyLast[row][col];
      
      // Detect key press event (transition from not pressed to pressed)
      if (keyPressed && !keyWasPressed) {
        uint8_t ascii = mapMatrixToAscii(row, col);
        if (ascii != 0xFF && ascii != 0xFE) {  // 0xFF = no key, 0xFE = modifier
          matrixBuffer.push(ascii);
        }
      }
      
      matrixKeyLast[row][col] = keyPressed;
    }
  }

  // Phase 4: Work out which lines the joysticks are holding down
  sampleJoystickMasks();

  return true;
}

// ============================================================================
// Joystick Sampling
// ============================================================================
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

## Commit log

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2026-08-04 Link the documentation site, and retire the ASSETS pointer
    Adds the guide backlink near the top and replaces 6502-ASSETS with 6502-DOCS in
    the software table, ahead of ASSETS being archived.
    Every reference designator in this README was checked against the schematic of
    the same name, revision by revision, and they agree. (The ACE's did not, and
    were corrected separately.)
2026-09-20 Add the Flash Cart and the Flash Helper that programs it
    The Flash Cart is a banked flash cartridge covering 128KB to 1MB on one
    all-SMD board, depending on which parts are populated. $C000-$DFFF is a
    switchable 8K window selected by a write-only bank register at $E000, and
    $E000-$FFFF is fixed to the primary flash's last 8K, so the vectors and the
    bank-switching code can never be mapped out from under the running program.
    Hardware/Flash Cart/Rev 1.0/DESIGN.md carries the memory map, the logic, the
    JEDEC programming sequences and the build variants.
    The ROM Cart is not replaced. Rev 1.0a and Rev 1.0b stay in the README and in
    the BOM, and every existing .crt keeps building, loading and burn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
2026-09-21 Document the Flash Helper firmware and 6502-flash
    Both READMEs now describe what is there rather than what is planned, and each
    carries the same caveat in the same words: written, built, talking to a Mega
    2560, and never yet connected to a cartridge.
    The firmware README gains the bus cycle as bus.cpp actually performs it, the
    serial protocol in full -- the frame, the CRC-16/XMODEM parameters, all eight
    commands and all seven statuses -- and a section that separates what has been
    proved from what has not. An empty slot can prove the protocol and the error
    paths, and it did; it cannot prove a bus cycle, the bank register or a JEDEC
    sequence, and nothing here claims otherwise.
    It also correct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
2026-11-03 Production: add the CSV files the Main Board Rev 1.0 never had
    Their exports were never committed and no longer exist, so these come from
    Fabrication Toolkit's own table generator, run on the PCB without saving it.
    The same run reproduces the KIM Board's, the Clock Card's and the ACE's CSV
    files byte for byte. Every pad in a regenerated netlist.ipc sits at the same
    position as in the committed one, so these describe the board as produced.
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2026-11-04 Main Board Rev 1.0 back to what JLCPCB made (order Y38)
    There is only one Main Board. It was ordered from the COB project in June 2024, as
    6502-COB 7d050b0, and later edits nudged eight small parts. The PCB and production zip
    return to that order; copper and mask match it. Rev 1.1 already holds the later edits.
    This corrects acdc479: as made, J3's shell pads are connected. They only showed as
    unconnected in the later files. The README's Rev 1.0 limitation is gone.
2026-11-04 Board images: every revision rendered the same way
    Front and back, at 2400 x 1600, on white and with no background, in the black solder
    mask and white silkscreen the boards are made with. They replace images that came from
    two methods, in nine different sizes.
2026-11-05 BOM: one set of part numbers across AC6502
    Writes the shared parts catalogue into every schematic and PCB. Each part now
    has the same Digikey, Mouser, Jameco, LCSC and Other fields. Junk fields imported
    with library parts are gone, and so is MPN, because the Fabrication Toolkit
    falls back to it and put it in bom.csv's LCSC column.
    bom.csv is now an accurate BOM. Only card edges, solder jumpers and test points
    are excluded. A blank LCSC cell means JLCPCB doesn't place the part.
    Where the silk doesn't print it, Value says what to fit: BAT85, R6551AP, 33pF and
    so on. A do-not-fit resistor says so. Made boards whose silk prints an old value
    keep it, and the known issues in BOM.md will cover th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
2026-11-05 BOM.md: every part, by revision, with known issues and cart files
    BOM.md has a parts list for every revision, with Digi-Key, Mouser and other
    sources, how to tell which revision you have, and the known issues that change
    what to buy or fit. BOM/ holds a Digi-Key and a Mouser file for each revision.
    Revisions with soldered parts also have through-hole files that leave them out.
    The README's old BOM tables disagreed with the schematics, so they now link here.
    Revision histories and build notes stay in the README.
    Where the build notes say to fit something else, the lists now order that: 10k
    pull-ups on ACE Board 1.0, CPU Card 1.0, DEV Board 1.0 and Main Board 1.0 and 1.1,
    and no RESB pull-up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
2026-11-05 Everything derived from the boards, brought up to date
    Board images are re-rendered for every revision whose silk or fitted parts
    changed, so they show SERIAL (DTE) and the rest. The revision histories now say
    what changed on the silk, and wording that pointed at the old BOM tables is gone.
    3D model paths that led nowhere are fixed: old KiCad variables, a folder that no
    longer exists, and models KiCad 10 only ships as STEP. Those boards' STEP files
    and images now include all their parts.
    positions.csv no longer lists parts that aren't fitted. Made and ordered boards'
    fabrication exports are unchanged, and so are DRC and schematic parity.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
2026-11-05 BOM: 40- and 32-pin sockets get their part numbers
    BOM.md and carts: socket rows had no part numbers, because the generator
    looked up the wrong catalogue id.
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2026-11-05 Main Board 1.1: switch header values as on the COB boards
    POWER SW, RESET SW and CLOCK ENBL SW, in place of PWR_SW, RESET_SW and
    CLOCK_ENBL_SW. The values are fab-layer only, so the board is unchanged.
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2026-11-05 Library parts named for what they are, not a part number
    Footprints, symbols and 3D models in "6502 Parts" are named for their
    function and shape (RJ45 Jack LED, CR2032 Holder, 6502 Card Slot, Power
    Switch, SID, ACIA 6551, PIA 6521), so a replacement part with the same
    footprint needs no rename. Every repo carries the same copy of each part,
    re-saved by KiCad 10, and each symbol library holds every symbol its
    schematics use. VCS's 65C02 and 65C22 had wrong pin types; ACE's are now
    in all five. Unused DS01C-254-L-08BE and Mini-Black removed.
    Every revision's Gerbers and drill files export the same before and after.
    DRC is unchanged; ERC loses six missing-symbol warnings. Production files
    for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
2026-11-05 BOM: known issue for a silk label that names the wrong part
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2026-11-06 Input and Output Board Rev 1.1; Main Board 1.1's R4 known issue closed
    - Input Board 1.1: the silk says 20pF at C2 and C4 and ATmega1284 at U2.
    The Gerbers match Rev 1.0's on every layer but the front silkscreen, and
    Rev 1.0's top is copied unchanged.
    - Output Board 1.1: J1, the VDD header for a real SID, is removed with its
    track and two vias, and U2 pin 28 is left unconnected, as on the ACE Board
    1.1. The silk says ARMSID at U2. The netlist differs from Rev 1.0's only
    in J1 and pin 28; DRC and parity are as Rev 1.0's. The top is Rev 1.0's
    without the opening over J1.
    - Main Board 1.1, never ordered: R4 has read 10k since the BOM pass, so the
    known issue and the build note tel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
2026-11-06 Main Board: draw the RESB pull-up with the others; README: shared lines
    - Main Board Rev 1.0 and 1.1 schematics: R4, the RESB pull-up, moves from
    the reset circuit beside Q1 into the group with R10-R14, as every CPU
    board draws its pull-ups. Q1's collector runs straight to RESB, as on the
    COB Backplane Pro and Clock Card. A schematic change only: both netlists
    are identical to before, and parity with each PCB is unchanged.
    - README: a Shared lines section, the same in all five KiCad repos. One
    10k pull-up per bus line, on the board with the CPU, and none elsewhere.
    - The LightBurn files for the Input and Output Board Rev 1.1 tops.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
2026-11-06 Schematics: bus connectors drawn one way; README: extra pins and HRDB
    Every 6502 bus, cart and card connector on every schematic, made revisions
    included, is drawn one way: a short wire and a global label on each used
    pin, a no-connect flag on each unused one, GND and VCC as global labels,
    and label shapes fixed per signal as the CPU sees it. Bus lines, bus
    entries and local labels for the bus are gone, which clears every "local
    and global labels have same name" ERC warning. Labels match the silk.
    Where bus pins 4 and 6 carry EXP1 and EXP0, or a cartridge grounds them, a
    note on the schematic says what HRDB (High ROM disable bar) does with them.
    The README's new Extra pins section explains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
2026-11-06 Main Board 1.1: no jumpers, it runs when plugged in; Output Board 1.1: JP1 open
    The VCS is the family's game console: plug in USB power and a cartridge,
    and it runs. The Main Board Rev 1.1, never made, is fixed in place:
    - Bus pins 4 and 6 on J9 and J10 are wired to HRDB, as on the ACE and the
    KIM. J5 (HRDB EN), JP3 and JP4 are gone; the silk by J10 says HRDB.
    - J8 (EXP EN), J7 and JP5 (original 6502), J2, JP1 and R1 (ROM write),
    J1 and JP2 (power switch) and J6 and JP6 (clock enable) are gone. USB
    power reaches D1 directly, the oscillator drives PHI2, the ROM's /WE is
    on VCC and VPB is unconnected. Their silk goes too.
    - Routed by the owner. A 0.6/0.3 via stitches a ground island ar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
2026-11-07 Schematics: label shapes follow the signal
    Every global label's shape now shows which way the signal flows at the
    pin it is drawn on: output where it is driven, input where it arrives,
    bidirectional where both, passive for VCC and GND. A bus connector takes
    the board's view: on a board that drives the bus (a CPU board, a
    backplane) the addresses, RWB, SYNC, PHI2 and RESB flow into it and the
    interrupt and control lines come out; on a card a signal flows into the
    edge only if the card drives it (a clock, a reset, an interrupt through
    its diode and jumper) and out of it otherwise.
    The connector redraw had given each label one shape per signal name, so
    address, RWB and PHI2 labels at chip inpu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
2026-11-07 Schematics: keyboard circuit, 74C922 and level shifter labels by signal flow
    The keyboard circuit around the ATmega1284 is labelled as on the ACE
    wherever it appears: the ATmega strobes the matrix on PB and reads PA,
    drives CA1 and CB1 and reads CA2 and CB2; the VIA's port pins and the
    headers carrying its port are bidirectional; a KEYBOARD header takes PB
    in and gives PA out at the encoder, and the reverse at the keyboard's end.
    The 74C922's Y1 and Y2 are inputs: it scans on X and reads on Y.
    VGA Card Pro: INTB_3V3 at Q1's source is an input, from the Pico, which
    drives the interrupt. The check had read Q1's pins in the wrong place.
    No connection changed: each netlist and ERC result is t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
2026-11-07 Schematics: drawn as KiCad draws by default
    - Every GND symbol shows its name, 3.81 mm below it, as KiCad places a new
    one: 128 hid it and most sat at 5.08 mm, an older default. Three moved
    aside by hand stay; one on the DEV Board sits left to clear a label.
    - A global label at 270 degrees is right-justified, as KiCad writes it, so
    the cart GND labels no longer lie over their own tie wire (ROM Cart,
    Flash Cart, Keypad Card).
    - CPU Card 1.0, 1.1 and Main Board 1.0: "Jumper ... for original 6502" is
    text on the sheet, spelled right, not a field on the jumper; the field
    is gone from the schematic and the PCB footprint. The schematic-to-PCB
    check is unchanged and every Gerber layer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
2026-11-07 README, BOM, REVISIONS: which revision to make, and the off-board headers
    Every revision now carries one of three labels, with a one-line reason:
    Tested, Proven design (not built at this revision, but its circuit is a
    tested revision's) or Untested. REVISIONS.md shows it in place of the old
    Tested column, BOM.md beside each revision, and a new README section,
    "Which revision to make", gives each board's newest revision and its label.
    All three are generated from one data file, so they can't disagree.
    A new README section, "Off-board headers", says what the small headers such
    as RESET SW, CLOCK ENBL SW, POWER LED and VCC are for: building a board into
    a case, with the case's parts wired to t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
2026-11-07 Tools/cad/: generate a machine's plate, mounting drawing and STL
    make.py writes CAD/Bases/Plate.svg, the mounting drawing and Plate.stl
    from CAD/Assembly.json, and --check, run by derived-check.py, fails when
    any is out of date. setup.sh makes the build123d venv the STL needs. This
    repository has no assembly file yet (CAD.md C7).
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2026-11-08 Tools/cad/: openings for ribbon-cable box headers; no loose acrylic
    Every box header for a ribbon cable (bus or GPIO) gets a 1.5 mm opening, as
    its plug comes up through the top (owner). A piece of a top that would hold
    no mounting hole is dropped into the opening round it, with a note.
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2026-11-09 Tools/cardedge/: one card edge for every card and cart (KICAD.md K28a) standard.json says it once: the card and cart outlines, placed by the fingers; a cart's four shell holes, each pair centred; no 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
    The library's 6502 Card Edge loses F.Paste and B.Paste, so n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
2026-11-09 Tools/cardedge/: cart holes at 5.0 and 13.0 mm; refilled pours are Proven
    The owner's ruling (KICAD.md K28): a cart's M3 holes go 5.0 mm from the top
    edge and the sides, its M2 holes 13.0 mm from the sides, each pair centred.
    They were 4.849 and 4.95 mm from the sides, a slip in Fusion 360. Proven
    design now covers pours refilled with DRC and the netlist check passing, as
    moving a card's outline refills its pours.
    The cart shell's posts are still at the old holes: VCS|Cart Enclosure is
    pending in Tools/data/cardedge.json until the shell is fixed in Fusion and
    its STEP exported again.
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2026-11-09 Board images: bare FR4 in its own colour, so a card's bare tab shows
    render.py drew the core with no colour, so KiCad showed bare board almost
    as dark as the black mask, and the cards' new mask-free tabs couldn't be
    seen. The core is now FR4 natural, which shows wherever there's no mask: a
    card's tab, and the thin ring where the mask stops short of a pad. Every
    image is rendered again; the masked areas are unchanged.
2026-11-09 Flash Cart and ROM Cart: a new Rev 1.1 for one card edge (KICAD.md K28c)
    Each a copy of its made revision (the ROM Cart's from 1.0a, the AT28C256
    cart) with Tools/cardedge/ applied: no solder mask on the tab, front or
    back, from the fillets' ends down; no paste on the fingers; the outline
    redrawn to the one cart shape around the fingers (moved 0.04 mm, corners
    5 mm, width 81.8 mm); and the shell's four holes at their nominal places,
    moved by up to 0.18 mm. No track, pad or via moved: gproof.py --no-fill
    against the made revision shows copper unchanged, and the mask, drill,
    courtyard and fab changes only at the tab and the four holes. DRC: no
    errors, nothing unconnected, parity clean.
    ROM Ca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
2026-11-09 Interrupt jumpers: one rule, and the Output Board's build note
    The Shared lines paragraph on interrupt outputs (as in all five repos).
    jumpers.json words the Input and Output Boards' jumpers by part type, and
    no longer calls the Output Board 1.1's open JP1 bridged. The Output Board
    1.1's label names JP1 shipping open, and BOM.md gains "Building a Rev
    1.0: cut JP1", which was only in the README's table. Tools as in the
    other repos: jumper.py, and gen_bom.py's ROM Cart 1.1 silk column.
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2026-11-09 flow.py: a jumper to a rail sets a level; it drives nothing
    The card-edge PHI2 label on the Video Card pointed the wrong way, and
    derived-check passed it. flow.py took any jumper to VCC or GND for a
    source: JP2, which can tie U4's enable to VCC, sits behind JP1 on the
    PHI2 net, so the card seemed to drive PHI2 out to the bus. A jumper to a
    rail is now a pull-up or -down, as a resistor is, whether it ships open or
    bridged; a switch to a rail (a reset button) still drives. The rule in
    KICAD.md K25 is unchanged.
    That flipped both PHI2 labels on every card with a PHI2-enable jumper
    pair, made revisions included: COB RTC Card, VERA Helper and VGA Card
    1.0 and 1.1, VGA Card Pro 1.0, Video Card 1.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
2026-11-09 The cards' PHI2 jumper pairs: gone from the revisions not yet made
    Each card's 74HC138 (74LVC138 on the VGA Card Pro) turns RWB and the card
    select into its read and write strobes, and one jumper fed PHI2 to its
    enable E2 while the other could tie E2 high. PHI2 there, as every card
    ships and was tested, keeps the strobes inside PHI2 high, when the
    6502's address and data are valid; tied high they would span the whole
    cycle and glitch while the address settles. So the revisions not yet made
    wire PHI2 straight to E2, with jumper.py remove: the bridged jumper is a
    track where its copper strip was, the open one goes with its feed from
    the supply, and the PHI2 label sits beside E2. Netlist, DRC,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
2026-11-10 BOM: the Flash Cart is hard to build by hand, and which flash parts fit
    U1 and U2 are 0.5 mm TSOPs. The first hand-built Rev 1.0 carts needed rework at
    U1 and U5 before the chip would take a command, and a blank chip reads $FF
    whatever its address and write pins do, so those faults hide until 6502-flash id.
    JLCPCB assembly is the preferred route. The flash note now lists every -TU grade
    that fits, and JLCPCB's part for the listed one (LCSC C43083883).
2026-11-10 BOM: what the 1MB Flash Cart's bring-up added to the build note
    The second hand-built cart needed rework at U3 and U6 as well, where a bad
    joint left the bank-select line FA13 floating, and it passed 6502-flash id in
    some runs and failed in others until it was right. So the checklist names U3,
    U5 and U6, and says to run id several times rather than once.
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2026-11-11 Main Board 1.1: U5, the RB/WB gate, is a 74HCT00
    P11 (2026-11-11): the KIM built on this board misread at 2 MHz with its Alliance RAM;
    in the ACE a 74HCT00 in the same gate cured it, reads and writes. Fixed in place: Rev
    1.1 is drawn and never made, and Rev 1.0 keeps its 74HC00. TI SN74HCT00DR, LCSC C6764
    (1,874 in stock; Nexperia's 74HCT00D had 36). Same footprint; no track moved.
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2026-11-13 Silkscreen: no JLCPCB order-number marker on the boards not yet made
    JLCPCB stopped printing order numbers in May 2026, and its help page now asks
    for no JLCJLCJLCJLC text on the silkscreen. The text is removed from every
    revision not yet made; Gerbers prove only F_Silkscreen changed. Made revisions
    keep theirs, which JLCPCB ignores.
    Tools: audit.py fails on the marker on a revision not made or ordered,
    table.py shows it in CONSISTENCY.md's Names on silk, and newrev.py drops it
    when it copies a made revision. Synced from 6502-COB.
2026-11-13 ROM Cart 1.1: either ROM chip, through two solder jumpers; 2.5 mm capacitors
    Drawn in place: Rev 1.1 was never made.
    - JP1 and JP2, three-pad solder jumpers, both bridged 1-2 (28C) as made.
    JP1 puts U1 pin 1 on A14 (AT28C256) or VCC (the AT27C256's VPP); JP2 puts
    pin 27 on VCC (the AT28C256's /WE, held high) or A14 (AT27C256). On 28C the
    cart is wired as Rev 1.0a; on 27C as Rev 1.0b, but with VPP on VCC, which
    the AT27C256R datasheet (0014O) allows for reading. The shipped setting is
    the safe one: an AT27C256 in it reads the wrong half, where an AT28C256 on
    27C would have /WE on A14 and could be overwritten.
    - U1 reads AT28C256 / AT27C256; each jumper's ends are marked 28C and 27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
2026-11-13 Tools/README: how to script a board with pcbnew without crashing it
    KiCad 10.0.3's pcbnew segfaults when a script reads objects after a
    board.Remove(), often at Python's shutdown, and macOS shows a crash window
    (2026-11-13, during the ROM Cart 1.1 work; the same on 2026-11-02 and
    2026-11-06). The rules: read first and remove last, end with os._exit(0)
    after saving, hold the board, and never call WriteDRCReport.
2026-11-13 README: the DEV Board owns RESB; table.py accepts its missing pull-up
    The DEV Board stands in for a Main Board and owns reset: its Teensy
    drives RESB out through U3, so it has no RESB pull-up, and a DEV goes
    only on a passive backplane (owner, 2026-11-13). Shared lines now says
    so, and table.py accepts the missing pull-up by name. ACCEPT now applies
    to the Pull-ups column too.
2026-11-13 Production files: one set of settings, one plugin, and a check
    The headless runner behind regen.py hard-coded the Fabrication Toolkit's
    AUTO TRANSLATE off, while every board's options file, which the plugin's
    window reads, has it on. AUTO TRANSLATE applies JLCPCB's rotation fixes for
    SOIC, SOT-23, TSSOP and similar packages, so the placement files of 21
    revisions not yet made (and the RAM Card 1.1, regenerated after its routing)
    gave surface-mount chips rotated 90 to 180 degrees from what JLCPCB's
    assembly needs. Nothing made or ordered came from them.
    - Tools/production/ replaces Tools/bom/toolkit.py: options.json is the one
    set of settings, written byte for byte into every revision's fo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
2026-11-14 IC designators and values: at the chips' ends; SMD values hidden
    On every revision not yet made, an IC's designator and value sit centred at
    the short ends of its footprint (aligned to an end's edge where the centre is
    taken). A through-hole IC shows its value; a surface-mount IC hides it, as the
    owner ruled from the renders: they don't fit. A ZIF socket is measured from its
    silk outline. audit.py checks the values (KICAD.md K36). Every board proved
    silk only with gproof.py.
    Input Board, Main Board and ROM Cart 1.1 moved (Main Board U2 by pin 1, clear
    of R2); the Main Board 1.1's U3 value back on the silk from F.Fab; the Flash
    Cart 1.1 hides its eight.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
2026-11-14 Board logos generated from Bebas Neue (K32)
    Tools/logos/generate.py draws a board logo from the font's own outlines:
    "6502" at the logo's height H (the digits' 720 font units, overshoots
    included), the board's name in capitals at half that scale, centred on
    the digits, 0.16 H after the 2, with the font's spacing and kerning. The
    design was measured from the 50 traced footprints (design.json); 44
    matched it to within 0.004 H. The font is the copy the DOCS and the
    KIMulator ship, with its licence (OFL.txt).
    Every footprint in the 6502 Logos libraries is now drawn by it, named
    "6502 <Board> Logo <H>mm", its origin at the centre of the printed
    shapes, its picture in CAD/Logos/<Board>/6502 <Boar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
2026-11-14 CAD/Logos: remove the Affinity Designer logo file
    Tools/logos/generate.py draws every board logo and its PNG from Bebas
    Neue since K32, so the Affinity file is no longer the source, and it no
    longer matches the six logos the owner ruled onto the design.
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2026-11-14 Tools: a made revision can be replaced by a newer design (K39)
    orders.json gains "replaced"; register.py names the made boards and
    their Tindie stock on the drawn revision that took their number, in
    place of a hard-coded Backplane Pro 1.1. apply.py drops the old
    Backplane Pro 1.1 R5 entry, a part the new 1.1 doesn't have. Synced to
    all five.
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

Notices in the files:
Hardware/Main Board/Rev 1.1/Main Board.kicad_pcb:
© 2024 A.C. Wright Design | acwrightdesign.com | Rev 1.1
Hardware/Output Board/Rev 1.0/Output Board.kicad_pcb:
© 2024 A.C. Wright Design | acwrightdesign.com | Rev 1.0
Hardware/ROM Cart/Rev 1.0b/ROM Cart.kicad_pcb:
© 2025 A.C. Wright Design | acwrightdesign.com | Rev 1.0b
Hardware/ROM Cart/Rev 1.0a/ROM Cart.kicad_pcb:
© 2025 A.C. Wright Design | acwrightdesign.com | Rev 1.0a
